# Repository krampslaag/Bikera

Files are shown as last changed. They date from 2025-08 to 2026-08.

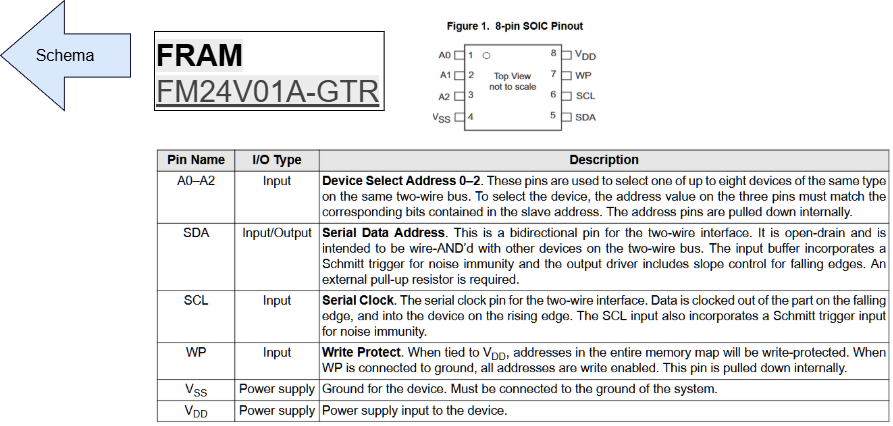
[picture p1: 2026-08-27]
Architectuurschema export png/Architectuur schema-FRAM.drawio.png

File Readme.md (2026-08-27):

# Bikera PCB
Ontwerp van een prototype development board voor een beveiligd IoT-fietsslot
--
Een prototype wordt ontwikkeld in de vorm van een development board met een custom PCB-ontwerp in KiCad. Het doel is een energiezuinig, veilig en uitbreidbaar embedded platform te ontwerpen dat later kan evolueren naar een functioneel eindproduct.
# Componenten:
- Energiezuinige MCU: [STM32L431CCT6TR](https://www.digikey.be/nl/products/detail/stmicroelectronics/STM32L431CCT6TR/8257907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)
- LoRa module (+BLE): [WisDuo RAK11720](https://www.digikey.be/nl/products/detail/rakwireless-technology-limited/RAK11720-8-SM-I/26861631) 
	- Bijhorende LoRa antenne: [FPC antenne](https://be.farnell.com/te-connectivity/l000551-05/rf-antenna-863-to-870mhz-2-2dbi/dp/4457734)
	- Bijhorende BLE antenne: [AANI-FB-0086-0100W (100mm)](https://www.digikey.be/nl/products/detail/abracon-llc/AANI-FB-0086-0100W/25558929)
- ECC secure element: [ATECC608B-SSHDA-T](https://www.digikey.be/nl/products/detail/microchip-technology/ATECC608B-SSHDA-T/13415162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)
- GPS/GNSS module: [Quectel LC76GPAMD](https://www.mouser.be/ProductDetail/Quectel/LC76GPAMD?qs=vvQtp7zwQdMfDuCTmjRUww%3D%3D)
	- Bijhorende antenne: [YFGA003AA](https://www.digikey.be/nl/products/detail/quectel/YFGA003AA/21273116)
- ePaper module: [Waveshare 1.54” module](https://www.waveshare.com/1.54inch-e-Paper-Module.htm)
	%%voor QR codes%%
- Accelerometer: [LIS2DW12 module](https://www.tinytronics.nl/en/sensors/acceleration-rotation/dfrobot-fermion-triple-axis-accelerometer-spi-i2c-lis2dw12)
- SD-kaart module: [SD adapter module](https://www.tinytronics.nl/en/data-storage/modules/sd-card-adapter-module-3.3v-5v)
	%%Voor logging (alleen prototype)%%
- FRAM geheugen: [FM24V01A-GTR](https://www.digikey.be/nl/products/detail/infineon-technologies/FM24V01A-GTR/5210532)
	%%Voor logging%%
- BMS-systeem
	%%voor 2-4 18650 Li-Ion batterijen%%
	- Li-ion protectie en lader (USB-C): [BQ25630YBGR](https://www.digikey.nl/nl/products/detail/texas-instruments/BQ25630YBGR/28738812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)
	- 3.3V buck-boost: [RAA2361052GNP#HC5](https://www.mouser.be/ProductDetail/Renesas-Intersil/RAA2361052GNPHC5?qs=olJun0bQHM%2FTMxAlNSaKDw%3D%3D)
	- 3.3V LDO:[TCR3UG33A,LF](https://www.mouser.be/ProductDetail/Toshiba/TCR3UG33ALF?qs=0lQeLiL1qyaZy60Q7HF0yg%3D%3D)
		%%Voor GPS%%
	- 5V boost: [TPS61253F](https://www.digikey.be/nl/products/detail/texas-instruments/TPS61253FYFFR/29174815)
		%%Voor servomotor%%
- Servo motor: [TD-8120MG Digital Servo](https://www.tinytronics.nl/en/mechanics-and-actuators/motors/servomotors/td-8120mg-waterproof-digital-servo-20kg)
	%%Aangesloten met pinheader%%
- Hall effect sensors: [](https://www.mouser.be/ProductDetail/Texas-Instruments/DRV5032DULPGM?qs=OlC7AqGiEDk9MwfBkgsRPw%3D%3D)[DRV5032DULPGM](https://www.mouser.be/ProductDetail/Texas-Instruments/DRV5032DULPGM?qs=OlC7AqGiEDk9MwfBkgsRPw%3D%3D)
	%%voor slot beugel en pin%%
- Kleurled: [](https://www.digikey.be/nl/products/detail/american-bright-optoelectronics-corporation/BL-BEG204-7-E/22486902)[BL-BEG204-7-E](https://www.digikey.be/nl/products/detail/american-bright-optoelectronics-corporation/BL-BEG204-7-E/22486902)
	%%rood en groen, zonder blauw%%
## BOM
Er wordt een **materiaallijst (BOM)** opgesteld met alle gebruikte componenten in [google sheets](https://docs.google.com/spreadsheets/d/1ZxJHOLqpuJL-1dvZkRNnV-r1_EjUXDaZgLNVo9UeM5s/edit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).

Er staat een **sheet 'Basiscomponenten'** met verschillende opties voor elk component, aangeduid welke voor prototype gebruikt worden en welke voor finaal ontwerp kan gebruikt worden. 

De keuzes voor het prototype zijn overgenomen naar de **sheet 'Componenten'**, waar ook alle randcomponenten zijn toegevoegd. De opmaak gebeurt automatisch en prijzen van Mouser, Digikey en Farnell kunnen via API's opgehaald worden met een script. Ook de status 'niet op voorraad' wordt ge-update waarbij de prijs automatisch roodgekleurd wordt. Vanboven is er een menu Bikera met eigen functies, ook gelinkt aan knoppen.

- [!] Prijzen automatisch updaten duurt lang omdat er te veel requests per minuut zijn waar het script op moet wachten. Nu komt het probleem 'exceeded maximum execution time'. Er mist ook nog een API-key voor Farnell.

Met tag 'alternatief' in de kolom 'type' kunnen verschillende opties voor hetzelfde component van een andere distributeur worden toegevoegd. Opties kunnen worden overgeslagen met de tag 'skip' bij de kolom 'status.' Er wordt automatisch aangeduid met lichtgele vakjes wat er nog moet ingevuld worden, geel waar een dubbele vraagteken in de tekst staat en rood waar een uitroepteken staat. Rijen worden groen gekleurd met de tag 'in KiCad' in kolom 'Status', om te zien welke componenten overeenkomen met het schema.

De componenten worden ook automatsich gedestilleerd in de **sheet 'BOM'**, waarbij gelijke componenten worden opgeteld. Met een knop wordt deze sheet gesorteerd per type.

De **sheet 'Architectuur'** werd gebruikt om het architectuurschema op te stellen en de sheet 'Lijsten' bevat opties voor dropdownmenus.

# Afspraken
- PCB ontwerp in KiCad
- De End-of-Life (EOL) van de componenten mag minimaal nog vijf jaar zijn.
- Prototype = developer board
    - Met debugconnectoren
    - Eerste versie als datalogger
    - Met hand soldeerbare componenten
- RTC
	- Updaten via LoRa
	- Eventueel aparte (oplaadbare) knoopcel
- ECC chip:
	- Met socket
	- ethereum: Keccak-256
	- solana: Ed25519 
- RAK11720 = LoRa +BLE 5, geen bluetooth apart
- Zowel geheugenchip (FRAM) als SD-kaart voor logging
- BMS 
	- Op PCB
	- Lader detecteert USB protocol (2.0, 3.0, USB-C) en past de laadstroom aan.
	- 3.3V buck-boost voor de meeste componenten
	  -> dan kan batterijspanning kan zakken tot 3V
	- 3.3V LDO regulator voor GPS (weinig ruis)
	- 5V boost voor servomotor
- Servomotor
	- aan/uit met enable pin van 5V boost
	- sense weerstand om blokkage overstroom te detecteren
- Hall sensors
	- THT
	- één voor noordpool en één voor zuidpool (beugel en pin) om manipulatie tegen te gaan
- LED
	- Rood + groen -> geel en oranje kan ook gemaakt worden
## Opties voor prototype
- Antenne
	- LoRa & bluetooth: FPC antenne met MHF4 connector
	- Verschillende LoRa antennes testen
	- GPS: FPC antenne 
		- -> kabel proberen solderen
		- anders extra RF-1 connector (quectel GPS heeft RF pinout)
- E-ink module i.p.v. paneel
- SD module
- Accelerometer op breakout bord
- Twee gelijke hall sensors is ok
- RTC updaten via LoRa
- JST PH connectors i.p.v. dupont headers (zelf krimpen)
## Opties voor latere ontwikkelingsfases
- kleinere componenten (reflow soolderen)
- STM32WL als MCU en LoRa radio
- 2 versies: zonder en met bluetooth? (2 RAK lora modules)
- RAK11720: RF pinout versie:
    - Draadantenne: dipool in V-vorm
    - BLE antenne op PCB
- Draadantenne of patch antenne proberen voor GPS
- [NXP EdgeLock SE050](https://www.mouser.be/new/nxp-semiconductors/nxp-edgelock-se050/): meer geavanceerde ECC chip
- Accelerometer chip in plaats van breakout bord
- Unipolaire hall sensors: één voor noordpool en één voor zuidpool (beugel en pin)
- Eventueel aparte (oplaadbare) knoopcel voor RTC (STM32 VBAT)

# Stand van zaken
## In grote lijnen
- [x] Basiscomponenten uitzoeken
- [x] Randcomponenten en deelcircuits
- [ ] Materiaallijst
	- [x] Basiscomponenten (google sheets)
	- [x] Randcomponenten
	- [/] Volledige BOM
- [x] Architectuurdocument
	%%Schema in drawio%%
- [x] KiCad schema
- [ ] KiCad PCB layout
## Componenten uitzoeken
- [x] STM32 *STM32L431CCT6TR*
- [x] LoRa *RAK11720*
- [x] EEC chip *ATECC608B-SSHDA-T*
	- [x] Breakout bord
	- [x] IC voet
- [x] GPS Quectel *LC76GPAMD*
	- [x] Randcomponenten
- [x] BMS
	- [x] li-ion lader *BQ25630YBGR*
		- [x] Randcomponenten
	- [x] 3,3V buck-boost *RT6158AWSC*
		- [x] Randcomponenten
	- [x] 3,3V LDO regulator *TCR3UG33A,LF*
		- [x] Randcomponenten
	- [x] BMS - 5V boost *TPS61253F*
		- [x] Randcomponenten
	- [x] USB-C connector
- [x] Hall effect sensor *DRV5032DULPGM*
- [x] ST-link
	- [x] St-link *STLINK-V3MINIE*
	- [x] Header *009159010603906*
- [x] FRAM *FM24V01A-GTR*
- [x] ePaper *Waveshare 1.54” module*
- [x] Accelerometer *LIS2DW12 module*
- [x] SD-kaart module  *SD adapter module*
- [x] Servo motor *TD-8120MG Digital Servo*
	- [x] Randcomponenten
- [x] LED *BL-BEG204-7-E*
	- [x] Weerstanden
- [x] Alle randcomponenten uitzoeken, opsommen en controleren
- [x] Laatste correcties -> zie gekleurde vakjes op [spreadsheet Componenten](https://docs.google.com/spreadsheets/d/1ZxJHOLqpuJL-1dvZkRNnV-r1_EjUXDaZgLNVo9UeM5s/edit?usp=sharing)
## KiCad
### KiCad schema
- [x] **Symbolen en footprints importeren**
	- **Bestaand**
	- [x] STM32 *STM32L431CCT6TR
	- [x] LoRa *RAK11720*
	- **Gedownload**
	- [x] GPS *Quectel LC76GPAMD*
	- [x] FRAM *FM24V01A-GTR*
	- [x] BMS - li-ion lader *BQ25630YBGR*
	- [x] BMS - 3,3V buck-boost *RT6158AWSC*
	- [x] BMS - 3,3V LDO regulator *TCR3UG33A,LF*
	- [x] Hall effect sensor *DRV5032DULPGM*
	- [x] ST-link header *009159010603906*
	- **Gemaakt**
	- [x] E-ink module *Waveshare 1.54” module*
	- [ ] Accelerometer *LIS2DW12 module*
	- [x] EEC chip *ATECC608B-SSHDA-T*
	- [x] SD-kaart module  *SD adapter module*
	- [x] BMS - 5V boost *TPS61253F*
	- [x] Servo pinheader *Connector_JST:JST_PH_B3B-PH-K_1x03_P2.00mm_Vertical*
	- [x] LED *BL-BEG204-7-E*
- [x] **Pinout uitzoeken**
	- [x] STM32 *STM32L431CCT6TR*
	- [x] LoRa *RAK11720*
	- [x] EEC chip *ATECC608B-SSHDA-T*
	- [ ] GPS Quectel *LC76GPAMD*
		- [x] Beschikbare pinnen
		- [ ] Optionele verbindingen (zie arch.schema)
	- [x] BMS
		- [x] Eerst deelcircuits
		- [x] li-ion lader *BQ25630YBGR*
		- [x] 3,3V buck-boost *RT6158AWSC*
		- [x] 3,3V LDO regulator *TCR3UG33A,LF*
		- [x] 5V boost *TPS61253F*
	- [x] Hall effect sensor *DRV5032DULPGM*
	- [x] ST-link (header) *009159010603906*
	- [x] FRAM *FM24V01A-GTR*
	- [x] ePaper *Waveshare 1.54” module*
	- [x] Accelerometer *LIS2DW12 module*
	- [x] SD-kaart module  *SD adapter module*
	- [x] Servo motor *TD-8120MG Digital Servo*
	- [x] LED *BL-BEG204-7-E*
- [/] **Schema afwerken**
	- [x] Pagina's verdelen
	- 01_power.kicad_sch
		- [x] Componenten importeren
		- [x] Verbindingen
		- [x] Footprints in orde
		- [x] Gecontroleerd
		- [x] Herschikt
	- 02_mcu.kicad_sch
		 - [x] Componenten importeren
		 - [x] Verbindingen
		 - [x] Footprints in orde
		 - [x] Gecontroleerd
		 - [ ] Herschikt
	- 03_auxillery.kicad_sch
		 - [x] Componenten importeren
		 - [x] Verbindingen
		 - [x] Footprints in orde
		 - [!] Accelerometer footprint
		 - [x] Gecontroleerd
		 - [x] Herschikt
### KiCad PCB layout
- [ ] Strategie uitzoeken (PCB afmetingen, lagen, ground plane, trace width...)
- [ ] Componenten plaatsen
- [ ] Verbindingen
## Realisatie
- Componenten bestellen
- PCB bestellen
- Reflow hot plate zoeken & bestellen/maken
- Solderen
- Testen
- Software ontwikkelen, itereren,...

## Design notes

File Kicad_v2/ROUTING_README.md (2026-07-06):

# Bikera devboard — routing session (2026-07-06)

## What happened
Continued from the 2026-07-05 generated layout. Your two schematic fixes (H3.12,
J7.3→pin 7) were verified present in the saved PCB; U9's open RF pins are fine
(MHF4 on module). The stale `.net` export doesn't matter — the PCB is ground truth.

## Files
| File | What |
|---|---|
| `Bikera PCB devboard_ROUTED.kicad_pcb` | **The routed board** (your saved board + 1386 tracks + 179 vias). Original `Bikera PCB devboard.kicad_pcb` untouched. |
| `Bikera PCB devboard.kicad_pro` | Net classes re-added (they had been lost): Default/Power/BATT/HighSpeed_RF/USB/Plane + 24 patterns. Default clearance now **0.15 mm**. |
| `Bikera PCB devboard.kicad_dru` | Amended: RF width rule now 0.45–0.95 (opt 0.5), WCSP neck-down exceptions for IC2/U1/U2/U4 courtyards. |
| `routed_top.png` / `routed_bottom.png` | Renders of the routed state. |

**To adopt:** open `..._ROUTED.kicad_pcb`, check it, then Save-As over the main
board file (or rename). Fill zones (B) before DRC.

## What is routed
- GND / +3V3 served by In1/In2 planes: every SMD pad stitched with a via (or
  bridged to a nearby plane-connected point); TH pads connect via zone fill.
- WCSP fan-outs (IC2 charger, U1 buck-boost, U2 GPS LDO, U4 boost): same-net ball
  clusters linked, perimeter escapes + radial flares, all 0.4 mm pitch.
- GPS RF feed (U6 → R28/C50/C49/D3 → AE1) on F.Cu, no vias, 0.5 mm wide.
- USB D+/D− (J1 → U7 ESD), +BATT (0.5 mm), power rails (0.35 mm), most signals.

## ⚠ Deliberate deviations
1. **RF feed is 0.5 mm, not the anchors' 0.9 mm.** A 0.9 mm trace cannot attach to
   the 0402 matching network (pads 0.5 mm wide, 1 mm apart) without gross clearance
   violations — the original 0.9 spec is geometrically unsatisfiable there. At
   ~4 mm total feed length the impedance penalty at 1.575 GHz is negligible for RX.
   The `.kicad_dru` and net class were updated to match.
2. **Default clearance 0.15 mm** (was 0.2). Any 4-layer fab handles this (JLC min
   0.09). Needed to fan out the 0.5 mm QFP and 0.4 mm WCSPs.
3. **IC2 balls E4 (TS) and C2 (CHRG_PG)** exit through ~0.05 mm-clearance squeeze
   corridors between balls — unavoidable on a full-matrix 0.4 mm WCSP without
   microvias. Covered by a dru exception inside the courtyards; **confirm your fab
   accepts it or plan to tweak by hand.**

## Update (second pass, same day)
A fine-grid repair pass added the missing +VBUS, GPS_RX, SW-node (C7 snubber),
LORA_BOOT/RX and USB-DN links. An exact-geometry audit then found the automated
router had created several **near-shorts** (traces tunnelling through pad
boundaries — a raster bug); all affected nets were ripped up and rerouted with a
corrected model. **The shipped board now has zero clearance violations outside
the documented WCSP squeeze zones** (verified via-pad / seg-pad / seg-seg at
≥0.09 mm everywhere else).

## ⚠ Still unrouted (~32 nets have a missing link; ratsnest will show them)
Power: +5V, +SYS (2 links), Net-(L2-Pad1/2) (**U1↔L2 buck inductor — must be
routed before power-up**), Net-(D1-K2), one +3V3 cap (C47), one GND cap (C15)
Charger satellites: CHRG_CE/INT/PG, Net-(IC2-TS) (TH1/R8/R9), VBAT_SENSE
Buses/signals: I2C_SCL/SDA branches, SPI1_SCK/MOSI branches, SD_CS, GPS_RESET
(fully open — SW1/R20/C16 chain), GPS_EN, EN_5V_SERVO, EPAPER_CS/RST/BUSY,
LORA_RESET, SWO/SWCLK, ACCEL_INT1, RED/GRN LED, SERVO_RSENSE, HALL_PIN/HALL_BEUGEL.

These sit in the two saturated zones (U3 QFP perimeter, IC2/U1 power cluster).
KiCad's push-and-shove router handles them interactively — it can shove existing
tracks aside, which my router cannot. Expect ~30–45 min by hand.

## Suggested order next
1. Open ROUTED board, **fill zones (B)**, run DRC with the .kicad_dru loaded.
2. Route the ratsnest leftovers (push-and-shove, 0.15 clearance).
3. Re-check the two IC2 squeeze corridors and the RF feed width decision.
4. Hall sensors IC1/IC3 are still edge placeholders — you said route anyway;
   re-route their two nets if you move them.

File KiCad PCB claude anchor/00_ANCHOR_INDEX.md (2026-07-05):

# BIKERA PCB LAYOUT ANCHOR NOTE — MASTER INDEX

## Purpose
This is a **minimal, token-efficient dataset** extracted from your Bikera project files for automated KiCad PCB layout generation using a deep-thinking model (Claude Fable).

**Key principle**: All four pillars are compressed into dense markdown, designed to be pinned as cached context in an LLM. Avoids re-parsing KiCad files, BOM spreadsheets, and schematics on each layout iteration.

---

## 4 PILLARS (Read in Order)

### **01_ANCHOR_GEOMETRY.md** — Board Outline, Mounting, Fixed Components
- Board dimensions (50×30 mm), layer count (4), layer stack assignment
- Mounting holes (4× M3, corner positions with exact X/Y coordinates)
- Fixed connectors & mechanical: USB-C, JST-PH battery, SD-card header, antenna connectors
- Restricted zones (RF keep-outs, digital/analog separation, thermal zones)
- Decoupling capacitor proximity rules (distance from IC pin to bypass cap, critical for power integrity)
- Power distribution summary and critical path rules (trace width, via count)
- Net classes baseline (Default, Power, HighSpeed, Diff-Pair; via sizes & clearances)

**Use this to**: Establish the physical PCB template, define placement zones (A–E), allocate space for connectors.

---

### **02_ANCHOR_CLUSTERS.md** — Component Functional Groups & IC Proximity
- **9 functional clusters** (MCU, Power, LoRa, GPS, ECC, Accelerometer, Storage, LED, Test Points)
- Each cluster lists:
  - Primary IC reference designator & package
  - Bypass capacitor part numbers & values
  - Max distance rules (≤5mm, ≤3mm, ≤2mm cap-to-pin)
  - Support components (resistors, ferrite beads, diodes, buttons)
  - Critical routing constraints (SPI shielding, isolated power domains, etc.)
  - Suggested PCB placement coordinates (approximate)
- Summary table: IC → Cap → Max Distance mapping (quick reference)

**Use this to**: Place components relative to each other, cluster decoupling caps immediately around each IC, enforce power domain isolation (e.g., +3V3_GPS separate until star-point).

---

### **03_ANCHOR_NETLIST.md** — Critical Nets Only (Power, High-Speed, Differential)
- **Power nets** table: +3V3, +3V3_GPS, +5V, +BATT, +SYS, GND; voltage, source, destination, routing strategy
- **I²C bus** (MCU ↔ ECC, sensors, GPS):
  - SDA_I2C1 & SCL_I2C1 nets
  - Pin mappings (U3.PB9, U3.PB8)
  - Pull-up resistor placement (4.7K, ≤10mm from MCU)
  - Length limits (≤100mm), shielding guidance
- **SPI bus** (MCU ↔ LoRa, optionally GPS):
  - SPI1_MOSI, SPI1_MISO, SPI1_CLK, SPI1_CS nets
  - Pin mappings, length limits (≤50mm), GND shielding strategy
- **UART** (MCU ↔ GPS telemetry):
  - UART1_RXD / UART1_TXD nets
  - Low-speed, flexible routing (≤100mm stubs)
- **Antenna RF traces** (50Ω controlled impedance):
  - ANT_LoRa (≤10mm, 0.9mm width, 10mm keep-out zone)
  - ANT_GPS (≤8mm, 0.9mm width, 8mm keep-out zone)
- **GND return paths**: L2 plane continuity, star-point convergence, via-stitching rules
- **Net class assignment table**: Which net class each critical net belongs to

**Use this to**: Route power, data, and RF traces. Implement length rules, impedance targets, and shielding. Enforce antenna keep-out zones.

---

### **04_ANCHOR_NETCLASSES.md** — Design Rules & Constraints by Net Class
- **6 net classes defined**:
  1. Default (GPIO, low-speed logic) — 0.2mm track, 0.2mm clearance, 0.6mm via dia
  2. Power (+3V3, +5V, +BATT) — 0.5mm track, 0.25mm clearance, 0.8mm via dia
  3. HighSpeed_SPI (LoRa/GPS SPI) — 0.2mm track, GND shielding every 2–3mm
  4. HighSpeed_I2C (ECC/GPS/Accel I²C) — 0.2mm track, 4.7K pull-ups at MCU, ≤100mm bus length
  5. HighSpeed_RF (ANT_LoRa, ANT_GPS, 50Ω) — 0.9mm width, 10mm/8mm keep-outs, via-stitched GND returns
  6. GND (L2 continuous plane) — 95% board coverage, antenna exclusions, star-point return
- **Layer assignment** (L1 signals, L2 GND plane, L3 power plane, L4 signals/power distribution)
- **Impedance calculation** (50Ω target for RF: 0.9mm trace width on 0.2mm L1–L2 spacing)
- **Manufacturing specs** (1.6mm FR-4, 1oz copper, 6mil min trace/space, solder mask both sides)
- **DRC checklist** (clearance, trace width, via rules; antenna keep-outs manual inspection)
- **Validation checklist** (pre-fabrication sign-off tasks)

**Use this to**: Apply DRC rules in KiCad, assign net classes to each net, measure final trace impedances (RF critical), approve board for fabrication.

---

## HOW TO USE WITH FABLE (Deep-Thinking Model)

### **Workflow**
1. **Pinned Context** (token-efficient):
   - Save this anchor note set as 4 short markdown files (each ≤15KB)
   - In your deep-thinking prompt, include these files as cached context ("pin" or "remember" in the system message)
   - Each file is independently useful; together they define the complete layout constraint set

2. **Fable Prompt Template**:
   ```
   # TASK: Auto-generate KiCad PCB layout for Bikera devboard
   
   **CONTEXT (cached, these 4 files):**
   - 00_ANCHOR_INDEX.md (this file)
   - 01_ANCHOR_GEOMETRY.md
   - 02_ANCHOR_CLUSTERS.md
   - 03_ANCHOR_NETLIST.md
   - 04_ANCHOR_NETCLASSES.md
   
   **INPUTS:**
   - Schematic netlist: [paste KiCad netlist.net export]
   - Component footprints: [paste list of references + footprint names]
   
   **TASK:**
   Generate a KiCad layout (.kicad_pcb file) that:
   1. Places components in clusters A–E (01_ANCHOR_GEOMETRY)
   2. Routes all critical nets per 03_ANCHOR_NETLIST
   3. Applies design rules from 04_ANCHOR_NETCLASSES
   4. Enforces antenna keep-out zones (10mm LoRa, 8mm GPS)
   5. Implements GND star-point at (44mm, 5mm)
   6. Reports any DRC violations found
   
   **CONSTRAINTS:**
   - Board: 50×30 mm, 4-layer
   - Minimize trace length (SPI ≤50mm, I²C ≤100mm)
   - Keep decaps ≤5mm from IC VDD pins
   - RF traces 50Ω impedance (0.9mm width on L1)
   ```

3. **Fable Output**:
   - `.kicad_pcb` file (human-readable, text-based KiCad layout format)
   - Trace dump report (success/failures for each net)
   - DRC violations (if any)

4. **Manual Review**:
   - Import generated `.kicad_pcb` into KiCad PCBnew
   - Run KiCad's DRC (target: 0 errors)
   - Visually inspect antenna keep-outs, GND plane continuity, trace routing
   - Iterate with Fable if needed ("move component X to (10, 15); re-route SPI bus")

---

## QUICK REFERENCE

### Cluster Placement (Zones)
| Zone | X range (mm) | Components | Purpose |
|---|---|---|---|
| A | 0–15 | U3 (MCU), SW1, SW2, C14/C15/C16 (decaps) | Core MCU and logic |
| B | 15–32 | U6 (GPS), U5 (ECC), accel breakout, C29/C30, C27 | Sensors & crypto |
| C | 32–42 | U9 (LoRa), C37/C38/C39, MHF4 antenna | RF module |
| D | 42–50 | JST-PH, BMS chips (RT6158A, BQ25630), LDO, C41 (bulk) | Power management |
| E | Y≤5mm | USB-C, SD-card header | Connectors |

### Critical Distances
- **MCU VDD caps**: ≤5mm pad-to-pin (C14/C15/C16 to U3 VDD pins)
- **MCU VDDA caps**: ≤3mm pad-to-pin (C17/C18/C40 to U3 VDDA pins)
- **LoRa VDD caps**: ≤4mm (C37/C38/C39 to U9 VDD)
- **GPS VDD/V_BCKP caps**: ≤4mm (C29/C30 and C33/C34 to U6 pins)
- **I²C pull-ups**: ≤10mm from MCU I²C pins (U3.PB8/PB9)

### Antenna Keep-Outs (No GND Plane)
- **LoRa MHF4**: 10mm radius, center at MHF4 connector pad
- **GPS FPC**: 8mm radius, center at FPC connector pad

### Power Star-Point
- **Location**: (44mm, 5mm) — bulk cap cluster bottom-right
- **Convergence**: All power IC returns (BMS, LDO, charger) via multi-via (≥5× 0.3mm vias) to L2 GND plane
- **Fan-out**: From star-point, +3V3 and +3V3_GPS trees radiate upward/leftward to MCU and LoRa clusters

### Net Classes (Summary)
| Class | Track Width | Clearance | Via Dia | Key Nets |
|---|---|---|---|---|
| Default | 0.2 | 0.2 | 0.6 | GPIO, buttons, LED, debug |
| Power | 0.5 | 0.25 | 0.8 | +3V3, +BATT, +5V, +SYS |
| SPI | 0.2 | 0.2 | 0.4 | SPI1_MOSI/MISO/CLK/CS |
| I²C | 0.2 | 0.2 | 0.5 | I2C_SDA/SCL |
| RF | 0.9 | 0.5 | 0.4 | ANT_LoRa, ANT_GPS (50Ω) |
| GND | N/A (plane) | 0.2 (edge) | 0.3 | L2 continuous plane |

---

## FILE LOCATIONS
All files saved to: `D:\Obsidian git\AI\AI collaboration\KiCad PCB anchor`

```
00_ANCHOR_INDEX.md                 ← You are here
01_ANCHOR_GEOMETRY.md              ← Board outline, zones, connectors
02_ANCHOR_CLUSTERS.md              ← Component grouping, cap proximity
03_ANCHOR_NETLIST.md               ← Critical nets (power, SPI, I²C, RF)
04_ANCHOR_NETCLASSES.md            ← Design rules, trace widths, clearances
Bikera PCB devboard.net
```

---

## MAINTENANCE & UPDATES

**If you change the schematic (add/remove components)**:
1. Re-extract the component list from `D:\Obsidian git\AI\AI collaboration\Files\Bikera.xlsx` sheet "Componenten"
2. Update clusters in `02_ANCHOR_CLUSTERS.md` (add/remove ICs and caps)
3. Update net names in `03_ANCHOR_NETLIST.md` (grep the new `.kicad_sch` files)
4. Re-run KiCad DRC to validate net classes in `04_ANCHOR_NETCLASSES.md`

**If you change the board size or layer count**:
1. Update board dimensions in `01_ANCHOR_GEOMETRY.md`
2. Recalculate RF trace width (0.9mm assumes 4-layer with 0.2mm L1–L2 spacing; may differ for 2-layer or 6-layer)
3. Adjust zones (A–E) accordingly

**If you add RF modules (e.g., BLE antenna on 2.4 GHz)**:
1. Add new RF net class to `04_ANCHOR_NETCLASSES.md` (e.g., HighSpeed_RF_2400MHz with tighter tolerance)
2. Document antenna keep-out zone (smaller for higher frequency)
3. Add to `03_ANCHOR_NETLIST.md` netlist

---

## NEXT STEPS

1. **Immediate**: Share these 4 anchor files (00–04) with Fable as cached context
2. **Short-term**: Export KiCad netlist (File → Export → Netlist), pass to Fable with anchor files
3. **Layout generation**: Fable generates `.kicad_pcb` file; import into KiCad PCBnew
4. **Validation**: Run DRC, inspect antenna zones, verify GND plane continuity
5. **Iteration**: If Fable-generated layout has issues, adjust anchor constraints and re-generate

---

**Created**: 2026-07-05  
**Project**: Bikera PCB devboard (50×30 mm, 4-layer, STM32L431 + LoRa + GPS)  
**Target Tool**: KiCad 10.0 (or later)  
**Model**: Claude Fable 5 (deep-thinking, layout generation)  

---

## NOTES FOR FABLE

When generating the layout:
- **Respect zones**: Don't place MCU (U3) in Zone C or D; keep it in Zone A
- **Antenna isolation**: Treat 10mm/8mm keep-outs as hard constraints; no exceptions
- **Power first**: Route +BATT → BMS → LDO → bulk cap → MCU before routing signals
- **Layer assignment**: All SPI on L1; I²C can flex to L4 via vias if needed; RF never leaves L1
- **Via-stitching**: Implement along SPI traces (GND via every 2–3mm for shielding)
- **Report each stage**: After placement, after power routing, after signal routing—so we can catch issues early

---

**Good luck with the layout!** 🎯

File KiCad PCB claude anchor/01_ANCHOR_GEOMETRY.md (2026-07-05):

# BIKERA PCB LAYOUT ANCHOR NOTE
## Step 1: Compact Board Geometry

**BOARD OUTLINE & LAYERS**
- Dimensions: 50.0 mm (W) × 30.0 mm (H)
- Layer stack: 4 layers (FR4, standard)
- Layer assignment: L1 (top signal), L2 (inner GND plane), L3 (inner power), L4 (bottom signal)
- Origin: (0,0) at bottom-left corner (KiCad standard)

**MOUNTING HOLES (M3, plated through)**
- TL: (2.5, 27.5)
- TR: (47.5, 27.5)
- BL: (2.5, 2.5)
- BR: (47.5, 2.5)
- Hole diameter: 3.2 mm (M3 clearance), pad ~4.5 mm

**CONNECTORS & FIXED MECHANICAL (Position | Function | Notes)**
- **USB-C (Bottom edge, 50-30 boundary)**: Charging + data. Header at Y≈2mm. Centered X.
- **JST-PH (Battery input)**: X≈5mm, Y≈5mm. 2-pin, vertical orientation preferred for low profile.
- **SD-Card Module Header**: Edge placement (parallel to board edge, prefer bottom or left edge). Header pins at 2.54mm pitch.
- **LoRa Antenna (MHF4 connector)**: U9 (RAK11720) footprint defines position. Reserve antenna keep-out: 5mm clearance minimum from board edge.
- **GPS Antenna Connector**: U6 (Quectel LC76GPAMD). FPC connector, ~10–15mm cable. Position TBD in layout (typically near opposite edge from LoRa).
- **BLE Antenna (FPC, 10cm)**: Abracon AANI-FB-0086. Flexible placement on side.

**TEST POINTS**
- Required per thesis: VDD test points for critical power rails
- Placement: Clustered near bulk capacitors or IC power pins
- Suggested positions: Near U3 (MCU), U9 (LoRa), U6 (GPS), BMS ICs
- Size: 0.8 mm–1.0 mm via pads for probe access

**RESTRICTED ZONES**
1. **RF Keep-outs** (50 Ω antenna traces, no digital noise):
   - LoRa antenna (MHF4) → antenna route: min 2mm traces, keep-out 10mm radius around connector foot
   - GPS antenna → separate 50 Ω stub, keep-out 8mm radius
2. **Digital/Analog Separation**:
   - Analog ground island (GPS, sensors) isolated until single point at bulk GND plane
   - MCU digital side (left half) ⊥ RF/analog side (right half)
3. **Battery & High-Current Paths**:
   - JST-PH traces: low inductance, thick (>0.5mm), direct to BMS
   - USB charging path: short, isolated from signal layers until PD controller
4. **Thermal zones**:
   - Avoid component placement directly above/below voltage converter (BMS) if heat dissipation ≥0.5W
   - Leave ~10mm air gap if needed

**DECOUPLING CAP PROXIMITY REQUIREMENTS**
- **STM32L431 (U3, LQFP-48)**:
  - VDD caps (3×100nF C14/C15/C16, 1×4.7µF C41): ≤5mm pad-to-pin distance
  - VDDA caps (1µF C17, 10nF C18, 100nF C40): ≤3mm to analog pins
  - Ferrite bead FB1 on VDDA: inline, ≤2mm before MCU
- **RAK11720 (U9, MHF4 breakout)**:
  - VDD caps (10µF C37, 1µF C38, 100nF C39): ≤4mm cluster near breakout pads
- **Quectel LC76GPAMD (U6)**:
  - VCC caps (10µF C29, 100nF C30, 33pF C31): ≤4mm cluster
  - V_BCKP caps (4.7µF C33, 100nF C34): ≤3mm cluster
- **ATECC608B (U5, SOIC-8)**:
  - 100nF C27: ≤2mm pad-to-pin

**POWER DISTRIBUTION SUMMARY**
- **+3V3** (main digital): LDO regulated, routes to MCU, LoRa, GPIO peripherals
- **+3V3_GPS**: Isolated LDO for GPS/GNSS module (low-noise requirement)
- **+5V**: USB input or boost output (if needed for future modules)
- **+BATT** (raw battery ~3.7–4.2V from JST): BMS input, high-current sense point
- **+SYS**: Post-BMS regulated (derived from +3V3 or isolated converter)
- **GND**: Single-point star at bulk cap cluster, radiates to layer 2 (ground plane)

**CRITICAL PATHS (minimum width/via rules)**
- Battery input & charging: 0.5mm+ (≥2A expected)
- Power distribution (+3V3, +5V): 0.35mm+ (multi-via at source)
- Signal high-speed (SPI to GPS/LoRa): 0.2mm, 50 Ω where diff-pair used
- Standard signal: 0.2mm
- Ground vias: 0.3mm drill minimum, cluster 5–10 vias per power source

**NET CLASSES (from KiCad .kicad_pro)**
- **Default**: Track 0.2mm | Clearance 0.2mm | Via Ø0.6mm / drill 0.3mm
- **Power**: (assign if needed) Track 0.5mm | Clearance 0.25mm | Via Ø0.8mm / drill 0.4mm
- **HighSpeed**: (for GPS/LoRa SPI) Track 0.2mm | Clearance 0.2mm | Via Ø0.4mm / drill 0.2mm
- **Diff-Pair**: Width 0.2mm | Gap 0.25mm | Via Ø0.4mm

**COMPONENT PLACEMENT ZONES (Spatial allocation)**
- **Zone A (Left, 0–15mm X)**: MCU U3 (LQFP-48 center), Reset button SW1, Boot button SW2, MCU decoupling caps
- **Zone B (Center-Left, 15–32mm X)**: ECC chip U5 (SOIC-8), GPS module U6, GPS caps, ferrite bead FB1
- **Zone C (Center-Right, 32–42mm X)**: LoRa module U9 (RAK11720), LoRa caps C37/C38/C39, pullup/pulldown resistors (R24, R25)
- **Zone D (Right, 42–50mm X)**: Battery connector (JST-PH), resistor divider (R18/R19 for VBAT_SENSE), bulk caps
- **Zone E (Bottom edge, Y ≤ 5mm)**: USB-C connector, SD-card module header
- **Antennas**: FPC feed-through at edges, preferably top edge LoRa, bottom/right edge BLE/GPS

---

**DESIGN NOTES FOR LAYOUT TOOL**
- Fab spec: PCBWay/JLCPCB/Eurocircuits (standard 4-layer, 1.6mm FR-4)
- Min trace/space: 6/6 mil (0.15mm) conservative for 4-layer
- Via tenting: solder mask both sides for reliability
- Silkscreen: Reference designators (0.8mm text), layer indicators
- Edge clearance: Keep traces ≥0.5mm from board edge (except connectors)
- Solder mask: No mask between fine-pitch pads (QFP, SOIC) for reflow control

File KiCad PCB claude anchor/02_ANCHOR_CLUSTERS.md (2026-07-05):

# BIKERA PCB LAYOUT ANCHOR NOTE
## Step 2: Component Functional Clusters

**CLUSTER ORGANIZATION BY SCHEMATIC SUBSYSTEM**

---

### CLUSTER A: STM32L431 MCU & CORE SUPPLY (Zone A: X=0–15mm)
**Primary IC**: U3 (STM32L431CCT6TR, LQFP-48)
**Bypass Capacitors** (must be ≤5mm from VDD pins, ideally ≤3mm pad-to-pad):
- C14, C15, C16: 100nF 0603 (VDD decoupling, 3× for three separate VDD pins)
- C41: 4.7µF 0603 (bulk VDD, C41 closest)
- C17: 1µF 0603 (VDDA analog supply)
- C18: 10nF 0603 (VDDA anti-alias)
- C40: 100nF 0603 (VREF, technically VDDA)

**Ferrite Bead**: FB1 (BLM18KG601SN1D, 600Ω@100MHz, 0603) — inline between +3V3 and VDDA, ≤2mm before C17

**Support Components**:
- R17: 10K pulldown (Boot button SW2)
- R18, R19: 220K/100K resistor divider (VBAT_SENSE → MCU PA0)
- C28: 10nF anti-alias on VBAT_SENSE input
- C19: 100nF (Reset circuit)
- SW1: Reset button (SPST momentary 6×6mm THT)
- SW2: Boot button (SPST momentary 6×6mm THT)

**Critical Routing**:
- Boot/Reset buttons: low-noise, keep signal traces ≥0.3mm away from high-speed digital
- VBAT_SENSE: run on L1 or L4 (bottom), shield with ground plane nearby (L2)
- VSS (Ground) pins: multi-via (≥5 vias) direct to L2 ground plane

**PCB Placement Strategy**:
- U3 center at ~(7.5mm, 15mm)
- Decap cluster surrounds all four sides (top, bottom, left, right)
- C41 (bulk) on bottom side of PCB, ≤5mm from U3
- C14/C15/C16 distributed around U3 pads (one per physical VDD cluster)
- Buttons on left edge, well away from sensitive analog traces

---

### CLUSTER B: POWER MANAGEMENT & CHARGING (Zone D: X=42–50mm)
**Primary ICs** (from thesis & BOM):
- BMS system: RT6158A (buck-boost converter)
- Charger: BQ25630YBGR (USB-C PD-aware, 1-cell 5A charger)
- LDO: TCR3UG33A (300mA low-dropout for +3V3)

**Bulk Capacitors** (≤5mm from IC pin):
- Input filter (after JST-PH connector): 10–47µF 0603–1210, ceramic X5R
- RT6158A output: 47–100µF 1206 (bulk), ≤4mm from output pin
- BQ25630 VDD: 10µF 0603 (bus decoupling)
- LDO output: 10µF 0603 (bulk), ≤3mm from LDO output pin

**Charging Path**:
- USB-C connector → BQ25630 (USB PD controller)
- BQ25630 output → 1–2Ω sense resistor → RT6158A input
- RT6158A → regulated +3V3_MAIN bus

**High-Current Traces** (≥0.5mm width minimum):
- JST-PH to BMS: use L4 (bottom layer) if possible, or L1 with heavy via array
- BMS output to LDO: thick traces or wide copper
- +3V3 distribution: 0.35mm typical, but multi-layer routing preferred

**Diodes & Protection**:
- TVS diodes on USB VBUS (if ESD protection needed)
- Load-sharing diodes between battery and USB (TBD in schematic)

**PCB Placement Strategy**:
- BMS cluster at bottom-right corner (high-current node)
- JST-PH connector at (5mm, 2.5mm) — bottom edge, left of center
- RT6158A at ~(45mm, 5mm)
- BQ25630 at ~(47mm, 12mm)
- TCR3UG33A LDO at ~(42mm, 18mm)
- All three in a line with short interconnects

---

### CLUSTER C: LoRa RADIO (RAK11720, Zone C: X=32–42mm)
**Primary IC**: U9 (RAK11720-8-SM-I, MHF4 connector for antenna)
**Bypass Capacitors** (≤4mm from U9 pads):
- C37: 10µF 0603 (bulk VDD)
- C38: 1µF 0603 (intermediate)
- C39: 100nF 0603 (local decap)

**Support Components**:
- R24: 10K pullup (#RST pin)
- R25: 10K pulldown (SWO debug line)
- Antenna: MHF4 connector breakout, 50Ω trace to antenna pad

**Critical Routing**:
- VDD rail: isolated until joins main +3V3 at bulk cap
- Antenna feed: 50Ω impedance controlled, min 2mm trace width
- SPI interface (MOSI/MISO/CLK to MCU): run on L1, shield with GND vias
- Antenna pad: keep-out 10mm radius (no GND plane directly below until >15mm away)

**PCB Placement Strategy**:
- U9 at ~(37mm, 18mm) (right-center)
- C37/C38/C39 cluster immediately adjacent (below on L4 preferred)
- MHF4 connector on top or bottom right edge, with FPC routing to off-board antenna
- SPI traces to MCU: L1 top layer, minimum etch

---

### CLUSTER D: GPS/GNSS (Quectel LC76GPAMD, Zone B: X=15–32mm)
**Primary IC**: U6 (Quectel LC76GPAMD, UART/SPI interface)
**Bypass Capacitors** (≤4mm from U6 pads):
- C29: 10µF 0603 (VCC bulk)
- C30: 100nF 0603 (VCC bypass)
- C31: 33pF 0603 (oscillator/tank)
- C33: 4.7µF 0603 (V_BCKP backup supply)
- C34: 100nF 0603 (V_BCKP bypass)

**Support Components**:
- TVS diode (SMBJ5.0CA or similar, if not already in module)
- Antenna connector (GPS FPC or SMA, separate from LoRa)

**Critical Routing**:
- VCC and V_BCKP: separate power domains, only join at bulk cap
- UART (RXD/TXD) or SPI to MCU: standard signal integrity (0.2mm traces, ≤10pF capacitance)
- GPS antenna: 50Ω stub trace, keep-out 8mm radius from pad (no GND plane immediately adjacent)

**PCB Placement Strategy**:
- U6 at ~(25mm, 12mm) (center-left)
- C29/C30/C31 cluster on bottom side near U6
- C33/C34 (V_BCKP) cluster slightly away (~5mm), since backup supply is separate
- Antenna connector on top edge, with FPC routing

---

### CLUSTER E: CRYPTOGRAPHIC ELEMENT (ATECC608B, Zone B: X=15–32mm)
**Primary IC**: U5 (ATECC608B-SSHDA-T, SOIC-8)
**Socket Option**: DIP-8 socket (1-2199298-2) for swappable ECC development

**Bypass Capacitors** (≤2mm from U5 pads):
- C27: 100nF 0603 (VCC decoupling)

**Support Components**:
- DIP-8 socket pads if breakout used
- I²C pull-up resistors (≤5mm from MCU, not at ECC itself — usually in MCU cluster)

**Critical Routing**:
- I²C bus (SDA/SCL): low-noise, 50Ω approximate, short stubs <5mm
- VCC: isolated until bulk cap
- No high-speed digital nearby (keep RF/SPI traces ≥10mm away)

**PCB Placement Strategy**:
- U5 at ~(20mm, 10mm) (left-center, separate from LoRa noise)
- C27 directly adjacent (same side as decap)
- I²C traces routed on L1, then down via to MCU on L4
- Socket option: if populated, use DIP-8 adapter + IC socket for reliability

---

### CLUSTER F: ACCELEROMETER (LIS2DW12, Zone A or B)
**Primary IC**: Tinytronics breakout module (LIS2DW12, I²C or SPI)
**Bypass Capacitors**: (module likely includes own decap, but check):
- 10µF + 100nF cascade if bare chip used

**Critical Routing**:
- I²C (SDA/SCL) or SPI: short, ≤5pF trace capacitance
- INT pins: run to MCU GPIO on L1, shield with GND

**PCB Placement Strategy**:
- Keep accelerometer ≤30mm from mechanical center (for accurate motion sensing)
- Breakout module on L1 surface, leave ≥10mm clearance around for motion freedom
- Suggested position: ~(10mm, 8mm) (near MCU, lower-left)

---

### CLUSTER G: STORAGE (SD-Card Module & FRAM)
**SD-Card Module Header**:
- 6–7 pin SPI interface (MOSI/MISO/CLK/CS/GND/+3V3)
- Placed at board edge (Y ≤ 3mm or at left edge)
- Breakout header format (requires external adapter)

**FRAM** (F-RAM FM24V01A, if populated):
- I²C interface (SDA/SCL + VCC + GND)
- 100nF decap immediate
- Placement: ~(12mm, 6mm), near MCU I²C bus

**Critical Routing**:
- SD card SPI: L1 only, clock traces carefully routed (min jitter)
- FRAM I²C: shared bus with ATECC608B, pull-ups at MCU cluster

---

### CLUSTER H: LED INDICATOR & GPIO
**LED** (BL-BEG204-7-E, common-cathode red-green THT):
- Anode pins to GPIO (via strobing/PWM)
- Cathode to GND through current-limiting resistor (e.g., 100–330Ω 0603)
- Placement: ~(3mm, 28mm) (top-left corner, visible when assembled)

**GPIO Resistor Network** (if used):
- Pull-ups/pull-downs for external buttons or sensors: collocate near associated GPIO pin

---

### CLUSTER I: TEST POINTS
**Location & Purpose**:
- **TP_+3V3**: bulk cap cluster, left side Y≈20mm
- **TP_+3V3_GPS**: GPS LDO output, Y≈12mm
- **TP_+SYS**: backup/sys rail, Y≈8mm
- **TP_GND**: multiple GND vias (e.g., Y≈5mm, Y≈25mm)
- **TP_VBAT_SENSE**: resistor divider node, ~(45mm, 18mm)

**Via Probe Format**: 0.8–1.0mm diameter vias, exposed on both L1 & L4 for oscilloscope/multimeter probes

---

## SUMMARY TABLE: CRITICAL CAP-TO-IC DISTANCES

| IC | Ref | Pin Type | Cap Ref | Value | Max Distance (mm) | Placement |
|----|-----|---|---|---|---|---|
| U3 | STM32L431 | VDD | C14/C15/C16 | 100nF | ≤5 | Surrounding pads |
| U3 | STM32L431 | VDD | C41 | 4.7µF | ≤5 | L4 underside |
| U3 | STM32L431 | VDDA | C17/C18/C40 | 1µF/10nF/100nF | ≤3 | Adjacent, L1 top |
| U9 | RAK11720 | VDD | C37/C38/C39 | 10µF/1µF/100nF | ≤4 | Cluster L4 |
| U6 | Quectel GPS | VCC | C29/C30 | 10µF/100nF | ≤4 | L4 cluster |
| U6 | Quectel GPS | V_BCKP | C33/C34 | 4.7µF/100nF | ≤4 | Separate ≥5mm away |
| U5 | ATECC608B | VCC | C27 | 100nF | ≤2 | L1 adjacent |

---

**DESIGN DECISIONS EMBEDDED**
1. **Analog/Digital separation** via placement: Sensors (GPS, accel) on left; RF (LoRa) on right
2. **Power distribution**: Star-point bulk cap at bottom-right → radiates upward to MCU, sideways to LoRa
3. **Signal layers**: L1 (top) for all high-speed digital (MCU, LoRa SPI); L4 (bottom) for power return paths & GND vias
4. **Thermal**: No active heat dissipation required (all ICs <500mW); use standard SMD layout practices

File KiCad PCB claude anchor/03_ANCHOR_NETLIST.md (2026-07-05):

# BIKERA PCB LAYOUT ANCHOR NOTE
## Step 3: Minimal Netlist (Critical Nets Only)

**SCOPE**: Power distribution, high-speed data interfaces, and differential pairs only. Excludes standard GPIO and debug nets.

---

## POWER NETS (Global Labels, Routed on L2/L3 Planes & Dedicated Traces)

### Primary Power Rails
| Net | Voltage | Source | Destination | Routing Strategy |
|-----|---|---|---|---|
| +3V3 | 3.3V | LDO (TCR3UG33A) | MCU (U3 VDD), LoRa (U9 VDD), GPIO rails | Main signal supply. Multi-layer routing: L1 fine traces, L2 plane spur. Min 0.35mm track width. Via cluster at bulk cap. |
| +3V3_GPS | 3.3V isolated | Dedicated LDO for GPS | U6 (Quectel VCC only) | Separate LDO to reduce noise into GPS. Do not share return until star-point GND. Min 0.35mm. |
| +5V | 5V | USB or boost (RT6158A?) | Possible future ePaper module, USB device | Currently low-traffic. Run on L1, 0.3mm wide. |
| +BATT | 3.7–4.2V (raw) | JST-PH connector | BMS input (RT6158A, BQ25630) | **High-current path**: ≥0.5mm L4 traces, multi-via sink. Direct from JST connector, no intermediate pads. |
| +SYS | 3.3V (gated) | Post-BMS rail (from RT6158A output) | Backup supply for GPS (V_BCKP), optional future modules | Derived from +BATT via RT6158A. Secondary importance. 0.3mm typical. |
| GND | 0V (reference) | Multi-point star | All ICs, connectors | **L2 ground plane** (continuous under entire board except antenna keep-out). Return vias at every power IC output. |

### Power Net Specifics
- **+3V3 to U3 (MCU)**: C41 (4.7µF bulk) + C14/C15/C16 (100nF x3) cluster. Route: L1 top layer from C41 pad, ≤3mm to any U3 VDD pin.
- **+3V3_GPS to U6**: C29 (10µF) + C30 (100nF) cluster. Separate LDO output; do NOT cross-connect +3V3 rail until after bulk cap junction.
- **+BATT direct to JST**: No intermediate protection resistor in critical path. Single 0.5mm trace on L4, OR use L1 with ≥4 vias at each end.
- **GND star point**: Converge all power IC returns (LDO, BMS, charger) at a single spot near bulk cap cluster (approx. X=44mm, Y=5mm). Fan out to L2 plane via multi-via (≥5 vias, 0.3mm dia).

---

## CRITICAL DATA NETS (High-Speed Interfaces)

### I²C Bus (MCU U3 ↔ Sensors/ECC)
**Participants**: U3 (STM32L431 I²C1), U5 (ATECC608B), U6 (Quectel GPS optional I²C), LIS2DW12 accelerometer
```
Net:    SDA_I2C1
Pin:    U3.PB9 ↔ U5.SDA (and optionally U6.SDA if GPS I²C mode)
Length: ≤100mm total trace + stubs
Width:  0.2mm (standard signal)
Layer:  L1 (top), shield with adjacent GND traces ≥0.5mm away
Termination: 4.7K pull-ups (R_SDA_PU) to +3V3, located at MCU cluster, ≤10mm from MCU

Net:    SCL_I2C1
Pin:    U3.PB8 ↔ U5.SCL
Length: ≤100mm total
Width:  0.2mm
Layer:  L1
Termination: 4.7K pull-ups (R_SCL_PU) to +3V3
Note:   Avoid running SDA/SCL across high-speed SPI traces. Separate paths if on same layer.
```

### SPI Bus (MCU U3 ↔ LoRa U9, optionally GPS U6)
**Primary SPI: LoRa (RAK11720)**
```
Net:    SPI_MOSI
Pin:    U3.PA7 (MOSI) ↔ U9.MOSI
Width:  0.2mm, controlled impedance ≈50Ω preferred (not critical for SPI, but good practice)
Layer:  L1 top surface only (no buried vias)
Length: ≤50mm direct, no stubs
Shielding: Run GND trace adjacent (≥0.3mm spacing), or use GND plane (L2) directly below (via every 2–3mm)

Net:    SPI_MISO
Pin:    U3.PA6 (MISO) ↔ U9.MISO
Width:  0.2mm
Layer:  L1
Length: ≤50mm
Shielding: Same as MOSI

Net:    SPI_CLK
Pin:    U3.PA5 (SCK) ↔ U9.SCK
Width:  0.2mm (or 0.25mm for lower skew)
Layer:  L1, clock-tree preferred (minimal fanout, no Y-junctions)
Length: ≤50mm
Slew rate: Keep 10–30 ns rise time (buffer if needed, typically not)

Net:    SPI_CS_LoRa (chip select)
Pin:    U3.PB6 (or GPIO) ↔ U9.NSS
Width:  0.2mm
Layer:  L1
Length: ≤50mm
Control: Active-low, ensure no glitch during power-up
```

**Optional Secondary SPI: GPS Module (if SPI mode used instead of UART)**
```
Net:    SPI_CS_GPS (chip select for GPS)
Pin:    U3.PA4 (or GPIO) ↔ U6.CS
Width:  0.2mm
Layer:  L1
Length: ≤80mm (GPS may be farther away)
Note:   Use if Quectel in SPI mode. UART mode does NOT use these nets.
```

### UART (MCU U3 ↔ GPS/LoRa, Debug)
**Primary UART: GPS Telemetry**
```
Net:    UART1_RXD (GNSS data input)
Pin:    U3.PA10 ↔ U6.TX (Quectel transmits)
Width:  0.2mm (single-ended logic)
Layer:  L1 (standard signal layer)
Length: ≤100mm, allow routing flexibility
Termination: No series R (standard UART). If noise concerns, add 100Ω series at U3.PA10

Net:    UART1_TXD (GNSS command output)
Pin:    U3.PA9 ↔ U6.RX (Quectel receives)
Width:  0.2mm
Layer:  L1
Length: ≤100mm
Note:   Low-speed UART (4800–9600 baud typical for GPS). No impedance control needed.
```

**Debug UART (MCU ↔ External USB-UART or debugger)**
```
Net:    UART_DEBUG_TX (U3.PA2 or similar)
Net:    UART_DEBUG_RX (U3.PA3 or similar)
Width:  0.2mm
Layer:  L1
Length: Not routed to connector on this board (reserved for future)
```

---

## ANTENNA & RF NETS (50Ω Controlled Impedance)

### LoRa RF Trace
```
Net:    ANT_LoRa
Pin:    U9.ANT_RF ↔ MHF4 connector (breakout pad)
Impedance:  50Ω nominal (IMPORTANT for LoRa 863–870 MHz)
Width:  Calculate from PCB stackup: 
        - Assume 2mm trace on L1, L2 solid GND below → ~50Ω for ~0.8–1.0mm width
        - Use trace width = 0.8mm on L1 for ~50Ω
        OR verify with calculator if your stackup differs
Layer:  L1 top surface ONLY
Length: ≤10mm to MHF4 pad
Via Rule: Minimize to vias only at connector pad (≤2 vias). No mid-trace transitions.
Keep-out: 10mm radius around MHF4 connector — NO ground plane or traces inside this zone
End Termination: 0Ω resistor (jumper) at antenna pad if matching network needed. TBD in schematic ERC.
Return Path: Ground return for LoRa RF is via separate GND net (see GND details below).
```

### GPS/GNSS RF Trace
```
Net:    ANT_GPS
Pin:    U6.ANT_RF ↔ GPS FPC connector or SMA
Impedance:  50Ω nominal (GPS L1 band, 1.575 GHz)
Width:  ~0.8–1.0mm on L1
Layer:  L1 top only
Length: ≤8mm to antenna connector
Keep-out: 8mm radius around connector
Via Rule: Connector pad only, min 1–2 vias
Stub: Minimize antenna stub cap (if any); prefer on module itself
```

---

## DIFFERENTIAL PAIRS (if used; currently none planned)

**Note**: Standard Bikera design does NOT use differential pairs for power or signal integrity. LoRa and GPS are single-ended RF traces. If future BLE antenna or USB3 is added, differential pairs may be introduced.

**Potential future differential nets**:
- USB 3.1 (if USB HUB future): D+/D- pair, 90Ω differential
- LoRa diff-pair antenna (if advanced RF module): Paired +ANT_LoRa and ANT_LoRa_N

---

## GROUND RETURN PATHS (GND Net)

### L2 Ground Plane (Continuous, Lowest Impedance)
- **Extent**: Cover entire board (50×30mm) except:
  - 10mm keep-out radii around LoRa and GPS antenna connectors (no GND plane inside)
  - 1–2mm clearance at board edges (no plane)
- **Connectivity**: Multiple solder vias (0.3mm dia, ≥5 total) at:
  - Star point near bulk caps (X≈44mm, Y≈5mm)
  - MCU cluster (X≈7.5mm, Y≈15mm)
  - LoRa cluster (X≈37mm, Y≈18mm)
  - GPS cluster (X≈25mm, Y≈12mm)

### L4 Ground Layer (Bottom Signal Layer)
- Secondary return path for high-frequency edges
- Via-stitching: every 2–3mm along high-speed signal traces (e.g., SPI)
- Not a continuous plane; allows routing of power and signal traces on L4 where needed

### Specific GND Nets (from schematic; all merged at star point)
- **U3.VSS** (MCU ground): 2–3 pins, via cluster to L2 plane
- **U9.GND** (LoRa module): 1 pin or multi-pin, via cluster (isolated path, keep ≥10mm from MCU digital GND until star point)
- **U6.GND** (GPS module): 1 pin, via cluster (isolated analog path)
- **U5.GND** (ECC chip): 1 pin, via cluster
- **Connector GND** (USB, JST-PH): Multi-via to L2 plane
- **Test point GND**: TP_GND (X≈5mm, Y≈25mm and Y≈5mm)

---

## NET CLASS ASSIGNMENT SUMMARY

| Net Class | Nets | Track Width (mm) | Clearance (mm) | Via Dia / Drill (mm) | Diff-Pair Gap (mm) |
|---|---|---|---|---|---|
| Default | All GPIO, low-speed logic | 0.2 | 0.2 | 0.6 / 0.3 | N/A |
| Power | +3V3, +5V, +BATT (bulk) | 0.5 | 0.25 | 0.8 / 0.4 | N/A |
| HighSpeed_SPI | SPI_MOSI, MISO, CLK, CS | 0.2 | 0.2 | 0.4 / 0.2 | N/A |
| HighSpeed_RF | ANT_LoRa, ANT_GPS (50Ω) | 0.8–1.0 | 0.5 | 0.4 / 0.2 | N/A |
| GND | All ground nets (L2 plane) | N/A (continuous) | 0.2 (edge) | 0.3 / 0.15 | N/A |

---

## PRIORITY ROUTING ORDER

1. **Power delivery**: JST-PH → BMS → LDO → +3V3 bulk cap → MCU/LoRa/GPS
2. **Ground star point**: Converge all returns here, then fan out to L2 plane
3. **RF antennas**: LoRa and GPS traces, 50Ω routing, keep-out zones
4. **SPI bus**: MCU ↔ LoRa (and optionally GPS), shield with GND, minimize trace length
5. **I²C bus**: MCU ↔ ECC/GPS/Accel, low-speed but noise-sensitive
6. **UART**: GPS telemetry, general purpose (lowest priority)
7. **GPIO**: Buttons, LED, IO connectors (absolute lowest priority)

---

## NOTES FOR LAYOUT TOOL

- All critical nets should have **design rules checks (DRC)** enabled:
  - Minimum clearance: 0.2mm (KiCad default)
  - Track-to-via spacing: 0.2mm min
  - Antenna keep-outs: manual visual inspection (KiCad constraint system may not enforce 10mm radius)
- Use KiCad's **"Highlight Net"** feature to validate each critical net before routing
- Export netlist in CSV format for cross-reference with this anchor note

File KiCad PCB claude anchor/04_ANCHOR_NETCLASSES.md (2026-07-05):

# BIKERA PCB LAYOUT ANCHOR NOTE
## Step 4: Net Class Constraints & Design Rules

**SOURCE**: KiCad project file (.kicad_pro) baseline + refined rules for Bikera's specific RF/IoT requirements.

---

## NET CLASS DEFINITIONS

### Class 1: Default (Standard Digital Logic & GPIO)
**Assigned Nets**: All GPIO, logic signals not in other classes (LED, buttons, debug, servo control, etc.)

| Parameter | Value | Unit | Notes |
|---|---|---|---|
| **Track Width (minimum)** | 0.2 | mm | KiCad default; conservative for 4-layer, acceptable for low-frequency GPIO |
| **Track Width (typical)** | 0.25 | mm | Use for general signal routing (better via landing, more robust) |
| **Clearance (minimum)** | 0.2 | mm | Same net to different net; enforced by DRC |
| **Clearance (pad-to-trace)** | 0.2 | mm | Pad to adjacent trace clearance |
| **Via Diameter (finished)** | 0.6 | mm | Hole size 0.3mm, pad annular ring ≥0.15mm each side |
| **Via Drill Diameter** | 0.3 | mm | Standard PTH via for signal transition |
| **Via Spacing** | 0.4 | mm | Via-to-via minimum (center-to-center) |
| **Diff-Pair Gap** | N/A | – | Not used for this class |
| **Matched Trace Length** | N/A | – | Not enforced |

**Applicable nets**:
- Button inputs (SW1_RESET, SW2_BOOT)
- LED outputs (LED_RED, LED_GREEN)
- Debug UART (UART_DEBUG_TX/RX, if routed)
- Servo control (EN_5V_SERVO)
- Hall effect sensor (DRV5032 output)
- ePaper module (EPAPER_DC, EPAPER_CS, EPAPER_RST, EPAPER_BUSY)
- GPS auxiliary (GPS_RESET, GPS_EN, GPS_PPS)
- LoRa auxiliary (LORA_BOOT, LORA_RESET)
- Charger control (CHRG_INT, CHRG_PG, CHRG_CE)
- Battery sense (VBAT_SENSE analog-to-digital input, routed as single-ended logic trace)

---

### Class 2: Power (Supply Rails & Distribution)
**Assigned Nets**: +3V3, +3V3_GPS, +5V, +BATT, +SYS, GND (return paths only; actual GND plane is Class 6)

| Parameter | Value | Unit | Notes |
|---|---|---|---|
| **Track Width (minimum)** | 0.5 | mm | Heavy copper for ≤2A expected current |
| **Track Width (typical)** | 0.75–1.0 | mm | Use for main +BATT path and LDO outputs |
| **Clearance (minimum)** | 0.25 | mm | Slightly relaxed vs. signal (power distribution less noise-sensitive) |
| **Clearance (pad-to-trace)** | 0.25 | mm | Same as above |
| **Via Diameter (finished)** | 0.8 | mm | Larger pad for current spreading |
| **Via Drill Diameter** | 0.4 | mm | Support higher current density |
| **Via Spacing (bulk cap to IC)** | 0.5 | mm | Cluster ≥4–5 vias at bulk cap connections |
| **Diff-Pair Gap** | N/A | – | Not used |
| **Thermal Relief** | 0.4 | mm | Spoke width on pads; reduces thermal bridging during solder |

**Applicable nets**:
- +BATT (JST-PH input to BMS): highest priority, use 1.0mm+ trace on L4, or L1 + multi-via
- +3V3 (LDO output to MCU/LoRa/GPIO bulk): 0.75mm minimum
- +3V3_GPS (isolated GPS LDO output): 0.5mm, separate path from main +3V3 until star-point
- +5V (USB or boost output, low-current for now): 0.5mm
- +SYS (backup/post-BMS rail): 0.5mm, low-current secondary

**Specific Routing Rules for Power**:
1. **JST-PH to BMS input**: Direct trace, no intermediate components. Use L4 bottom layer (away from RF keep-out zones). Width ≥0.5mm, ideally 1.0mm. Multi-via (≥3) at connector pad and BMS IC pad.
2. **BMS output to LDO input**: Route on L1 if space allows (keeps heat off inner layers), or L3 if dedicated power plane. Min 0.5mm width.
3. **LDO output to bulk cap**: ≤5mm copper length, ≥4 vias. This is the critical star point where all returns merge.
4. **Bulk cap to MCU/LoRa/GPS VDD**: Tree-like distribution from star point. Use L1 fine traces (0.35mm) to reach each IC.
5. **GND returns**: All ICs' VSS pins multi-via (≥3 each) directly to L2 ground plane near star point. Converge all returns here before fanning to rest of board.

---

### Class 3: HighSpeed_SPI (MCU ↔ LoRa, optionally GPS)
**Assigned Nets**: SPI1_MOSI, SPI1_MISO, SPI1_SCK, SPI1_CS (LoRa); optionally SPI1_CS_GPS if GPS in SPI mode

| Parameter | Value | Unit | Notes |
|---|---|---|---|
| **Track Width (minimum)** | 0.2 | mm | Match impedance for controlled routing (see RF class for ANT nets) |
| **Track Width (typical)** | 0.2 | mm | Standard SPI speed (MHz, not GHz), impedance matching not critical but recommended |
| **Clearance (minimum)** | 0.2 | mm | SPI is single-ended; standard clearance |
| **Clearance (pad-to-trace)** | 0.2 | mm | Same as above |
| **Via Diameter (finished)** | 0.4 | mm | Smaller vias reduce stub length (SPI transitions between L1 and L4 if necessary) |
| **Via Drill Diameter** | 0.2 | mm | Fine drill for SPI vias |
| **Via Spacing** | 0.3 | mm | Keep transitions compact |
| **GND Shielding** | Every 2–3mm along trace | Requirement | Run ground trace parallel to each SPI signal, or use L2 via-stitching below |
| **Trace Length Matching** | ±5mm | – | Not critical for SPI (MHz clock), but good practice within MCU ↔ LoRa cluster |
| **Skew Control** | <1 ns | – | Keep SPI clock (SCK) fastest; data (MOSI/MISO) can lag slightly |

**Specific Routing Rules for SPI**:
1. **Clock (SPI1_SCK)**: Route first, minimize branches. No stubs at intermediate chips (LoRa only). Use 0.2mm width.
2. **Data (MOSI/MISO)**: Can route after clock. Equal length to clock preferred (±5mm tolerance).
3. **Chip Select (CS)**: Route last (lowest priority). Active-low, ensure ~1ns setup time before SCK edge.
4. **Layer**: L1 (top) exclusively for MCU ↔ LoRa SPI. Do NOT route on L4 (bottom) if MCU is top-side.
5. **Shielding**: Option A: Adjacent ground trace (0.5mm parallel spacing, connected to GND net every 5–10mm via small via). Option B: Via-stitching (via array on both sides of signal trace at 2–3mm pitch, all tied to L2 GND plane).
6. **Stub length**: Minimize at LoRa breakout pad. If multi-drop required (GPS SPI + LoRa), use active buffer or tree topology (MCU → buffer → GPS & LoRa).

**Applicable Nets**:
- SPI1_MOSI (MCU PA7 → LoRa U9.MOSI, optionally GPS U6.MOSI)
- SPI1_MISO (LoRa U9.MISO → MCU PA6, optionally GPS U6.MISO)
- SPI1_SCK (MCU PA5 → LoRa U9.SCK & optionally GPS U6.SCK)
- SD_CS (MCU GPIO → SD-card module breakout, header-based)
- (optional) SPI1_CS_LoRa (MCU PB6 → LoRa U9.NSS, active-low)
- (optional) SPI1_CS_GPS (MCU PA4 → Quectel U6.CS, if SPI mode enabled; default is UART)

---

### Class 4: HighSpeed_I2C (MCU ↔ ECC, Sensors, optional GPS)
**Assigned Nets**: I2C_SDA, I2C_SCL (MCU I²C1 / PB9 & PB8)

| Parameter | Value | Unit | Notes |
|---|---|---|---|
| **Track Width (minimum)** | 0.2 | mm | Open-drain bus, no characteristic impedance needed |
| **Track Width (typical)** | 0.25 | mm | I²C is slow (MHz), so trace width is non-critical; larger pads help with pull-ups |
| **Clearance (minimum)** | 0.2 | mm | Standard digital clearance |
| **Clearance (pad-to-trace)** | 0.2 | mm | Same as above |
| **Via Diameter (finished)** | 0.5 | mm | I²C is low-frequency; standard via acceptable |
| **Via Drill Diameter** | 0.25 | mm | No high-speed transitions required |
| **Via Spacing** | 0.3 | mm | Normal spacing |
| **Pull-up Resistor Value** | 4.7K | Ω | Standard I²C termination; locate at MCU (PB8/PB9 cluster), ≤10mm from MCU pins |
| **Pull-up Voltage** | +3V3 | V | Tied to +3V3 rail at MCU cluster |
| **Max Trace Length** | ≤100 | mm | I²C is low-speed (100 kHz standard, 400 kHz fast-mode); trace length not critical. Capacitance limit ~200pF total. |
| **Stub Length** | ≤20 | mm | Keep stubs to sensors (ECC, GPS optional, accel) short (<20mm each). Root hub at MCU. |

**Specific Routing Rules for I²C**:
1. **Bus topology**: Star or near-star from MCU cluster. Root: MCU PB8 (SCL) + PB9 (SDA) + two 4.7K pull-ups to +3V3.
2. **Pull-up placement**: Locate pull-up resistors (R_SDA_PU, R_SCL_PU) within 10mm of MCU I²C pins. Use 0603 SMD, place on L1 near MCU.
3. **Device drops**: Branch to each I²C slave:
   - U5 (ATECC608B): ~5mm stub
   - U6 (Quectel GPS, if I²C mode): ~40mm stub (farther away)
   - LIS2DW12 accel module: ~15mm stub
4. **Layer**: L1 top surface preferred. May transition to L4 via via-stitching if needed to route around power components.
5. **Noise protection**: Run I²C traces ≥5mm away from high-speed SPI traces if on same layer. If coexisting, use adjacent ground traces or separate to different layers.

**Applicable Nets**:
- I2C_SDA (MCU PB9 → U5.SDA, U6.SDA (if enabled), LIS2DW12.SDA)
- I2C_SCL (MCU PB8 → U5.SCL, U6.SCL (if enabled), LIS2DW12.SCL)

---

### Class 5: HighSpeed_RF (Antenna Traces, 50Ω Controlled Impedance)
**Assigned Nets**: ANT_LoRa, ANT_GPS (feed-point to antenna connectors, MHF4 and FPC respectively)

| Parameter | Value | Unit | Notes |
|---|---|---|---|
| **Track Width (critical)** | 0.8–1.0 | mm | **Impedance-controlled**: Must target 50Ω characteristic impedance. See stackup calculation below. |
| **Clearance (minimum, to GND)** | 0.8–1.0 | mm | Keep GND traces/plane ≥0.8mm away from RF trace edges. Widening the trace narrows the clearance needed. |
| **Clearance (to other signal)** | 1.0 | mm | RF traces should not run adjacent to digital logic. Minimum 1.0mm gap. |
| **Via Diameter (finished)** | 0.4 | mm | Keep vias small to minimize impedance discontinuity. Transition vias only at antenna pad. |
| **Via Drill Diameter** | 0.2 | mm | Fine drill to reduce stub |
| **Via Count at Antenna Pad** | 1–2 | – | Minimize vias; use tented (solder mask both sides) to prevent moisture ingress. |
| **Trace Length (ANT_LoRa)** | <10 | mm | From U9.ANT_RF pad to MHF4 connector on board edge. Short trace = less insertion loss. |
| **Trace Length (ANT_GPS)** | <8 | mm | From U6.ANT_RF pad to FPC connector. Even shorter preferred for high-frequency GPS (1.575 GHz). |
| **Keep-out Zone (ANT_LoRa)** | 10 | mm radius | No GND plane, no other traces inside 10mm radius around MHF4 connector foot. Antenna space to radiate. |
| **Keep-out Zone (ANT_GPS)** | 8 | mm radius | Similar; GPS frequency higher, so smaller keep-out acceptable. |
| **Return Path (GND)** | Dedicated via-stitched ground return | – | Separate GND return from RF trace (not through main power GND star point) if possible. For small board, may be unavoidable—route GND return directly to L2 plane via multi-via at antenna pad. |
| **Matching Network** | 0Ω jumper (optional) | – | If antenna impedance deviates from 50Ω (e.g., FPC cable adds 5Ω), place matching stub or series element at antenna pad. Calibrate via S-parameter measurement (future work). For now, assume 50Ω match. |

**Specific Routing Rules for RF Antennas**:
1. **Impedance Calculation** (for your 4-layer stackup):
   - Assume typical PCB: 1.6mm total thickness, L1 ↔ L2 spacing ~0.2mm, L2 solid GND plane below L1
   - 50Ω target width: ~0.8–1.0mm on L1 with GND plane at 0.2mm distance
   - **Action**: Use 0.9mm width for both ANT_LoRa and ANT_GPS, verify with online microstrip calculator if actual stackup differs
   - If stackup varies (e.g., 0.15mm spacing), adjust width proportionally: narrower spacing → narrower trace for same Z₀

2. **LoRa Antenna (ANT_LoRa)**:
   - Source: U9.ANT_RF pad (RAK11720 MHF4 breakout)
   - Destination: MHF4 connector (on board right edge, ~X=48mm, Y≈15mm)
   - Width: 0.9mm (50Ω target)
   - Layer: L1 top only. No via transitions mid-trace.
   - Length: Prefer straight line, <10mm total etch
   - Keep-out: 10mm no-GND zone around MHF4 connector. Actual antenna on module will radiate outside this keep-out.
   - Return GND: Multi-via (≥2) at MHF4 connector pad, tied to L2 GND plane. Keep via cluster ≥2mm away from RF trace (outside 10mm keep-out).
   - Via-stitching: Optional along ANT_LoRa trace edges (every 3–5mm) to stabilize impedance, but not critical for <10mm line.

3. **GPS Antenna (ANT_GPS)**:
   - Source: U6.ANT_RF pad (Quectel LC76GPAMD, may be on FPC breakout)
   - Destination: FPC connector or SMA (prefer top edge, ~Y=29mm)
   - Width: 0.9mm (50Ω target)
   - Layer: L1 top only
   - Length: <8mm (GPS is higher frequency, lower tolerance for insertion loss)
   - Keep-out: 8mm no-GND zone
   - Return GND: Multi-via (≥2) at FPC connector, tied to L2 GND plane
   - Note: Quectel LC76G datasheet recommends "keep antenna away from digital circuits". Use keep-out zone to enforce.

4. **Antenna Connector Selection**:
   - LoRa: MHF4 (half-hole) breakout on PCB, external FPC or wire antenna off-board (or on-board as separate component)
   - GPS: FPC connector on PCB, external passive antenna (Quectel YFGA003AA or equivalent)
   - Both: Minimize connector loss by choosing low-loss subminiature connectors (MHF4 ≈0.5dB, SMA ≈0.2dB, FPC ≈1dB)

**Applicable Nets**:
- ANT_LoRa (U9.ANT_RF → MHF4 connector, RAK11720 breakout)
- ANT_GPS (U6.ANT_RF → FPC or SMA connector, Quectel GPS module)

---

### Class 6: GND (Ground Plane & Returns, Continuous L2 Plane)
**Assigned Nets**: GND (single global net, not a trace class but a plane distribution structure)

| Parameter | Value | Unit | Notes |
|---|---|---|---|
| **Layer** | L2 (inner layer) | – | Solid ground plane, continuous under entire board |
| **Coverage** | ~95% of board area | – | Exceptions: antenna keep-out zones (10mm LoRa, 8mm GPS), 1–2mm clearance at board edges |
| **Via Stitching (GND)** | Every 2–3mm | spacing | Along high-speed signal traces (SPI, I²C) and around sensitive analog circuits (GPS, ECC). Use 0.3mm via diameter. |
| **Star Point Location** | (X≈44mm, Y≈5mm) | mm | Convergence point for all power IC returns (BMS, LDO, charger). Fan-out to L2 plane via ≥5 vias (0.3mm dia). |
| **Return Vias per IC** | ≥3 per IC | – | MCU (3× VSS pins → 3 vias), LoRa (1–2 vias), GPS (1 via), ECC (1 via), charger (1–2 vias) |
| **GND Plane Thickness (typical)** | 35 µm (1oz copper) | – | Standard PCB thickness; no custom spec needed |
| **Thermal Relief Spokes** | 0.4mm width | – | On pads connected to GND plane (reduces thermal bridging during reflow) |

**Specific Routing Rules for GND**:
1. **Plane creation**: In PCB editor, create L2 as a single GND polygon covering 95% of usable board area. Exclude antenna keep-out zones.
2. **Antenna Keep-outs**: Draw small ground-free zones (10mm LoRa, 8mm GPS) centered on antenna pads. These are "no GND plane" areas, not routed traces.
3. **Star Point**: All power IC VSS/GND pins route to star point via via cluster. From star point, single multi-via set connects to L2 plane.
4. **Via-stitching for signals**: Around MCU (SPI/I²C), use via-stitching (0.3mm vias every 2–3mm) to:
   - Ground the SPI data and clock traces
   - Reduce EMI coupling into sensitive analog circuits
   - Support controlled impedance (50Ω for RF, ~50Ω for SPI shield)
5. **Return paths**: Every signal net must have a clear, low-impedance GND return. Preferred: GND plane (L2) directly below via via-stitching. Worst case: run a parallel GND trace on same layer.

---

## LAYER ASSIGNMENT SUMMARY

| Layer | Name | Use | Net Classes Allowed |
|---|---|-----|---|
| L1 | Top signal | High-speed signals, fine-pitch SMD pads, antenna traces | Default, HighSpeed_SPI, HighSpeed_I2C, HighSpeed_RF, Power (fine distribution only) |
| L2 | GND plane | Continuous ground reference, return paths, shielding | GND (continuous plane) |
| L3 | Power plane | Dedicated +3V3 or internal routing (optional; may be signal layer if unused) | Power (bulk), optional LoRa/GPS local supplies |
| L4 | Bottom signal | Power distribution, secondary signal routing, component placement | Default, Power, HighSpeed_SPI (via transitions), HighSpeed_I2C (via transitions) |

---

## DESIGN RULE CHECKLIST (KiCad DRC Settings)

Enable the following DRC checks in KiCad → Inspect → Design Rule Checker:

1. **Clearance Rules**:
   - ✅ Minimum clearance: 0.2mm (all nets vs. all nets)
   - ✅ Copper-to-edge: 0.5mm (traces stay ≥0.5mm from board edge)
   - ✅ Via-to-via: 0.3mm center-to-center minimum

2. **Trace Width Rules**:
   - ✅ Minimum trace width: 0.15mm (conservative for 4-layer)
   - ✅ Apply net class track widths: Default 0.2mm, Power 0.5mm, SPI 0.2mm, RF 0.9mm

3. **Via Rules**:
   - ✅ Minimum via diameter: 0.4mm (finished; 0.2mm drill)
   - ✅ Via annular ring: ≥0.15mm all sides

4. **Antenna Keep-outs** (manual inspection, not DRC):
   - ⚠️ **Visual check**: Verify 10mm no-GND-plane zone around LoRa MHF4 connector
   - ⚠️ **Visual check**: Verify 8mm no-GND-plane zone around GPS FPC connector

5. **High-Speed Signal Integrity** (manual inspection):
   - ⚠️ **Check**: SPI traces (MOSI/MISO/SCK) do not run adjacent to I²C or power traces; minimum 1mm spacing or separate layer
   - ⚠️ **Check**: RF antenna traces (ANT_LoRa, ANT_GPS) are isolated, kept on L1 only, with via-stitched ground returns
   - ⚠️ **Check**: Pull-up resistors for I²C are within 10mm of MCU I²C pins

---

## MANUFACTURING & ASSEMBLY SPECIFICATIONS

| Item | Specification | Notes |
|---|---|---|
| **PCB Fabrication** | 4-layer, 1.6mm FR-4, 1oz copper (35µm) each layer | Standard spec; no custom requirements |
| **Solder Mask** | Both sides, green or blue | No mask between fine-pitch pads (QFP, SOIC) for reflow control |
| **Silkscreen** | Top side (L1) only, 0.8mm text | Reference designators, manufacturer logo, test point labels |
| **Trace Width / Spacing** | Min 6mil (0.15mm) / 6mil conservative | Fab tolerance: ±0.1mm typical |
| **Via Tenting** | Solder mask both sides | Protects via holes during assembly; easier rework |
| **Edge Clearance** | ≥0.5mm copper from edge | Trace/via clearance; pads/connectors may touch edge |
| **Panelization** | Single board, no mouse bites | If panelized, use 3–5mm between boards |
| **Test Coupon** | Optional (recommend if high-reliability required) | Includes trace/space, via samples, material coupons |

---

## FUTURE ENHANCEMENTS & NET CLASSES (Not Yet Implemented)

If future board revisions add the following features, create additional net classes:

| Feature | New Nets | Suggested Class | Key Rules |
|---|---|---|---|
| USB 3.1 Type-C | D+/D- differential | USB3_Diff | 90Ω differential Z₀, ±3mm length match, via-less routing, low-loss material |
| Advanced BLE antenna | BLE_RF (differential or single-ended) | HighSpeed_RF_2400 | Similar to LoRa (50Ω), but 2.4 GHz (tighter tolerances) |
| High-speed sensor interface (e.g., QSPI) | SPI data + clock | HighSpeed_QSPI | 50Ω for each line, source-series termination, matched delays |
| Low-noise analog (if ADC upgraded) | Analog_VRef, Analog_IN | AnalogHighZ | Guard traces, isolated ground, no digital switching near |

---

## VALIDATION CHECKLIST (Pre-Fabrication)

- [ ] Export netlist from KiCad and cross-reference all nets with Step 3 anchor (Minimal Netlist)
- [ ] Run DRC; resolve all errors (goal: 0 errors, 0 warnings after cleanup)
- [ ] Verify antenna keep-out zones are ≥10mm (LoRa) / ≥8mm (GPS) with no GND plane inside
- [ ] Check that all power IC returns converge at star point (X≈44mm, Y≈5mm)
- [ ] Confirm SPI traces have GND shielding or via-stitching along entire route
- [ ] Verify I²C pull-up resistors are ≤10mm from MCU I²C pins and tied to +3V3
- [ ] Inspect Layer stack: L1 (signals) → L2 (GND plane) → L3 (power plane or signal) → L4 (signals & power distribution)
- [ ] Generate Gerber files and review in Gerber viewer (e.g., KiCad's built-in viewer or gerbv)
- [ ] Measure trace impedance (if RF is critical) using stackup calculator or VNA measurement on test coupon

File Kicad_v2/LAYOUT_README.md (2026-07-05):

# Bikera devboard — generated PCB layout (2026-07-05)

Generated from the anchor notes (00–04) + `Bikera PCB devboard.net`.
All 110 netlist components + 4 mounting holes placed, zero courtyard overlaps,
every pad net-assigned and cross-checked against the netlist (0 mismatches).

## Files
| File | What |
|---|---|
| `Bikera PCB devboard.kicad_pcb` | The layout (also saved as `..._GENERATED_BACKUP.kicad_pcb`) |
| `Bikera PCB devboard.kicad_dru` | Custom DRC rules (RF width 0.85–0.95 mm, +BATT ≥0.5 mm, Power ≥0.35 mm) |
| `Bikera PCB devboard.kicad_pro` | Patched: 6 net classes + 24 net patterns (original in `.bak_before_netclasses`) |
| `layout_top_plan.png` / `layout_bottom_plan.png` | Placement plans with courtyards |
| `layout_pads_verification.png` | Pad-level render of the emitted file |

**KiCad was open while I wrote these** (lock files present). If KiCad is still open:
close it WITHOUT saving the PCB or project, then reopen. If it saved over anything,
restore from `..._GENERATED_BACKUP.kicad_pcb` and `.bak_before_netclasses`.

## ⚠ Board size: 60×40 mm (not 50×30)
50×30 cannot hold this BOM: through-hole parts alone (SD header, ST-LINK area, DIP-8
socket, JSTs, buttons, 470 µF radial, USB-C…) block ~1100 mm² on *both* sides; with
SMD courtyards the top side needed ~125% of a 50×30 board. You approved 60×40
(~78%/72% utilization). Anchor zones were kept, scaled: MCU center-left, GPS+antenna
top-left, LoRa (bottom side) center-left, power column right edge, connectors on edges.
Mounting holes M3 at (3.5, 3.5) from each corner. KiCad coords: origin top-left, Y down.

## Placement highlights
- **U3 MCU** top, center (24, 26.2); C14/C15/C16 at VDD pins, C41 bulk adjacent,
  VDDA group (FB1, C17, C18, C40) at pin 9, all within anchor distances.
- **U9 RAK11720** on the **bottom side** (18.1, 24.5) — it's UART-only in the real
  netlist (not SPI as the anchors assumed), so routing is easy; C37–C39 + R24/R25 beside it.
- **U6 GPS** top-left, RF pin facing **AE1 (U.FL)** in the top-left corner; feed is
  ~5 mm. R28/C50/C49/D3 sit in the feed path. V_BCKP backup cluster (D2/D4/C32/U8)
  on the bottom under the GPS area.
- **Power column** on the right edge, top→bottom: L3, U4 (boost), U2 (GPS LDO),
  L1, IC2 (charger, BATT pads toward battery), L2, U1 (buck-boost). BT1 battery JST
  exits the right edge; TH1 next to it. **Star point**: bottom-right of the column,
  near (53, 33) — R16 servo shunt is right there.
- **J3 ST-LINK** is on the **bottom side** (debug adapter mates from below).
  **H3 SD header** lies along the bottom edge; **J7 ePaper** along the top edge;
  **H4 servo** bottom-right; **H2 accel header** vertical, left side.
- **IC1/IC3 hall sensors** are at the left/right board edges as placeholders —
  position them to match your magnet mechanics before routing.

## ⚠ Schematic bugs found in the netlist (fix in Eeschema)
1. **H3 pin 12** is in both `SPI1_MOSI` (pinfunction MOSI_12) and `SPI1_SCK`
   (SCK_12). I assigned it to **SPI1_MOSI** (pairs 11/12 = MOSI). Fix the SD
   adapter symbol/wiring.
2. **J7 pin 3** is in both `EPAPER_RST` and `SPI1_MOSI` (DIN_3). I assigned it to
   **SPI1_MOSI**; `EPAPER_RST` currently reaches no J7 pin on the board — it should
   probably be J7 pin 7 (pin 7 is absent from the netlist entirely).
3. **U9.12 (LORA_RF) and U9.33 (BLE_RF) are unconnected** in the netlist — the
   anchors describe a 50 Ω LoRa feed that doesn't exist in the schematic. If the
   RAK11720 needs a board-level antenna feed, add it and re-import.

## RF keep-out — deliberate deviation from anchor 04
The anchors demand *no GND plane* in an 8 mm radius around the GPS antenna connector,
but also a 0.9 mm/50 Ω microstrip — which *requires* the L2 GND reference underneath.
Since AE1 is a U.FL to an **off-board** antenna (no on-board radiator), I kept
**L2 (In1.Cu) solid** under the feed and applied the 8 mm copper-pour keep-out to
**In2.Cu (power plane) and B.Cu** only (`GPS_ANT_KEEPOUT` zone). If you want the full
anchor behaviour, edit the rule area and add In1.Cu — but then re-calculate the feed
width (it will no longer be 50 Ω against L2).

## Zones (drawn, not yet filled)
- `GND_PLANE_L2` on In1.Cu (whole board), `PWR_PLANE_L3` (+3V3) on In2.Cu,
  `GND_POUR_B` on B.Cu. Press **B** in pcbnew to fill.
- +BATT / +SYS / +5V / +3V3_GPS are *not* on the plane — route them as ≥0.5 mm traces
  (the .kicad_dru enforces widths).

## Suggested next steps
1. Close KiCad (if open), reopen the project. The board opens as a v6 file and
   KiCad 10 will upgrade it on first save — that's expected.
2. Schematic → fix the three netlist bugs above → **Update PCB from Schematic (F8)**
   with "Re-link footprints" off. Expect it to be clean apart from the H3/J7 fixes,
   the 4 mounting holes (board-only), and possibly the J1 pad-name mapping
   (netlist `A1_B12` vs footprint pads `A1`+`B12` — KiCad handles this the same way I did).
3. Fill zones, then route in anchor priority order: +BATT→IC2→U1→star point,
   GPS RF feed (0.9 mm, no vias), SPI (SD/ePaper), I²C, UART, GPIO.
4. Run DRC (the .kicad_dru rules load automatically).
5. A few non-critical resistors sit 10–17 mm from their ICs (R5–R9 charger status/TS
   network, R13, R26) — scoot them closer if you re-arrange anything.

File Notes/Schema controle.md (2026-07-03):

# MCU page
- [x] STM32
	- [x] Ontkoppelcondensators
		- [x] VDD
			- [x] 3x 100nF
			- [x] 4.7µF toevoegen
		- [x] VDDA 
			- [x] 1µF
			- [x] 10nF (VREF) toevoegen
			- [x] 100nF
			- [x] Ferrite bead
	- [x] Reset knop
		- [x] Met 100nF cap
	- [x] Boot knop
		- [x] 10kohm pulldown
		- [x] Aanpassen
- [x] Hall sensors
	- [x] Met condensators
- [x] Servo
	- [x] Ontkoppel
		- [x] 100nF
		- [x] 470µF elco
	- [x] 0.1ohm Rsense
	- [x] Rsense RC filter toevoegen
		- [x] 1K
		- [x] 33nF
- [x] LED
	- [x] 160ohm (rood)
	- [x] 130ohm (groen)
- [ ] Accelerometer
	- [ ] Footprint maken
	- [x] Ontkoppel
		- [x] 100nF
		- [x] 1µF
- [x] ST-link
- [x] ECC chip
	- [x] 100nF ontkoppel
- [x] I²C pullups weg of houden? -> Houden

# Power
- [x] Lader (BQ25...)
	- [x] Ontkoppel
		- [x] C1 - 1µF
		- [x] C2 - 10µF
		- [x] C3 - 100nF: toevoegen op BOM
		- [x] C4 - 4.7µF
		- [-] C5 - 22µF -> 2x 10µF (*waarom 2?*)
		- [x] C5 toch 22µF -> BOM aanpassen
		- [x] C6 - 10µF
		- [x] C7 - 47nF
	- [x] PG 
		- [x] led - *Weglaten*? Ja
		- [x] PG 2.2K weerstand 
		- [-] PG weerstand in serie met led als led wordt gebruikt of weg?
	- [x] R6 - INT-VREF - 10K
	- [x] Batterij
		- [x] JST-PH -> 2 pinnen ipv. 3
		- [x] R7: BATP-BAT 100R -> op pin 1 vn bat
	- [x] Thermistor circuit
		- [x] Thermistor: ~~SMD (NCP15XH103F03RC)~~ of **THT (103AT-2)**?
		- [x] Toevoegen op schema
		- [x] 103AT-2 footprint: Capacitor_THT:C_Disc_D3.4mm_W2.1mm_P2.50mm
		- [x] R8: TS-REGN - 10K -> 5.23K?
		- [x] R9: TS-GND - 10K -> 30.9K of **30.1K**?
		- [-] Nog eens berekenen, zie datasheet p.32
- [x] USB-C connector (USB4105-GF-A-060)
	- [x] CC pulldowns - R1, R2, 2x 5.1K
	- [x] TVS (U7)
- [x] 5V boost (TPS61253F)
	- [x] L 1µH
	- [x] Ontkoppel
		- [x] C12 - Vin
		- [x] C13 - Vout 22µF aanpassen naar:
		- [x] C13 - Vout 10µF
		- [x] C42 - Vout 4.7µF
		- [x] C43 - Vout 4.7µF
	- [x] R12 100K - EN pulldown - toevoegen op BOM
	- [x] R13 100K - MODE pullup - toevoegen op BOM
- [x] 3.3V buck-boost: RT6150B veranderen naar RT6158AWSC
	- [x] Alle componenten bij plaatsen
# Auxilery systems
- [x] GPS
	- [x] Symbool aanpassen:
	  - Pin 5: AP_REQ -> reserved/NC
	  - Pin 13: LNA_EN -> ANT_ON
	  - Pin 14 VCC_RF -> VDD_RF
	  - Pin 24: NC_5 -> D_SEL & pulldown weerstand toevoegen
	- [x] TVS (VCC & V_BCKP) toevoegen
		- [-] Is bidirectioneel OK?
	- [x] Ontkoppel
		- [x] VCC: 10µF, 100nF, 33pF
		- [x] V_BCKP: 4.7µF, 100nF, 33pF
	- [x] 0.1F Supercap
		- [x] R - 1K - naar 3.3V
		- [x] Diode toevoegen? Supercap zou misschien leeglopen langs R
		  -> D4: BAT60AE6327HTSA1
		- [x] BAT54C dual shottky: toevoegen op BOM
	- [ ] Optionele pinnen: alleen 1PPS ok?
- [x] GPS antenne
	- [x] U_FL RF receptacle
	- [x] SMF05CT1G???
		- [x] Gebruiken voor VCC en V_BCKP in de plaats, en bidirectionele voor antenne?
		- [x] ESD9B5.0ST5G uit BOM gebruikt voor antenne
	- [x] Matching circuit: 2x C en R toevoegen
- [x] FRAM (FM24V01A-GTR)
	- [x] 100nF ontkoppel toevoegen op BOM
- [x] SD
	- [x] Footprint: Connector_PinHeader_2.54mm:PinHeader_2x08_P2.54mm_**Horizontal** naar **Vertical**
	- [?] Haakse female pinheader gebruiken om rechtop te plaatsen?
	- [x] Pullups (MISO & CS) toevoegen aan BOM
- [x] LoRa
	- [x] Ontkoppel: schema correct (3 caps op VDD: 100nF + 10µF + 1µF), BOM heeft er 4 door verkeerde VBAT/VDD_IO-opsplitsing: één 100nF verwijderen uit BOM
	- [x] 10kΩ pulldown pin 21 (LORA_BOOT) toevoegen aan BOM (zit al in schema)
	- [x] 10kΩ pullup pin 22 (NRESET) toevoegen aan BOM (zit al in schema)

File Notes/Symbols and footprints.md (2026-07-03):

https://www.snapeda.com/
https://www.ultralibrarian.com/
https://componentsearchengine.com/
# Componenten
## STM32
**STM32L431CCT6TR**
- Symbol in KiCad: *STM32L431CCTx*
- Footprint in KiCad: *Package_QFP:LQFP-48_7x7mm_P0.5mm*
- 3D: [WisDuo 3D Step files](https://downloads.rakwireless.com/3D_File/WisDuo/)
## LoRa (+BLE)
**RAK11720**
[Snapeda](https://www.snapeda.com/parts/RAK11720/RAK/view-part/?welcome=home&ref=search&t=RAK11720&ab_test_case=b)
Antennes gaan op rak zelf
## ECC
**ATECC608B-SSHDA-T**
- Symbol:
	- [Snapeda](https://www.snapeda.com/parts/ATECC608B-SSHDA-T/Microchip%20Technology/view-part/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)
	- [Digikey](https://www.digikey.be/nl/models/13415162?tab=ultralibrarian)
	- Ah wacht stond al *in KiCad*
- Footprint: breakout bord *zelf maken*
## GPS
**Quectel LC76GPAMD**
- [Mouser](https://www.mouser.be/ProductDetail/Quectel/LC76GPAMD?qs=vvQtp7zwQdMfDuCTmjRUww%3D%3D)
- [Ultralibrarian](https://app.ultralibrarian.com/details/e7452cf1-f8e7-11ed-b159-0a34d6323d74/Quectel-Wireless-Solutions/LC76GPAMD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)
- 3D: [Snapeda](https://www.snapeda.com/parts/LC76GPAMD/Quectel/view-part/?ref=search&t=LC76GPAMD&ab_test_case=b)
## E-ink
**Waveshare 1.54” module**
- Symbol: *zelf maken*
- Footprint
	8-pin JST PH 2.0mm aansluiting
	Module footprint met schroefgaten *zelf maken*
	KiCad: 
- [ ] 	- *JST_PH_S8B-PH-K_1x08_P2.00mm_Horizontal*
- [ ] 	- *JST_PH_S8B-PH-SM4-TB_1x08-1MP_P2.00mm_Horizontal*
- [/] 	- *JST_PH_B8B-PH-K_1x08_P2.00mm_Vertical*
- [ ] 	- *JST_PH_B8B-PH-SM4-TB_1x08-1MP_P2.00mm_Vertical*
- [!] Meegeleverde kabel gaat naar 8 individuele dupont connectors:
	- [v] *PinHeader_1x08_P2.54mm_Vertical*
- 3D: pin header
## Accelerometer
LIS2DW12
**LIS2DW12 module**: *Zelf maken* - zie arch.schema
## SD kaart
**SD adapter module**
- Symbol: *Zelf maken*
- Footprint: 8x2 pin header ( **??** mm)
	KiCad:
	- *PinHeader_2x08_P2.54mm_Horizontal*
		Is male
	- Of vertical, of SMD
- 3D: pin header
## FRAM
**FM24V01A-GTR**
- Symbol, footprint, 3D: [Mouser](https://www.mouser.be/ProductDetail/Infineon-Technologies/FM24V01A-G?qs=3FnuM6ZipRKGr6yvOmSjPg%3D%3D)
- 3D: [Snapeda](https://www.snapeda.com/parts/FM24V01A-GTR/Cypress%20Semiconductor/view-part/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)
## BMS
### Lader
**BQ25630YBGR**
- Symbol, footprint, 3D: [Mouser](https://www.mouser.be/ProductDetail/Texas-Instruments/BQ25630YBGR?qs=bpu3f%2FCR1jxmQ5vho%252BhFHQ%3D%3D)
### 3.3V buck-boost
**RAA2361052GNP#HC5**
- Symbol, footprint, 3D: [Mouser]([https://www.mouser.be/ProductDetail/Texas-Instruments/BQ25630YBGR?qs=bpu3f%2FCR1jxmQ5vho%252BhFHQ%3D%3D](https://www.mouser.be/ProductDetail/Renesas-Intersil/RAA2361052GNPHC5?qs=olJun0bQHM%2FTMxAlNSaKDw%3D%3D))
### 3.3V buck-boost alternatief
**RT6158AWSC**
- Symbol, footprint, 3D: [Ultralibrarian](https://app.ultralibrarian.com/details/d01e2d83-aa6c-11ec-9033-0a34d6323d74/Richtek-Technology/RT6158HWSC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)
### 3.3V LDO
**TCR3UG33A,LF**
- Symbol, footprint, 3D: [Mouser](https://www.mouser.be/ProductDetail/Toshiba/TCR3UG33ALF?qs=0lQeLiL1qyaZy60Q7HF0yg%3D%3D), [Snapeda](https://www.snapeda.com/parts/TCR3UG33A%2CLF/Toshiba%20Semiconductor%20and%20Storage/view-part/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)
### 5V boost
**TPS61253F**
- Symbol: *zelf maken*
- Footprint & 3D: [Snapeda](https://www.snapeda.com/parts/DRV2625YFFR/Texas%20Instruments/view-part/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) (ander component met zelfde package)
	Zie [DBSGA-9](https://www.ti.com/lit/ml/mxbg144b/mxbg144b.pdf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) footprint eigenschappen
## Servo motor
TD-8120MG Digital Servo
**Pin header female ( 1x3 2.54mm)**
- Symbol: *zelf maken*
- Footprint: KiCad
	- [-] - *PinHeader_1x03_P1.00mm_Horizontal*
	- [-] - *PinHeader_1x03_P1.00mm_Vertical*
	- [-] - *PinHeader_1x03_P1.00mm_Vertical_SMD_Pin1Left*
	- [-] - *PinHeader_1x03_P1.00mm_Vertical_SMD_Pin1Right*
 - Footprint: KiCad - JST PH (zelf crimpen)
	 - Connector_JST:JST_PH_B3B-PH-K_1x03_P2.00mm_Vertical
- 3D **??**
## LED
**BL-BEG204-7-E**
- Symbol: ~~*zelf maken*~~
	- Zit al in KiCad: *LED_DUAL_KAK*
- Footprint zit al in KiCad:
	- *LED_D5.0mm-3*
	- *LED_D5.0mm-3_Horizontal_O3.81mm_Z3.0mm
	- Pads rond maken **??**
> - 5mm LED (5.7mm base diameter)
> - 3 pinnen (0.5mm), 2.45mm spacing
> - Red cathode - common anode - green cathode
> 		--------|<-------* -------->|------- 
## Hall sensors
**DRV5032DULPGM**
- Footprint, 3D: [Snapeda](https://www.snapeda.com/parts/DRV5032DULPGM/Texas%20Instruments/view-part/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)
- Symbol, footprint, 3D: [Mouser](https://www.mouser.be/ProductDetail/Texas-Instruments/DRV5032DULPGM?qs=OlC7AqGiEDk9MwfBkgsRPw%3D%3D)
## ST-link
STLINK-V3MINIE
**Card Edge Connector 009159010603906
- Dual Row Inverted 
- 2x5pos
- 2.0 mm pitch
- Polarized

Symbol, footprint, 3D: [Mouser](https://www.mouser.be/ProductDetail/KYOCERA-AVX/009159010603906?qs=ST9lo4GX8V1Mnrfaz2Mt1w%3D%3D)

# To do
### Zit al in KiCad
- [x] EEC chip symbol
- [x] STM32
- [x] E-ink header footprints
- [x] SD module header footprints
- [x] Servo pinheader footprint
- [x] LED symbol
- [x] LED footprint
### Downloaden
- [x] LoRa
- [x] GPS
- [x] FRAM
- [x] EEC chip
- [x] BMS - li-ion lader
- [!] BMS - 3,3V buck-boost
- [ ] BMS - 3,3V buck-boost alternatief
- [x] BMS - 3,3V LDO regulator
- [x] BMS - 5V boost footprint
- [x] Hall effect sensor
- [x] ST-link header
### Maken
- [x] E-ink header symbol
	%%Baseren op hall effect sensor (DRV5032DULPGM)
	Uitbreiden naar 8%%
- [-] E-ink footprint pinnen juiste richting (JST PH 8)
- [x] Accelerometer module symbol
	%%Baseren op FRAM (FM24V01A-GTR)%%
- [ ] Accelerometer module footprint
- [ ] EEC chip footprint
	- [x] Breakout/IC voet zoeken
	%%Baseren op%%
- [x] SD-kaart module header symbol
	%%Baseren op E-ink header symbool%%
	- [x] SD-kaart PinHeader_2x08 footprint: pinnen aanpassen (in paren)
- [x] BMS - 5V boost symbol
	- [x] Footprint koppelen / aanpassen
	%%Baseren op FRAM (FM24V01A-GTR)
	Pin 4 en 5 weg%%
- [x] Servo pinheader symbol
	%%Baseren op hall effect sensor (DRV5032DULPGM)%%
- [-] LED symbol
	%%Baseren op hall effect sensor (DRV5032DULPGM)%%
### Geimporteerd in KiCad
##### Bestaand
- [v] STM32 **STM32L431CCT6TR
- [v] LoRa **RAK11720**
- [v] LED **BL-BEG204-7-E**
##### Gedownload
- [v] GPS **Quectel LC76GPAMD**
- [v] FRAM **FM24V01A-GTR**
- [v] BMS - li-ion lader **BQ25630YBGR**
- [!] BMS - 3,3V buck-boost **RAA2361052GNP#HC5
- [ ] BMS - 3,3V buck-boost alternatief **RT6158AWSC**
- [v] BMS - 3,3V LDO regulator **TCR3UG33A,LF**
- [v] Hall effect sensor **DRV5032DULPGM**
- [v] ST-link header **009159010603906**
##### Gemaakt
- [v] E-ink module **Waveshare 1.54” module**
- [/] Accelerometer **LIS2DW12 module**
- [/] EEC chip **ATECC608B-SSHDA-T**
- [v] SD-kaart module  **SD adapter module**
- [v] BMS - 5V boost **TPS61253F**
- [v] Servo pinheader **Connector_JST:JST_PH_B3B-PH-K_1x03_P2.00mm_Vertical**

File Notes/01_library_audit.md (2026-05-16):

# KiCAD Library Audit — Bikera Smart Lock Prototype (development board)

**Source:** `Bikera.xlsx` → sheet `Basiscomponenten`, filtered on column **Keuze prototype = TRUE**
**Target:** KiCAD 9.x (stock libraries). Notes for KiCAD 8.x added where coverage differs.
**Goal:** Per BOM line, classify symbol + footprint as **STOCK** (in KiCAD's bundled libs), **3RD-PARTY** (SnapEDA / Ultra Librarian / vendor download), or **CUSTOM** (must be drawn by you).

Use this as the checklist before opening the schematic. Fetch all 3rd-party libs first, draw all CUSTOM symbols first, then capture in one pass. Around-the-IC passives (decoupling caps, pull-ups, LED resistors) are not enumerated in `Bikera.xlsx` — they ride on the generic stock symbols (`Device:R`, `Device:C`, `Device:LED`) with values set per the reference designs in each part's datasheet. Calculate them once during schematic capture (see `03_schematic_capture_guide.md`).

This is the **prototype** audit. The `Keuze finaal` design diverges in five places (RAK11720 RF-pinout instead of MHF4, wire/PCB antennas instead of FPC, no ePaper, RAA2361052 instead of RT6150B, SL1613SH/SL1623SH instead of DRV5032). When that pivot lands, redo this audit; the schematic and PCB guides will need rev-2 sections.

## Reconciliation with the architecture diagram

The drawio architecture diagram (`architectuur_design.jpg`) and `Bikera.xlsx` Keuze prototype rows disagree in two places:

| What | Diagram shows | BOM Keuze prototype shows | Authoritative |
|---|---|---|---|
| Charger | BQ25895RTWR (QFN-24, no USB-C detect) | BQ25630YBGR (DSBGA, USB-C detect) | **BOM (BQ25630YBGR)** |
| 3.3 V buck-boost | RAA2361052GNP#HC5 (DFN-10) | RT6150B (WDFN-10L) | **BOM (RT6150B)** |

The diagram appears to predate the BOM update. **The BOM is the source of truth** — when the diagram is regenerated to match BOM rev-current, update its blocks for the charger and buck-boost.

The diagram does contribute four real architectural details that are NOT obvious from `Bikera.xlsx` alone and that this audit picks up below:

1. **UART-to-USB bridge** as a separate component between USB-C D+/D− and the MCU (independent of the ST-link's VCP) — see Section 18
2. **Two physical push-buttons** for BOOT and RESET (not a BOOT jumper header) — covered in Section 1
3. **GPS backup power circuit** for V_BCKP — covered in Section 6
4. **Servo external current-sense resistor (Rsense)** with sense signal back to MCU ADC — covered in Section 13

## Legend

- **Symbol** column = the schematic symbol (the part's pinout drawing)
- **Footprint** column = the PCB land pattern
- "Generic" = use one of KiCAD's canonical generic symbols (e.g. `Device:R`, `Device:C`) with the BOM MPN entered as the `Value` or `MPN` field
- 3rd-party recommendation: **SnapEDA** is preferred (free, KiCAD-native exports). **Ultra Librarian** as fallback. **Vendor** (RAKwireless, Coilcraft, Mouser-AVX) where they ship official KiCAD libs.

---

## Section 1 — MCU

| Ref | MPN | Symbol | Footprint | Plan |
|---|---|---|---|---|
| U1 | STMicroelectronics **STM32L431CCT6TR** | **STOCK** `MCU_ST_STM32L4:STM32L431CCTx` | **STOCK** `Package_QFP:LQFP-48_7x7mm_P0.5mm` | Both stock. Verify pin 1 marking corner against ST datasheet rev. 7 fig. 14 before locking. The `T` suffix = LQFP-48; `R` suffix would be UFQFPN-32 — make sure the symbol variant matches the BOM's `CCT6TR` ordering code |
| Decoupling | Generic 100 nF 0603 (×4) + 1 µF 0603 (×1) + 10 nF 0603 (×1) | **STOCK** `Device:C` | **STOCK** `Capacitor_SMD:C_0603_1608Metric` | Per ST AN2867 / datasheet sec 6.1.6: one 100 nF per VDD pin (3 pairs on LQFP-48), one 100 nF on VDDA, one 10 nF on VDDA in parallel (HF), one 1 µF bulk on VDDA |
| Reset / boot buttons (×2) | SPST momentary tactile, 6×6 mm THT or 4.5×4.5 mm SMD | **STOCK** `Switch:SW_Push` | **STOCK** `Button_Switch_THT:SW_Tactile_SPST_Angled_PTS645Vx39-2LFS` or `Button_Switch_SMD:SW_SPST_TL3342` | Two buttons per the architecture diagram's "Drukknoppen" block: one labelled **BOOT** (pulls BOOT0 high momentarily for system bootloader entry), one labelled **RESET** (pulls NRST low). Per STM32L431 datasheet Figure 30, the NRST pin has an **internal pull-up**, so the recommended external circuit is just a 0.1 µF cap to GND — **no external 10 kΩ pull-up needed**. Add 10 kΩ pull-down on BOOT0 (no internal pull on BOOT0 in the L431). Stock everything |

**Verdict:** all stock. No downloads needed for this section.

---

## Section 2 — LoRa + BLE module (MHF4 variant)

| Ref | MPN | Symbol | Footprint | Plan |
|---|---|---|---|---|
| U2 | RAKwireless **RAK11720 (MHF4 connector variant)** | **3RD-PARTY** | **3RD-PARTY** | SnapEDA has this part: search "RAK11720". **Critical:** the MHF4 and RF-pinout variants share most of the footprint but differ in their RF I/O — the MHF4 variant has the antenna connector pre-soldered on the module, so on your PCB the RF lands as routed signals to the module's edge are **not used**. Make sure SnapEDA's variant matches the `Keuze prototype` selection. The RAKwireless official KiCAD lib at `https://downloads.rakwireless.com/3D_File/WisDuo/` is the cleanest source — same lib hosts the 3D STEP. **Pin headers along the module edge are still routed to the MCU** even though the RF doesn't exit through them |

> **Variant matters:** `Bikera.xlsx` selected the **MHF4 connector** variant for the prototype. This means each antenna (LoRa, BLE) plugs onto the module's MHF4 jack via a U.FL/MHF4 pigtail to a separate FPC antenna — there are no RF traces between the module and the antennas on the PCB. The advantage for prototype: no controlled-impedance routing on your board. The disadvantage for production: extra parts (two MHF4 cables, two FPC antennas + adhesive). The `Keuze finaal` design switches to the RF-pinout variant — when you go to rev 2 this section changes substantially.

> **⚠ Build/assembly warning (per RAK datasheet):** "Make sure that an antenna is always connected. Using these transceivers without an antenna can damage the module." During bring-up, **plug in both antennas (or 50 Ω terminators) before powering the board for the first time.** Don't power-on a bare RAK11720 to "test the rails first" — the LoRa PA stage can self-damage if it transmits into an open circuit. Add this to the bring-up checklist in `04_pcb_layout_guide.md`.

> **Default UART config:** UART0 at 115200 baud, 8N1. AT command protocol per RAKwireless's "RAK11720 AT Command Manual". Default firmware = RUI3. Other UART settings configurable post-factory via AT commands. Sleep current ~2.37 µA per RAK datasheet — important for battery-life calculations.

### Decoupling

| What | Per RAKwireless datasheet sec. 4.2 |
|---|---|
| 10 µF (1206) + 100 nF (0603) | On VBAT input |
| 1 µF (0603) + 100 nF (0603) | On VDD_IO |

All stock `Device:C` symbol + stock 0603/1206 footprints.

**Verdict:** 1 SnapEDA or RAKwireless lib pull. Rest stock.

---

## Section 3 — LoRa antenna (FPC, off-board)

| Ref | MPN | Symbol | Footprint | Plan |
|---|---|---|---|---|
| ANT1 | Farnell **L000551-05 FPC antenna** (2.2 dBi, 868 MHz, MHF4 cable) | n/a (off-board — connects to U2's MHF4 jack via the included pigtail) | n/a | Documented in BOM only; no schematic symbol, no PCB footprint. The antenna is a flexible PCB part that adheres to the inside of the lock enclosure with its supplied adhesive; the MHF4 connector mates with the RAK11720's RF jack |

> **Mechanical note:** the FPC antenna ships with a 5/10/15 cm cable option. Pick **before ordering** based on enclosure size — too long means antenna performance loss in the coil; too short means you can't reach the mounting position. The prototype enclosure size determines this choice.

**Verdict:** nothing in KiCAD. Track in BOM and assembly drawing.

---

## Section 4 — BLE antenna (FPC, off-board)

| Ref | MPN | Symbol | Footprint | Plan |
|---|---|---|---|---|
| ANT2 | Digikey **AANI-FB-0086-0100W** (100 mm FPC, multi-band including 2.4 GHz, MHF4 cable) | n/a (off-board) | n/a | Same approach as ANT1 — plugs into the second MHF4 jack on the RAK11720 |

> **Datasheet caveat:** this antenna is marketed as a Wi-Fi 6E/7 tri-band antenna. The 2.4 GHz band is included in its operating range, but its tuning is optimised across the full Wi-Fi band span (2.4 / 5 / 6 GHz). For BLE-only use it's overkill but works fine. If first build shows weak BLE range, this antenna is a candidate for swap-out before suspecting anything else.

**Verdict:** nothing in KiCAD. Track in BOM.

---

## Section 5 — ECC secure element

| Ref | MPN | Symbol | Footprint | Plan |
|---|---|---|---|---|
| U3 | Microchip **ATECC608B-SSHDA-T** | **STOCK** `Security_IC:ATECC608A-SSH` (or similar — KiCAD's `Security_IC` library has the ATECC family). Verify A vs B variant in symbol description | **STOCK** `Package_SO:SOIC-8_3.9x4.9mm_P1.27mm` | KiCAD 9.x stock library has ATECC608 family symbols. **The 608A and 608B differ in some internal features (TempKey behaviour, OTP commands) but are pin-compatible** — using the 608A symbol with the value set to "ATECC608B-SSHDA-T" is acceptable. SnapEDA also has dedicated 608B symbols if you want exact-match metadata |
| Socket (prototype) | DIP/SOIC-8 ZIF socket | **CUSTOM** symbol (just a 1×8 header) | **CUSTOM** footprint matching the socket's pin pitch | Per `Readme.md`: "EEC chip: Met socket". A SOIC-8 socket lets you swap pre-provisioned chips without resoldering — invaluable during firmware development of the ECDSA signing flow in `bikera.ino`. The socket footprint is just an SOIC-8 land pattern with through-holes at the corners for retention; you can search "SOIC-8 ZIF socket" on Aliexpress / Digikey to find the specific part and download its drawing. Alternative: solder the bare SOIC-8 chip directly and accept that chip swap means hot-air reflow |
| Decoupling | 100 nF 0603 | **STOCK** `Device:C` | **STOCK** 0603 | One next to VCC |

**Verdict:** STOCK symbol + STOCK footprint for the bare chip. If you go with the socket, that's one custom item — but the **bare chip is the safer prototype choice** because sockets add height, cost, and another mechanical failure point. The chip is €0.76; if you brick a chip during provisioning, throw it away and reflow another. The socket is only worth it if you expect to swap >5 chips during development.

---

## Section 6 — GPS module

| Ref | MPN | Symbol | Footprint | Plan |
|---|---|---|---|---|
| U4 | Quectel **LC76GPAMD** | **3RD-PARTY** | **3RD-PARTY** | Ultra Librarian: search `LC76GPAMD` ([direct link from `Notes/Symbols and footprints.md`](https://app.ultralibrarian.com/details/e7452cf1-f8e7-11ed-b159-0a34d6323d74/Quectel-Wireless-Solutions/LC76GPAMD)). SnapEDA also covers it for the 3D STEP. Half-hole castellated PCB module — the footprint must include the castellation cutouts AND the under-module copper keepout per Quectel's "LC76G Hardware Design" doc sec. 7.2 |
| VCC decoupling | TVS + 10 µF + 100 nF + 33 pF | **STOCK** | **STOCK** | Per LC76G Hardware Design fig. 4 (VCC input reference circuit). The 33 pF cap is HF decoupling — don't omit it; it suppresses RF noise at the LC76G's internal LNA reference. The TVS on VCC is SMBJ5.0CA or equivalent low-capacitance bidirectional TVS (NOT SMBJ58CA — that's 58 V standoff, far too high for a 3.3 V rail). See Section 19 for TVS selection |
| VBACKUP backup-power circuit | Schottky diode-OR + supercap + TVS + 4.7 µF + 100 nF + 33 pF | **STOCK** | **STOCK** | The architecture diagram shows a "GPS backup power circuit" as a separate block feeding V_BCKP. Per LC76G Hardware Design fig. 5 (V_BCKP input reference), the decoupling triplet is **4.7 µF + 100 nF + 33 pF** (note: 4.7 µF, not 10 µF — the V_BCKP current is lower) plus a TVS. Combine with the diode-OR: 1× BAT54C dual Schottky (`Diode:BAT54C`, stock `Package_TO_SOT_SMD:SOT-23`) diode-OR-ing from `+3V3_GPS` and a 0.1 F supercap, the supercap charging from `+3V3` via a 1 kΩ resistor. **If you want simpler bring-up first**, leave V_BCKP NC and accept cold-start on every boot — the schematic stays cleaner. The backup circuit can be added in rev 2 without affecting anything else |
| GPS antenna RF protection | TVS on antenna line | **3RD-PARTY** | **STOCK** SOD-323 | LC76G Hardware Design fig. 17 (passive antenna reference) shows a TVS diode on the RF line between the antenna connector and the module RF pin. Use a low-capacitance ESD TVS specifically rated for RF (e.g. SMF05C, PESD5V0X1BSF, or similar — junction capacitance <2 pF, breakdown >5 V). **Do NOT use SMBJ family TVS on the RF line** — their junction capacitance (50–500 pF) detunes the antenna match. SMBJ family is OK for power-rail protection only |
| RF matching / SAW filter | π-network or SAW filter, optional | n/a | n/a | LC76G Hardware Design fig. 17 shows C1/C2 (marked NM = not mounted) and an optional SAW filter. For prototype with FPC passive antenna: **leave NM, skip the SAW**. Add only if first build shows poor sensitivity or interference from on-board sources |
| D_SEL strap | Pulled low for UART | **STOCK** `Device:R` | **STOCK** 0603 | Per LC76G Hardware Design Table 8: D_SEL low at startup = UART interface (which is what we want). Tie D_SEL to GND via 10 kΩ — don't leave floating, don't tie directly to GND (preserves option to override via MCU GPIO later) |

**Verdict:** 1 Ultra Librarian or SnapEDA pull. Verify castellation pads with the printed-footprint method (see `02_footprints_explained.md`).

---

## Section 7 — GPS antenna (FPC, off-board)

| Ref | MPN | Symbol | Footprint | Plan |
|---|---|---|---|---|
| ANT3 | Quectel **YFGA003AA** (10 cm FPC, RF1/IPEX-1 connector) | n/a (off-board) | n/a | The RF-1 (IPEX MHF/U.FL-1, 1st gen) connector is the GPS antenna's mate. The LC76GPAMD module exposes the RF pin as a half-hole pad, not a connector — so you need either (a) an IPEX-1 jack on your PCB next to the module + the antenna's cable plugs into it, or (b) a soldered pigtail from the LC76GPAMD's RF pad to the antenna's connector |
| J-gps-ant | IPEX MHF1 / U.FL receptacle (on PCB) | **3RD-PARTY** | **3RD-PARTY** | SnapEDA: search "U.FL" or "Hirose UFL-LP-068". Stock KiCAD has `Connector_Coaxial:U.FL` which is generic — fine if you accept the placeholder footprint, but check pad dimensions against the specific receptacle you buy. **Architecture sheet refers to this as "RF 1 connector"** — same thing |

> **Routing critical:** the trace from the LC76GPAMD RF pad to the U.FL receptacle must be 50 Ω controlled impedance. On standard 1.6 mm FR4 with 1 oz copper and a solid ground plane on layer 2, a 50 Ω microstrip is ~2.85 mm wide — too wide for a typical 1 mm half-hole pad. **Use a coplanar waveguide with ground (CPWG) instead** — narrower trace (~1.2 mm) with ground flooded on the same layer, stitched with vias. See `04_pcb_layout_guide.md`.

**Verdict:** 1 SnapEDA pull (U.FL receptacle). FPC antenna itself is BOM-only.

---

## Section 8 — ePaper display

| Ref | MPN | Symbol | Footprint | Plan |
|---|---|---|---|---|
| MOD1 | Waveshare **1.54" e-Paper Module** (8-pin JST PH 2.0 mm input) | **CUSTOM** symbol — header carrier | **STOCK** `Connector_JST:JST_PH_B8B-PH-K_1x08_P2.00mm_Vertical` (per `Notes/Symbols and footprints.md`) | The module itself is off-board, sitting in the lock enclosure connected via the 8-pin JST PH cable supplied. On your PCB you mount one JST PH 8-pin header; the module's cable plugs into it. **Custom symbol** = an 8-pin connector with the Waveshare pinout labelled correctly (VCC, GND, DIN, CLK, CS, DC, RST, BUSY) so the schematic reads cleanly |

> **Cable variant:** the Waveshare module ships with the JST PH cable terminating in **8 individual Dupont connectors** by default (per `Notes/Symbols and footprints.md`). For the prototype, either (a) re-crimp the cable into a JST PH housing, or (b) use 8× 2.54 mm pin header on the PCB to match the Dupont ends. The Notes file shows both options were considered — pick one and document. **Recommendation: use the JST PH receptacle on PCB and re-crimp the cable** — Dupont connectors flap loose under bike vibration

### MOSI/SCK sharing

The ePaper SPI bus shares MOSI and SCK with the SD card module (per the architecture sheet). On the schematic, both peripherals connect to the same `SPI_MOSI` and `SPI_SCK` nets; each has its own CS line. Don't accidentally draw separate SPI buses — the MCU has only 3 SPI peripherals total and you want to leave at least one for the accelerometer's SPI mode option.

**Verdict:** custom 8-pin header symbol, stock JST footprint.

---

## Section 9 — Accelerometer (breakout module)

| Ref | MPN | Symbol | Footprint | Plan |
|---|---|---|---|---|
| MOD2 | Tinytronics **LIS2DW12 module** (DFRobot Fermion DFR0904 or equivalent breakout) | **CUSTOM** symbol — 2× 1×4 headers | **STOCK** `Connector_PinHeader_2.54mm:PinHeader_1x04_P2.54mm_Vertical` (×2) | Two 4-pin headers per the architecture sheet. On the schematic it shows up as a pair of 1×4 headers; on the PCB it's two `PinHeader_1x04_P2.54mm_Vertical` footprints aligned to the module's hole pattern. Pin assignment per the module's actual pinout (verify against the Tinytronics product page — different breakout sources have different pinouts) |

**Module power note (per detail sheet):** the LIS2DW12 breakout module includes its own onboard 3.3 V LDO (typically **ME6206A33M3G** or similar). The board takes higher voltage at VCC and regulates it internally to 1.8/3.3 V for the bare chip. **Wire the breakout's VCC to `+3V3` directly** — the onboard LDO will pass through (it's a low-dropout part). Some clones omit the LDO and feed VCC straight to the chip — verify before buying. If your specific breakout has no LDO, the LIS2DW12 chip itself accepts 1.62–3.6 V at VDD so `+3V3` is still fine, just don't apply >3.6 V.

**CS pin (per LIS2DW12 datasheet Table 1 footnote + Table 2):** the LIS2DW12 has internal pull-ups on **both** SDO/SA0 AND CS pins (typical 50 kΩ at 1.8 V Vdd_IO, dropping to ~20 kΩ at 3.6 V). Earlier draft of this guide stated CS had no internal pull-up — **that was wrong; the AN5038 application note and datasheet Table 1 footnote both confirm CS is pulled up internally**. Practical implications:

| Option | Wiring | Notes |
|---|---|---|
| Leave CS floating (internal pull-up holds it high) | NC on the header | Works for I²C mode, but ST recommends an explicit external tie for noise immunity |
| Tie CS to Vdd_IO (=`+3V3` on this breakout) | Direct connection at header | **Recommended for production.** Per datasheet sec. 6.2: "When using the I²C, CS must be tied high (i.e. connected to Vdd_IO)" |
| Pull-up CS via 10 kΩ + MCU GPIO override | 10 kΩ to `+3V3` + GPIO | Preserves SPI mode option. Costs 1 GPIO and 1 resistor |

**Recommendation for the Bikera prototype:** tie CS directly to the breakout's VCC pin via a short trace at the header. I²C is the chosen interface and there's no compelling reason to keep SPI as a runtime option. If you want the flexibility, route to a spare GPIO instead — both approaches are documented in AN5038.

**Pin assignment** (typical, but VERIFY for your specific module):

Header A: VCC, GND, SDA, SCL
Header B: INT1, INT2, SDO/SA0, CS

> **I²C vs SPI mode:** the LIS2DW12 supports both. In I²C mode, CS=high, SA0 selects address (0x18 / 0x19). In SPI mode, CS becomes the chip-select. The architecture sheet shows both — the prototype defaults to I²C for fewer wires. SPI is an option if I²C bus loading becomes an issue, but the bus only has 4 slaves (ECC, FRAM, accelerometer, charger) at relaxed I²C speeds, so I²C is fine

**Verdict:** custom pair of header symbols + STOCK footprints. Verify the breakout's actual pin spacing with calipers.

---

## Section 10 — SD card breakout

| Ref | MPN | Symbol | Footprint | Plan |
|---|---|---|---|---|
| MOD3 | Tinytronics **SD adapter module** (8×2 pin header per `Readme.md` / Notes file) | **CUSTOM** symbol — 2×8 header | **STOCK** `Connector_PinHeader_2.54mm:PinHeader_2x08_P2.54mm_Vertical` or `_Horizontal` | The Tinytronics SD module specified in `Bikera.xlsx` row 27 is the 3.3V/5V variant with built-in level shifter. It exposes 8 pins per row (pairs) — per `Notes/Symbols and footprints.md` "SD-kaart PinHeader_2x08 footprint: pinnen aanpassen (in paren)". Half the pins are duplicates (each functional pin has a paired duplicate) so the symbol shows 8 nets, 16 pads |
| R-sd | 4.7–10 kΩ pull-ups on CS, MOSI, MISO | **STOCK** `Device:R` | **STOCK** 0603 (×3) | Standard SD SPI practice. Required even if the module has its own pull-ups — module pull-ups don't always engage until SD is in SPI mode |

**Verdict:** custom symbol (one-time draw), stock footprint. Measure the actual breakout to verify the 2×8 pitch and which pins are paired.

---

## Section 11 — FRAM

| Ref | MPN | Symbol | Footprint | Plan |
|---|---|---|---|---|
| U5 | Infineon (Cypress) **FM24V01A-GTR** | **3RD-PARTY** | **STOCK** `Package_SO:SOIC-8_3.9x4.9mm_P1.27mm` | SnapEDA: [FM24V01A-GTR](https://www.snapeda.com/parts/FM24V01A-GTR/Cypress%20Semiconductor/view-part/) for the symbol. The footprint is stock SOIC-8 — you could skip the SnapEDA pull for the footprint and just use the stock one; the SnapEDA symbol is the value-add. Address pins A0/A1 (A2 is no-connect per datasheet sec. 3.1) |
| Decoupling | 100 nF 0603 | **STOCK** | **STOCK** | One next to VDD |
| R-wp | Optional — pin internally pulled down per datasheet | **STOCK** `Device:R` | **STOCK** 0603 | The FM24V01A-GTR datasheet explicitly states WP "is pulled down internally" (same for A0, A1, A2). **You can leave WP NC and the chip defaults to write-enabled.** If you want write-protect under firmware control, route WP to a MCU GPIO. If you want write-protect always on, tie WP directly to VDD (no resistor). My earlier draft had an external 10 kΩ pull-down — redundant with the internal one. Drop it |
| Addressing | A0, A1, A2 internally pulled down — defaults to 0x50 | n/a | n/a | Same internal pull-down. Default address 0x50 is what you want with a single FRAM on the bus. No external pull-downs needed |

**Verdict:** SnapEDA for the symbol only; stock footprint.

---

## Section 12 — Battery management
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

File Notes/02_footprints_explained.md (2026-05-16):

# Bikera — Footprint Files Explained (Prototype Build)

**Companion to `01_library_audit.md`.** That doc said *what* to fetch and *what* to draw. This doc explains the **contents** of the actual `.kicad_mod` and `.kicad_sym` files for every non-stock part on the prototype board — what's inside them, what the dimensions mean, how to spot-check them before fab, and what to do when verification fails.

The order below matches the audit's section numbering, but skips sections that are stock-only (1 MCU passives, 3 LoRa antenna FPC-off-board, 4 BLE antenna FPC-off-board, 13 servo, 14 LED, 17 passives roll-up).

## Repository convention

```
hardware/kicad/
├── bikera.kicad_pro
├── bikera.kicad_sch
├── bikera.kicad_pcb
├── custom_lib/
│   ├── bikera_custom.kicad_sym           ← custom symbols (ePaper, LIS2DW12, SD module)
│   └── BikeraCustom.pretty/              ← (empty for prototype — no custom footprints needed)
├── third_party_lib/
│   ├── rakwireless/                      ← official RAK lib (RAK11720)
│   ├── snapeda/                          ← per-part subdirs
│   │   ├── BQ25630YBGR/
│   │   ├── LC76GPAMD/
│   │   ├── RT6150B/
│   │   ├── TCR3UG33A/
│   │   ├── TPS61253F/
│   │   ├── FM24V01A-GTR/
│   │   ├── DRV5032DULPGM/
│   │   ├── USBLC6-2SC6/
│   │   └── GCT_USB4105-GF-A-060/
│   ├── ultralibrarian/
│   │   └── LC76GPAMD/                    ← alternate source for verification
│   ├── coilcraft/                        ← official Coilcraft inductor lib
│   ├── hirose/                           ← U.FL receptacle
│   └── kyocera_avx/                      ← card edge connector
├── 3d/
│   ├── RAK11720.step
│   ├── LC76GPAMD.step
│   ├── BQ25630YBGR.step
│   ├── 009159010603906.step
│   └── ...
└── datasheets/                           ← keep alongside the libs
    ├── STM32L431CC_rev7.pdf
    ├── RAK11720_datasheet_rev1.7.pdf
    ├── LC76G_hardware_design_rev1.pdf
    ├── BQ25630_datasheet.pdf
    ├── RT6150B_datasheet.pdf
    ├── TCR3UG33A_datasheet.pdf
    ├── TPS61253F_datasheet.pdf
    ├── FM24V01A_datasheet.pdf
    ├── ATECC608B_summary.pdf
    ├── DRV5032_datasheet.pdf
    └── UM2910_STLINK_V3MINIE.pdf
```

**Why colocate datasheets:** when you're verifying a footprint two months from now and the SnapEDA page has been updated, you want the exact datasheet revision the original footprint was drawn from. The KiCAD library lives or dies on whether its dimensions match what the manufacturer is currently shipping.

## How to load these libraries in KiCAD 9

1. **Preferences → Manage Symbol Libraries → Project Specific**
   - Add row: nickname `bikera_custom`, path `${KIPRJMOD}/hardware/kicad/custom_lib/bikera_custom.kicad_sym`
   - Add one row per third-party `.kicad_sym` (e.g. `rakwireless`, `snapeda_bq25630`, etc.)
2. **Preferences → Manage Footprint Libraries → Project Specific**
   - Add row: nickname `BikeraCustom`, path `${KIPRJMOD}/hardware/kicad/custom_lib/BikeraCustom.pretty`
   - Add one row per third-party `.pretty` folder
3. **3D model paths** reference `${KIPRJMOD}/hardware/kicad/3d/<file>.step` so the project is portable across team machines.

---

## Section 2 — RAK11720 (LoRa + BLE module, MHF4 variant)

**Source preference:** RAKwireless official KiCAD library at `https://downloads.rakwireless.com/3D_File/WisDuo/` — same page hosts the 3D STEP. SnapEDA is the fallback.

### What's inside the symbol

The RAK11720 MHF4 variant has ~30 pins exposed on its castellated edge. **Critically, the two RF nets do NOT appear as routable pins** on the MHF4 variant — they are pre-routed inside the module to the two MHF4 connector jacks. The pins you wire on your PCB are:

- Power: VBAT (typ. 3.3 V), VDD_IO, multiple GND pins
- UART0: TXD, RXD (for AT commands to host MCU)
- Optional UART1
- Reset (NRESET), BOOT pin
- GPIO breakouts (some unused)
- I²C, SPI optional breakouts
- Status pins (LED outputs from module's internal logic)

**Pin type assignments in the symbol matter for ERC.** Power pins must be `power_in`; the unused module pins are `passive` or `not_connected`. Leave the GPIOs that you don't use as `passive` and tie them to the `~/NC` marker in the schematic so ERC doesn't warn.

### What's inside the footprint

A castellated half-hole pattern around three sides of a ~15.0 × 23.5 mm module body:

- Castellated pads ~0.6 mm wide × ~1.2 mm long, on roughly 1.1 mm pitch on two of the sides
- Body silkscreen outline + pin 1 dot
- An under-module copper keepout — the RAK11720 MHF4 variant has the MHF4 jacks on the top side and a ground reference on the bottom side, so the keepout under the module is for the antenna routing **inside the module**, not for your traces. You can place stitching vias under the module but NOT signal traces
- Two MHF4 connector body locations marked on F.Fab for clearance reference (where the antenna pigtails will exit)
- 3D STEP reference matching the module + MHF4 connectors
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

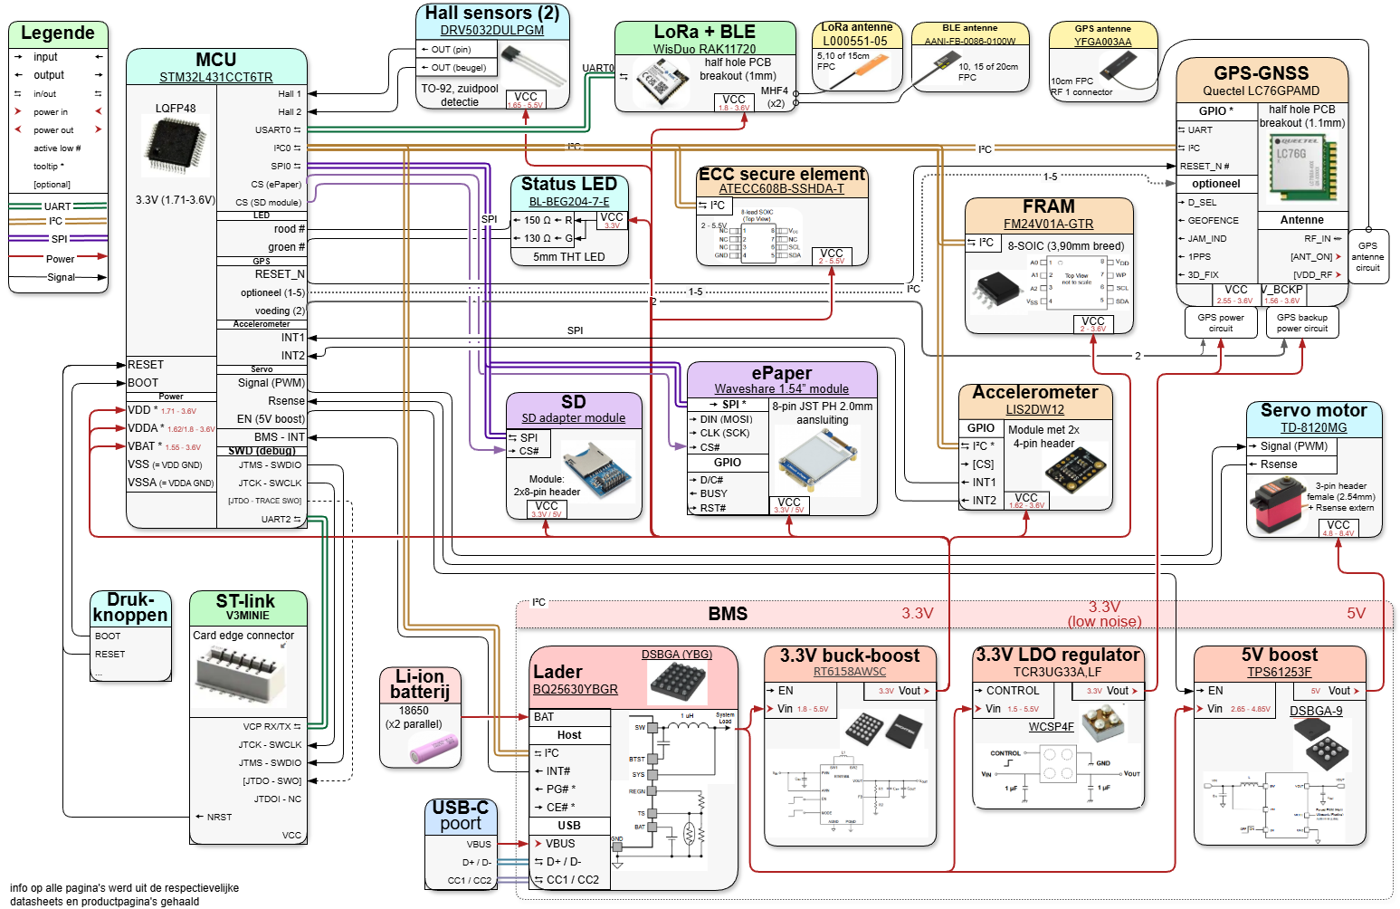
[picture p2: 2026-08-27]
Architectuurschema export png/Architectuur schema-Architecture design.drawio.png

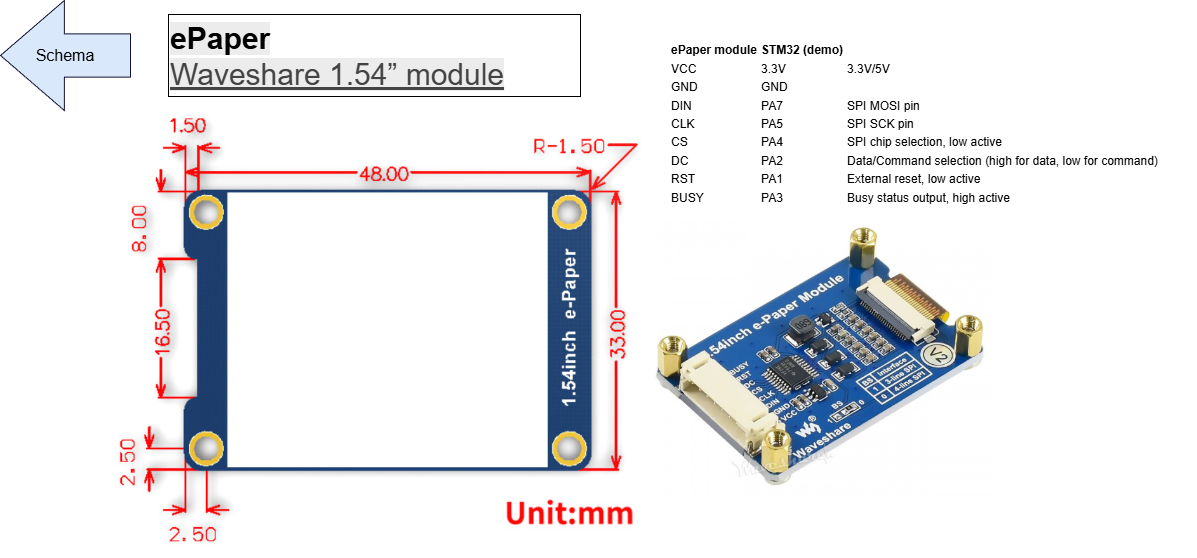
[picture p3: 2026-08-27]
Architectuurschema export png/Architectuur schema-ePaper.drawio.png

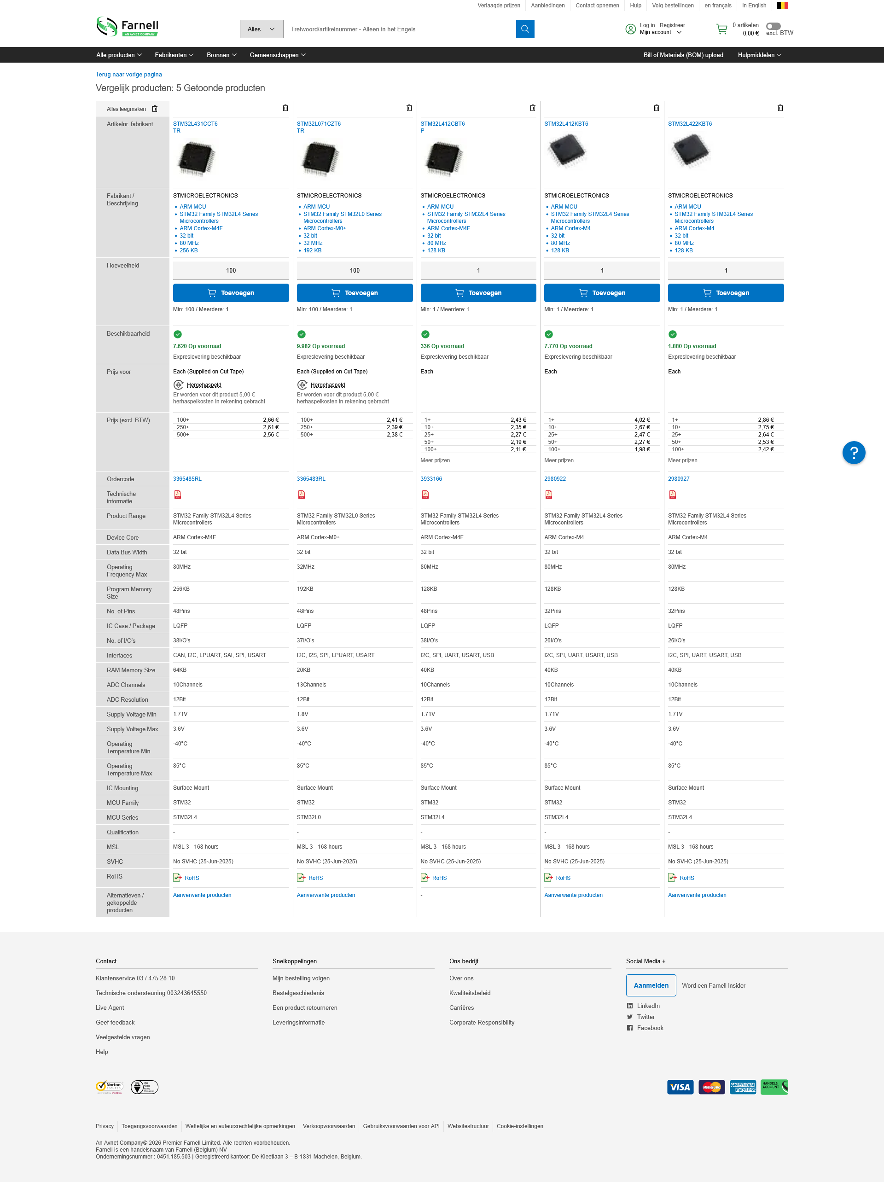
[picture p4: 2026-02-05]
Farnell STM32 vergelijking.png

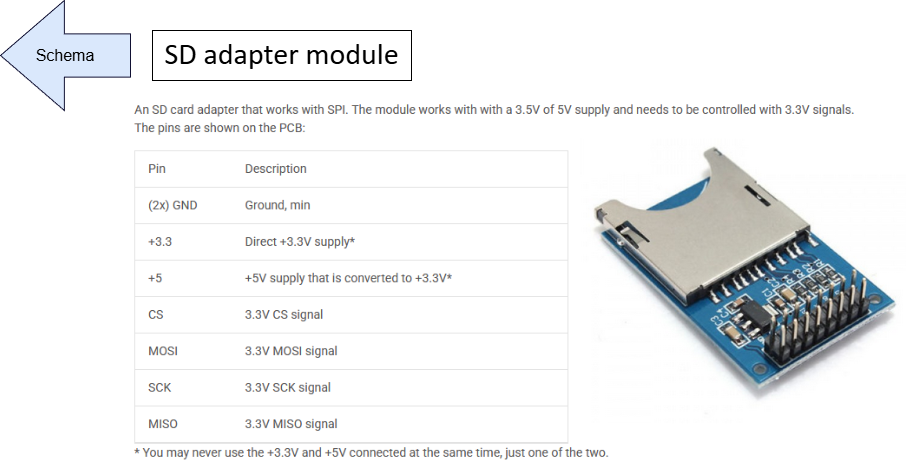
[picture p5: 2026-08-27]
Architectuurschema export png/Architectuur schema-SD.drawio.png

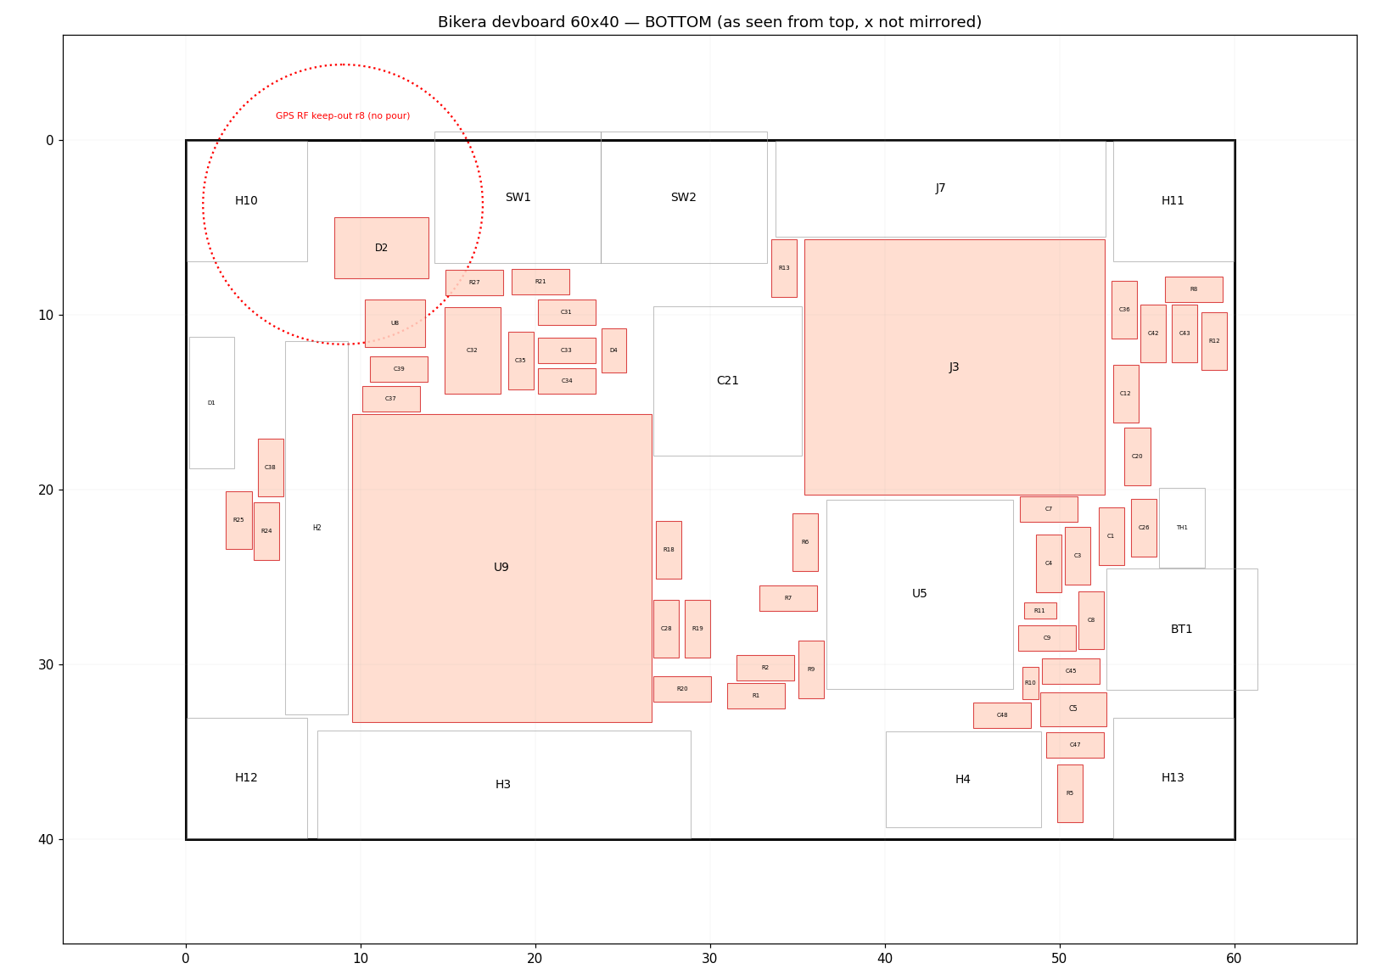
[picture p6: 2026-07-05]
Kicad_v2/layout_bottom_plan.png

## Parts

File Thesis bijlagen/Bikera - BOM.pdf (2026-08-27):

Bikera | BOM
27-8-2026 | 1
Onderdeel | Type | Component | Opmerking | Waarde | Vorm | Distributeur | # | € (1) | €€ | Symbool | Footprint | link
LoRa antenne | Antenne | FPC antenne | 2.2dBi, VSWR 1.5
Optie voor 5, 10 of 15cm kabel | FPC antenne (5, 10 of 15cm kabel) Farnell | 1 | 0 | - | - | https://be.farnell.com/te-connectivity/l000551-05/rf-antenna-863-to-870mhz-2-2dbi/dp/4457734
BLE antenne | Antenne | AANI-FB-0086-0100W (100mm) Optie voor 10, 15 of 20cm kabel | FPC antenne (10, 15 of 20cm kabel) Digikey | 1 | € 2,57 | 2,57 | - | - | https://www.digikey.be/nl/products/detail/abracon-llc/AANI-FB-0086-0100W/25558929
GPS antenne | Antenne, Extern | YFGA003AA | FPC antenne, RF 1 connector | - | FPC antenne (10cm kabel) | Digikey | 1 | € 1,32 | 1,32 | - | - | https://www.digikey.be/nl/products/detail/quectel/YFGA003AA/21273116
EEC chip | Breakout, THT | FIT0290 | inclusief pin headers | - | DIP-8 | Digikey | 1 | € 0,48 | 0,48 | - | - | https://www.digikey.nl/en/products/detail/dfrobot/FIT0290/6588424
STM32, GPS/GNSS | C, SMD | CC0603KPX5R6BB475 | idem | 4,7µF | 0603 | Mouser | 2 | € 0,24 | 0,482 | Device:C | Capacitor_SMD:C_0603_1608Metric Capacitor_SMD:C_0603_1608Metric_Pad1.08x0.95mm_HandSolder
STM32, LoRa, Accelerometer, BMS - li-ion lader, BMS - 3,3V LDO regulator C, SMD | | CC0603KPX5R6BB105 | idem | 1µF | 0603 | Mouser | 6 | € 0,11 | 0,672 | Device:C | Capacitor_SMD:C_0603_1608Metric Capacitor_SMD:C_0603_1608Metric_Pad1.08x0.95mm_HandSolder
STM32 | C, SMD | CC0603KRX7R6BB103 | idem | 10nF | 0603 | Mouser | 2 | € 0,09 | 0,172 | Device:C | Capacitor_SMD:C_0603_1608Metric Capacitor_SMD:C_0603_1608Metric_Pad1.08x0.95mm_HandSolder
LoRa, GPS/GNSS, BMS - li-ion lader, BMS - 3,3V buck-boost, BMS - 5V boost C, SMD | | CC0603KRX5R6BB106 | - | 10µF | 0603 | Mouser | 11 | € 0,22 | 2,464 | Device:C | Capacitor_SMD:C_0603_1608Metric Capacitor_SMD:C_0603_1608Metric_Pad1.08x0.95mm_HandSolder
GPS/GNSS | C, SMD | CC0603JRNPO9BN330 | VCC power circuit: zie hardware design p.26 33pF | | 0603 | Mouser | 2 | € 0,09 | 0,172 | Device:C | Capacitor_SMD:C_0603_1608Metric Capacitor_SMD:C_0603_1608Metric_Pad1.08x0.95mm_HandSolder

https://www.mouser.be/ProductDetail/YAGEO/CC0603KPX5R6BB475?qs=mzRxyRlhVdtG7wG2BIZZbA%3D%3D

https://www.mouser.be/ProductDetail/YAGEO/CC0603KPX5R6BB105?qs=57cj7OiSijl3rhe8DpTm1Q%3D%3D

https://www.mouser.be/ProductDetail/YAGEO/CC0603KRX7R6BB103?qs=Jp%252B3Pqv7Js0lWCO1g7PSqg%3D%3D

https://www.mouser.be/ProductDetail/YAGEO/CC0603KRX5R6BB106?qs=xUHcaXrTGSp1z%252B%2FOujzENw%3D%3D

https://www.mouser.be/ProductDetail/YAGEO/CC0603JRNPO8BN330?qs=57cj7OiSijlQ0%252B8Y1xsUZw%3D%3D

GPS/GNSS | C, SMD | CPH3225A-LF | GPS-backup: houdt RTC + ephemeris bij stroomuitval 0,1F | SMD (3225) | Mouser | 1 | € 2,20 | 2,2 | Device:C | Capacitor_SMD:C_1210_3225Metric_Pad1.33x2.70mm_HandSolder https://www.mouser.be/ProductDetail/Seiko-Semiconductors/CPH3225A?qs=3etwrb1wR%252BhUOph6lAO7eg%3D%3D
GPS antenne | C, SMD | bepalen bij meting! | Pad voorzien, waarde bepaald na meting; zie hardware design p.40 DNP | | 0402 | | 2 | | 0 | Device:C | Capacitor_SMD:C_0402_1005Metric Capacitor_SMD:C_0402_1005Metric_Pad0.74x0.62mm_HandSolder
BMS - li-ion lader, BMS - 5V boost | C, SMD | CC0603KRX5R6BB475 | Multilayer Ceramic Capacitors MLCC - SMD/SMT 10V 4.7uF X5R 0603 10% HI CV 4,7µF | | 0603 | Mouser | 4 | € 0,22 | 0,896 | Device:C | Capacitor_SMD:C_0603_1608Metric Capacitor_SMD:C_0603_1608Metric_Pad1.08x0.95mm_HandSolder
BMS - li-ion lader | C, SMD | CC0603KRX7R7BB473 | - | 47nF | 0603 | Mouser | 1 | € 0,10 | 0,095 | Device:C | Capacitor_SMD:C_0603_1608Metric Capacitor_SMD:C_0603_1608Metric_Pad1.08x0.95mm_HandSolder
BMS - 3,3V buck-boost | C, SMD | CC0603JRNPO9BN560 | | 56pF | 0603 | Mouser | 1 | € 0,10 | 0,095 | Device:C | Capacitor_SMD:C_0603_1608Metric Capacitor_SMD:C_0603_1608Metric_Pad1.08x0.95mm_HandSolder
Motor | C, SMD | CC0603KRX7R6BB333 | idem | 33nF | 0603 | Mouser | 1 | € 0,10 | 0,103 | Device:C | Capacitor_SMD:C_0603_1608Metric Capacitor_SMD:C_0603_1608Metric_Pad1.08x0.95mm_HandSolder
STM32, LoRa, EEC chip, GPS/GNSS, Accelerometer, FRAM chip, BMS - li-ion lader, Motor, Hall effect sensor C, SMD, alternatief | | CC0603KRX7R6BB104 | Zie datasheet 6.1.6 Power supply scheme (p.85) 100nF | | 0603 | Mouser | 14 | € 0,12 | 1,58 | Device:C | Capacitor_SMD:C_0603_1608Metric Capacitor_SMD:C_0603_1608Metric_Pad1.08x0.95mm_HandSolder
BMS - li-ion lader | C, SMD, alternatief | CC0805MKX5R7BB226 | 22 µF op +5V_SERVO nabij servo connector; buffert stroompieken servo 22µF | | 0805 | Mouser | 1 | € 0,46 | 0,464 | Device:C | Capacitor_SMD:C_0805_2012Metric Capacitor_SMD:C_0805_2012Metric_Pad1.18x1.45mm_HandSolder

https://www.mouser.be/ProductDetail/YAGEO/CC0603KRX5R6BB475?qs=BKNoF%2F0xMNun51HoEirUUw%3D%3D

https://www.mouser.be/ProductDetail/YAGEO/CC0603KRX7R7BB473?qs=AgBp2OyFlx86ySHhigeJEQ%3D%3D

https://www.mouser.be/ProductDetail/YAGEO/CC0603JRNPO9BN560?qs=AgBp2OyFlx%2BQkYQ4ORt7PA%3D%3D

https://www.mouser.be/ProductDetail/YAGEO/CC0603KRX7R6BB333?qs=57cj7OiSijk1glmlOVpoAg%3D%3D

https://www.mouser.be/ProductDetail/KEMET/C0603C104K8RACTU?qs=7q2aiX3GdlhV1RoC2Ruw8Q%3D%3D

https://www.mouser.be/ProductDetail/YAGEO/CC0805MKX5R6BB226?qs=Rvc7RZlme2YmhwhJ%2Fi8ogQ%3D%3D

Motor | C, THT, alternatief | UVR1C471MPD1TD | 470 µF is beter voor rail sag te voorkomen 470µF | 8 x 11,5 radial, lead spacing 3.5 mm Mouser | 1 | € 0,34 | 0,335 | Device:C | Capacitor_THT:CP_Radial_D8.0mm_P3.50mm https://www.mouser.be/ProductDetail/Nichicon/UVR1C471MPD1TD?qs=yAkwA2Qx9OeeX98r06%252B%252B4g%3D%3D
E-ink | Connector | 8-pin JST PH 2.0mm | Meegeleverde kabel wordt geknipt en gekrimpt naar JST-PH uitgang - | | 8-pin JST PH 2.0mm | - | 1 | | 0 | zie module | Connector_JST:JST_PH_B8B-PH-K_1x08_P2.00mm_Vertical
Motor | Connector | JST-PH 1x03 2mm | Kabel knippen en JST-PH op krimpen | - | JST-PH 1x03 2mm | - | 1 | € 0,00 | 0 | Zie motor | Connector_JST:JST_PH_B3B-PH-K_1x03_P2.00mm_Vertical
ST-link | Connector | Card edge connector | Programmer/debugger | - | Standard Card Edge Connectors Dual Row Inverted Card Edge 2x5pos w/ Kapton Mouser | 1 | € 1,21 | 1,21 | Zie ST-link | https://www.mouser.be/ProductDetail/KYOCERA-AVX/009159010603906?qs=ST9lo4GX8V1Mnrfaz2Mt1w%3D%3D https://www.mouser.be/ProductDetail/KYOCERA-AVX/009159010603906?qs=ST9lo4GX8V1Mnrfaz2Mt1w%3D%3D
GPS antenne | Connector, SMD | U.FL-R-SMT-1(10) | U.FL/IPEX SMD receptacle; soldeer GPS FPC antennekabel - | SMD | Mouser | 1 | € 1,42 | 1,42 | Connector_Coaxial:U.FL_Hirose_U.FL-R-SMT-1_Vertical https://www.mouser.be/ProductDetail/Hirose-Connector/U.FL-R-SMT-110?qs=kL1ClTr6oBoOdtqlGQpQrQ%3D%3D
BMS - USB-C | Connector, SMD, alternatief USB4105-GF-A-060 | | USB 2.0 Type-C 16-pin top-mount; voedingsingang van de lader - | | SMD | Mouser | 1 | € 0,80 | 0,8 | Connector_USB:USB_C_Receptacle_GCT_USB4105 Connector_USB:GCT_USB4105-GF-A_TopMnt_Horizontal (https://www.mouser.be/ProductDetail/GCT/USB4105-GF-A-060?qs=QNEnbhJQKvY2mocwNJzgfA%3D%3D) | Connector_USB:USB_C_Receptacle_GCT_USB4105-xx-A_16P_TopMnt_Horizontal
GPS/GNSS | D, SMD | BAT54C | Dual Anode Common Cathode | 30V 0,2A | SOT-23 | Mouser | 1 | € 0,10 | 0,103 | Diode:BAT54C | Package_TO_SOT_SMD:SOT-23 Package_TO_SOT_SMD:SOT-23_Handsoldering

https://www.mouser.be/ProductDetail/GCT/USB4105-GF-A-060?qs=QNEnbhJQKvY2mocwNJzgfA%3D%3D

https://www.mouser.be/ProductDetail/Diotec-Semiconductor/BAT54C?qs=OlC7AqGiEDmkBJ3TS7AJwQ%3D%3D

GPS/GNSS | D, SMD | BAT60AE6327HTSA1 | Schottky Diode | Vf 300 mV | SOD-323-2 | Mouser | 1 | € 0,62 | 0,619 | Device:D_Schottky | Diode_SMD:D_SOD-523 | https://www.mouser.be/ProductDetail/Infineon-Technologies/BAT60AE6327HTSA1?qs=OwbwYO03UsIW3Y2lCXbs8Q%3D%3D
Hall effect sensor | Hall sensor | DRV5032DULPGM | Unipolair: Z-pool, THT
Accelerometer | Header, Connector | 2x 4-pin header | | - | Twee 4-pin headers (2,54mm)- | 1 | 0 | - | -
2 dezelfde voor prototype, noord en zuid voor finaal ontwerp - | TO-92 | Mouser | 2 | € 0,30 | 0,602 | https://www.mouser.be/ProductDetail/Texas-Instruments/DRV5032DULPGM?qs=OlC7AqGiEDk9MwfBkgsRPw%3D%3D https://www.mouser.be/ProductDetail/Texas-Instruments/DRV5032DULPGM?qs=OlC7AqGiEDk9MwfBkgsRPw%3D%3D https://www.mouser.be/ProductDetail/Texas-Instruments/DRV5032DULPGM?qs=OlC7AqGiEDk9MwfBkgsRPw%3D%3D
EEC chip | IC | ATECC608B-SSHDA-T | - | | 8-SOIC | Digikey | 1 | € 0,79 | 0,79 | ATECC608B-SSHDA | Package_SO:SOIC-8_3.9x4.9mm_P1.27mm https://www.digikey.be/nl/products/detail/microchip-technology/ATECC608B-SSHDA-T/13415162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
BMS - li-ion lader | IC | BQ25630YBGR | I²C 1-cell 5A buck battery charger with USB Type-C® detection - | DSBGA (YBG) | Digikey | 1 | € 3,37 | 3,37 | https://www.mouser.be/ProductDetail/Texas-Instruments/BQ25630YBGR?qs=bpu3f%2FCR1jxmQ5vho%252BhFHQ%3D%3D https://www.mouser.be/ProductDetail/Texas-Instruments/BQ25630YBGR?qs=bpu3f%2FCR1jxmQ5vho%252BhFHQ%3D%3D https://www.digikey.nl/nl/products/detail/texas-instruments/BQ25630YBGR/28738812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
BMS - 3,3V buck-boost | IC | RT6158AWSC | 5µA ruststroom | DFN-10 | Mouser | 1 | € 1,66 | 1,66 | https://app.ultralibrarian.com/details/d01e2d83-aa6c-11ec-9033-0a34d6323d74/Richtek-Technology/RT6158HWSC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 (https://www.mouser.be/ProductDetail/Richtek/RT6158AWSC?qs=amGC7iS6iy8gZnSqdFBonA%3D%3D)
| | | | | | | | | | Aangepast | https://app.ultralibrarian.com/details/d01e2d83-aa6c-11ec-9033-0a34d6323d74/Richtek-Technology/RT6158HWSC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 (https://www.mouser.be/ProductDetail/Richtek/RT6158AWSC?qs=amGC7iS6iy8gZnSqdFBonA%3D%3D) RT6158AWSC:BGA25_RT6158H_RIT-M https://www.mouser.be/ProductDetail/Richtek/RT6158AWSC?qs=amGC7iS6iy8gZnSqdFBonA%3D%3D
BMS - 3,3V LDO regulator | IC | TCR3UG33A,LF | Met auto discharge | - | WCSP4F | Mouser | 1 | € 0,27 | 0,267 | https://www.snapeda.com/parts/TCR3UG33A%2CLF/Toshiba%20Semiconductor%20and%20Storage/view-part/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 https://www.snapeda.com/parts/TCR3UG33A%2CLF/Toshiba%20Semiconductor%20and%20Storage/view-part/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 https://www.mouser.be/ProductDetail/Toshiba/TCR3UG33ALF?qs=0lQeLiL1qyaZy60Q7HF0yg%3D%3D
BMS - 5V boost | IC | TPS61253F | 4,5A spoelstroom | - | DSBGA-9 | Digikey | 1 | € 1,00 | 1 | Zelf gemaakt | https://www.snapeda.com/parts/DRV2625YFFR/Texas%20Instruments/view-part/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 (https://www.digikey.be/nl/products/detail/texas-instruments/TPS61253FYFFR/29174815) ander component, zelfde package https://www.digikey.be/nl/products/detail/texas-instruments/TPS61253FYFFR/29174815
EEC chip | IC socket, THT | 1-2199298-2 | - | DIP-8 | Mouser | 1 | € 0,23 | 0,232 | Connector_Generic:Conn_01x08 Package_DIP:DIP-8_W7.62mm_Sockethttps://www.mouser.be/ProductDetail/TE-Connectivity/1-2199298-2?qs=fK8dlpkaUMtEKa4wabwOXQ%3D%3D
STM32 | IC, alternatief | STM32L431CCT6TR | Cortex-M4 256KB flash 64KB ram LQFP-48
| | | Min. 5 | - | LQFP48 (SOT313-2) | Digikey | 5 | € 4,82 | 24,1 | STM32L431CCTx | Package_QFP:LQFP-48_7x7mm_P0.5mm https://www.digikey.be/nl/products/detail/stmicroelectronics/STM32L431CCT6TR/8257907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

Onderdeel | Type | Component | Opmerking | Waarde | Vorm | Distributeur | # | € (1) | €€ | Symbool | Footprint | link
| | | | | | | | | | of Memory_EEPROM:24LC01B
FRAM chip | IC, SMD | FM24V01A-GTR | 128-Kbit (16Kbyte) | - | 8-SOIC | Digikey | 1 | € 3,82 | 3,82 | https://www.mouser.be/ProductDetail/Infineon-Technologies/FM24V01A-G?qs=3FnuM6ZipRKGr6yvOmSjPg%3D%3D (https://www.digikey.be/nl/products/detail/infineon-technologies/FM24V01A-GTR/5210532)

https://www.mouser.be/ProductDetail/Infineon-Technologies/FM24V01A-G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 https://www.digikey.be/nl/products/detail/infineon-technologies/FM24V01A-GTR/5210532

STM32 | Knop, THT | TS02-66-43-BK-160-LCR-D | - | SPST momentary tactile, 6×6 mm THT Mouser | 2 | € 0,09 | 0,172 | Switch:SW_Push | s | https://www.mouser.be/ProductDetail/Same-Sky/TS02-66-43-BK-160-LCR-D?qs=A6eO%252BMLsxmTzCMyhm6Ihkw%3D%3D
STM32 | L, SMD | BLM18KG601SN1D | 600 Ω @ 100 MHz; filtert VDDA-pin MCU af van +3V3-rail 600Ω@100MHz0603 | | | Digikey | 1 | € 0,09 | 0,09 | Device:Ferrite_Bead_Small | Inductor_SMD:L_0603_1608Metric Inductor_SMD:L_0603_1608Metric_Pad1.05x0.95mm_HandSolder
BMS - li-ion lader, BMS - 3,3V buck-boost, BMS - 5V boost L, SMD | | MAKK2520H1R0M | Datasheet: 1 µH typ, I_sat ≥ 2A | 1µH | Shielded power, 2,5x2,0mm Mouser | | 3 | € 0,16 | 0,489 | Device:L | Inductor_SMD:L_Taiyo-Yuden_NR-20xx (niet zeker) Inductor_SMD:L_Taiyo-Yuden_NR-20xx_HandSoldering (niet zeker) (https://www.mouser.be/ProductDetail/Taiyo-Yuden/MAKK2520H1R0M?qs=4JX4e57RtWwt5m13Ks17AQ%3D%3D)

https://www.digikey.be/en/products/detail/murata-electronics/BLM18KG601SN1D/1982766

https://www.mouser.be/ProductDetail/TAIYO-YUDEN/MAKK2520H1R0M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

LED | LED | BL-BEG204-7-E | Rood en groen, difuus, THT, common anode - | 5mm LED, radiaal, 3 pinnen Digikey | 1 | € 0,17 | 0,17 | LED_DUAL_KAK | LED_D5.0mm-3_Horizontal_O3.81mm_Z3.0mm https://www.digikey.be/nl/products/detail/american-bright-optoelectronics-corporation/BL-BEG204-7-E/22486902
GPS/GNSS | Module | Quectel LC76GPAMD | Zuiniger, goedkoper bij groot aantal | | half hole PCB breakout
(1.1mm) | Mouser | 1 | € 7,76 | 7,76 | https://www.mouser.be/ProductDetail/Quectel/LC76GPAMD?qs=vvQtp7zwQdMfDuCTmjRUww%3D%3D https://www.mouser.be/ProductDetail/Quectel/LC76GPAMD?qs=vvQtp7zwQdMfDuCTmjRUww%3D%3D https://www.mouser.be/ProductDetail/Quectel/LC76GPAMD?qs=vvQtp7zwQdMfDuCTmjRUww%3D%3D
Accelerometer | Module | LIS2DW12 module | module bevat I²C pullups weerstanden (10K) - | Module (2 4-pin headers) | Tinytronics | 1 | 0 | Zelf gemaakt | ! zelf maken | https://www.tinytronics.nl/en/sensors/acceleration-rotation/dfrobot-fermion-triple-axis-accelerometer-spi-i2c-lis2dw12
SD-kaart | Module | SD adapter module | Module met level shifter en SD-houder, werkt met SPI - | Module (8x2 pin header) | Tinytronics | 1 | € 2,50 | 2,5 | Zelf gmaakt | PinHeader_2x08_P2.54mm_Horizontal (https://www.tinytronics.nl/en/data-storage/modules/sd-card-adapter-module-3.3v-5v)
| | | | | | | | | | | PinHeader_2x08_P2.54mm_Vertical | https://www.tinytronics.nl/en/data-storage/modules/sd-card-adapter-module-3.3v-5v
E-ink | Module, Extern | Waveshare 1.54” module | - | 8-pin JST PH 2.0mm aansluiting Waveshare | 1 | 0 | Zelf gemaakt | zie connector | https://www.waveshare.com/1.54inch-e-Paper-Module.htm
ST-link | Module, Extern, alternatief STLINK-V3MINIE | Programmer/debugger | - | Standard Card Edge Connectors Dual Row Inverted Card Edge 2x5pos w/ Kapton Farnell | 1 | € 28,47 | 28,4713 | https://www.mouser.be/ProductDetail/KYOCERA-AVX/009159010603906?qs=ST9lo4GX8V1Mnrfaz2Mt1w%3D%3D Zie connector | https://be.farnell.com/stmicroelectronics/stlink-v3minie/debugger-prog-probe-32bit-arm/dp/3953430
LoRa | Module, SMD | WisDuo RAK11720 (MHF4 connector) LoRa + BLE, MHF4 connector | half hole PCB breakout (1mm) Digikey | 1 | € 12,76 | 12,76 | https://www.snapeda.com/parts/RAK11720/RAK/view-part/?welcome=home&ref=search&t=RAK11720&ab_test_case=b https://www.snapeda.com/parts/RAK11720/RAK/view-part/?welcome=home&ref=search&t=RAK11720&ab_test_case=b https://www.digikey.be/nl/products/detail/rakwireless-technology-limited/RAK11720-8-SM-I/26861631
Motor | Motor, Extern | TD-8120MG Digital Servo | waterproof - 20kg | - | Zie datasheet | Tinytronics | 1 | € 10,25 | 10,25 | Zelf gemaakt | Zie connector | https://www.tinytronics.nl/en/mechanics-and-actuators/motors/servomotors/td-8120mg-waterproof-digital-servo-20kg
BMS - li-ion lader | NTC, THT, alternatief 103AT-2 | THT, duurder, makkelijker tegen batterij te plaatsen 10K @25°C, β=3435 K Radial, 2,54mm spacing | Mouser | 1 | € 0,58 | 0,583 | Device:Thermistor_NTC | Capacitor_THT:C_Disc_D3.4mm_W2.1mm_P2.50mm https://www.mouser.be/ProductDetail/Semitec/103AT-2?qs=wgO0AD0o1vvcDzsKguD%252Bew%3D%3D
STM32 | R, SMD | RC0603FR-07220KL | VBAT_SENSE-deler: 220K/(220K+100K) × Vbat 220K | | 0603 | Mouser | 1 | € 0,09 | 0,086 | Device:R | Resistor_SMD:R_0603_1608Metric Resistor_SMD:R_0603_1608Metric_Pad0.98x0.95mm_HandSolder
STM32, BMS - 5V boost | R, SMD | RC0603FR-07100KL | Zie hierboven | 100K | 0603 | Mouser | 3 | € 0,09 | 0,258 | Device:R | Resistor_SMD:R_0603_1608Metric Resistor_SMD:R_0603_1608Metric_Pad0.98x0.95mm_HandSolder
GPS/GNSS | R, SMD | RC0603FR-131KL | Om supercap op te laden | 1K | 0603 | Mouser | 1 | € 0,09 | 0,086 | Device:R | Resistor_SMD:R_0603_1608Metric Resistor_SMD:R_0603_1608Metric_Pad0.98x0.95mm_HandSolder
GPS antenne | R, SMD | RC0402JR-070RL | zie hardware design p.40 | 0R | 0402 | Mouser | 1 | € 0,09 | 0,086 | Device:R | Resistor_SMD:R_0402_1005Metric Resistor_SMD:R_0402_1005Metric_Pad0.72x0.64mm_HandSolder
BMS - li-ion lader | R, SMD | RC0603FR-072K2L | | 2,2K | 0603 | Mouser | 1 | € 0,09 | 0,086 | Device:R | Resistor_SMD:R_0603_1608Metric Resistor_SMD:R_0603_1608Metric_Pad0.98x0.95mm_HandSolder
BMS - li-ion lader | R, SMD | RC0603FR-07100RL | | 100R | 0603 | Mouser | 1 | € 0,09 | 0,086 | Device:R | Resistor_SMD:R_0603_1608Metric Resistor_SMD:R_0603_1608Metric_Pad0.98x0.95mm_HandSolder
BMS - li-ion lader | R, SMD | RC0603FR-075K23L | JEITA-pullup met 103AT NTC (zie BQ25630 datasheet p.32) 5,23K | | 0603 | Mouser | 1 | € 0,09 | 0,086 | Device:R | Resistor_SMD:R_0603_1608Metric Resistor_SMD:R_0603_1608Metric_Pad0.98x0.95mm_HandSolder
BMS - 3,3V buck-boost | R, SMD | RC0603FR-071ML | | 1M | 0603 | Mouser | 1 | € 0,09 | 0,086 | Device:R | Resistor_SMD:R_0603_1608Metric Resistor_SMD:R_0603_1608Metric_Pad0.98x0.95mm_HandSolder
BMS - 3,3V buck-boost | R, SMD | RC0603FR-07294KL | 1% tolerantie aangeraden voor Vout-precisie 294K | | 0603 | Mouser | 1 | € 0,09 | 0,086 | Device:R | Resistor_SMD:R_0603_1608Metric Resistor_SMD:R_0603_1608Metric_Pad0.98x0.95mm_HandSolder
Motor | R, SMD | PT1206FR-7W0R1L | Stall-stroom servo ≈ 1A; bevestig waarde a.h.v. max stroom × ADC-range 0,1R / 500mW1206 | | | Mouser | 1 | € 0,32 | 0,318 | Device:R | Resistor_SMD:R_1206_3216Metric Resistor_SMD:R_1206_3216Metric_Pad1.30x1.75mm_HandSolder
Motor | R, SMD | RC0603FR-071KL | RC filter met 4,8kHz cutoff | 1K | 0603 | Mouser | 1 | € 0,09 | 0,086 | Device:R | Resistor_SMD:R_0603_1608Metric Resistor_SMD:R_0603_1608Metric_Pad0.98x0.95mm_HandSolder
LED | R, SMD | AF0603FR-07160RL | | 160R | 0603 | Mouser | 1 | € 0,09 | 0,086 | Device:R | Resistor_SMD:R_0603_1608Metric Resistor_SMD:R_0603_1608Metric_Pad0.98x0.95mm_HandSolder
LED | R, SMD | RC0603FR-07130RL | | 130R | 0603 | Mouser | 1 | € 0,10 | 0,095 | Device:R | Resistor_SMD:R_0603_1608Metric Resistor_SMD:R_0603_1608Metric_Pad0.98x0.95mm_HandSolder
STM32, LoRa, GPS/GNSS, SD-kaart, BMS - li-ion lader R, SMD, alternatief | | RC0603FR-1310KL | - | 10K | 0603 | Mouser | 9 | € 0,09 | 0,774 | Device:R | Resistor_SMD:R_0603_1608Metric Resistor_SMD:R_0603_1608Metric_Pad0.98x0.95mm_HandSolder
BMS - li-ion lader | R, SMD, alternatief | RC0603FR-1330K1L | Parallel met NTC voor JEITA-temperatuurschalen Berekend voor 103AT-2 (zie datasheet p.32) 30,1K | | 0603 | Mouser | 1 | € 0,09 | 0,086 | Device:R | Resistor_SMD:R_0603_1608Metric Resistor_SMD:R_0603_1608Metric_Pad0.98x0.95mm_HandSolder

https://www.mouser.be/ProductDetail/YAGEO/RC0603FR-07220KL?qs=nHyvTUT5UJ87BOKAmWeB9w%3D%3D

https://www.mouser.be/ProductDetail/YAGEO/RC0603FR-07100KL?qs=e1ok2LiJcmaihem8Va5%2Fsw%3D%3D

https://www.mouser.be/ProductDetail/YAGEO/RC0603FR-131KL?qs=EiqXWrxQq60RfsVJHVHHSQ%3D%3D

https://www.mouser.be/ProductDetail/YAGEO/RC0402JR-070RL?qs=5Bml4Cp94iv7ykKkzPrwpQ%3D%3D

https://www.mouser.be/ProductDetail/YAGEO/RC0603FR-072K2L?qs=diQw95jMAeOQmNpe2MM%252BPw%3D%3D

https://www.mouser.be/ProductDetail/YAGEO/RC0603FR-07100RL?qs=NEN%2FsE%2FLsvPIwIWKCOS4%2FA%3D%3D

https://www.mouser.be/ProductDetail/YAGEO/RC0603FR-075K23L?qs=2cAdsCoAWRHkLnBdsnvrqA%3D%3D

https://www.mouser.be/ProductDetail/YAGEO/RC0603FR-071ML?qs=VU8sRB4EgwDPceeQKB324w%3D%3D

https://www.mouser.be/ProductDetail/YAGEO/RC0603FR-07294KL?qs=lQgrAEddei5avgj2EIqxJw%3D%3D

https://www.mouser.be/ProductDetail/YAGEO/PT1206FR-7W0R1L?qs=uke%2FucjsF5Ga5AppxlD%2FUQ%3D%3D

https://www.mouser.be/ProductDetail/YAGEO/RC0603FR-071KL?qs=VU8sRB4EgwApHsk4rF%2F3zg%3D%3D

https://www.mouser.be/ProductDetail/YAGEO/AF0603FR-07160RL?qs=fTsMJN6MUUtqYwsnSjRCng%3D%3D

https://www.mouser.be/ProductDetail/YAGEO/RC0603FR-07130RL?qs=uM1JSSdPjOCVyxRqTJq6LQ%3D%3D

https://www.mouser.be/ProductDetail/YAGEO/RC0603FR-1310KL?qs=EiqXWrxQq61KPbFOr8F%252BoA%3D%3D

https://www.mouser.be/ProductDetail/YAGEO/RC0603FR-1330K1L?qs=IuGqVx9wL0IxkCXjOxk7Mw%3D%3D

GPS/GNSS | TVS, SMD | SMF05CT1G | 5 TVS dioden in één, 2 gebruikt | - | SC-88-6 (SOT-363-6) | Mouser | 1 | € 0,38 | 0,378 | https://www.snapeda.com/parts/SMF05CT1G/onsemi/view-part/?ref=search&t=SMF05CT1G&ab_test_case=b https://www.snapeda.com/parts/SMF05CT1G/onsemi/view-part/?ref=search&t=SMF05CT1G&ab_test_case=b https://www.mouser.be/ProductDetail/onsemi/SMF05CT1G?qs=xZq1yRCsb1c8sZHBbx4IBw%3D%3D
GPS antenne | TVS, SMD | ESD9B5.0ST5G | Lage junction-capacitance (<0,6pF) — zie hardware design p.40 SOD-923 | Digikey | 1 | € 0,19 | 0,19 | Device:D_TVS | Diode_SMD:D_SOD-923 | https://www.digikey.be/en/products/detail/onsemi/ESD9B5-0ST5G/1646449
BMS - USB-C | TVS, SMD | USBLC6-2SC6 | Plaatsen direct naast USB-C connector; beschermt D+/D− lijnen - | SOT-23-6 | Digikey | 1 | € 0,16 | 0,16 | Device:D_TVS | Package_TO_SOT_SMD:SOT-23-6
Totaal | | | | | | 0 | € 46.261,51 | 120,4573

Package_TO_SOT_SMD:SOT-23-6_Handsoldering www.digikey.be/nl/products/detail/stmicroelectronics/USBLC6-2SC6/1040559

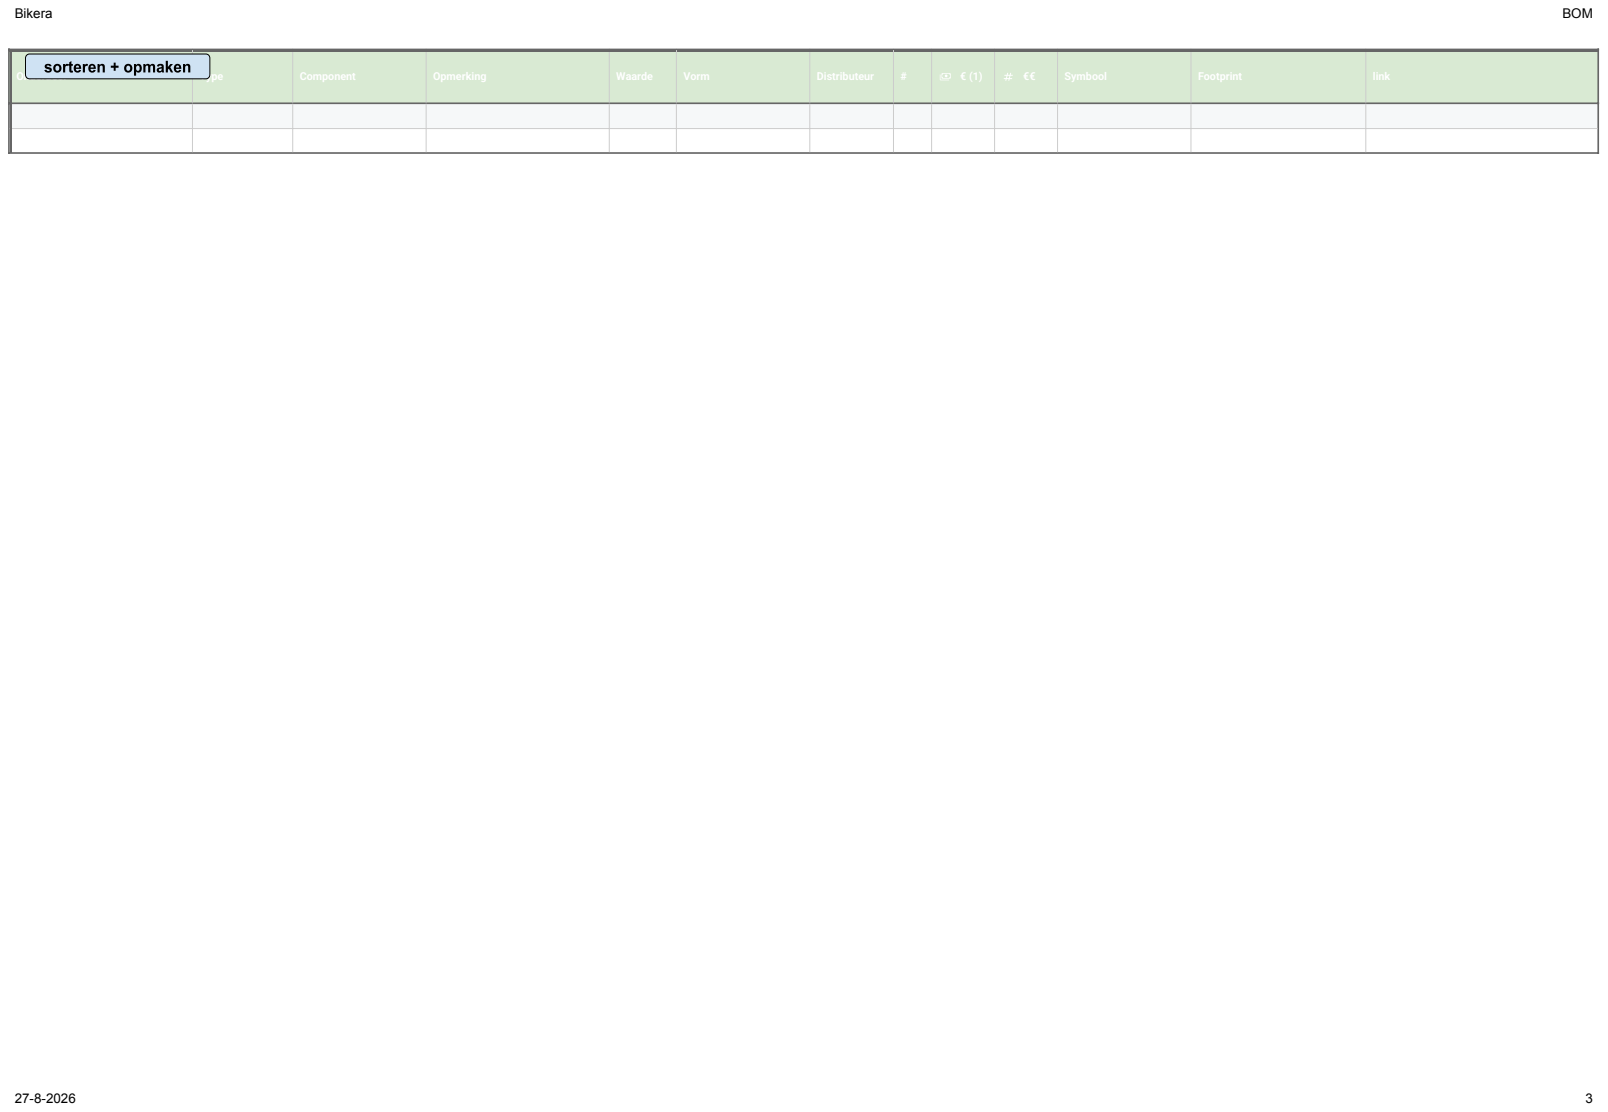
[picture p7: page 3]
Onderdeel; Type; Component; Opmerking; Waarde; Vorm; Distributeur; Symbool; Footprint; link

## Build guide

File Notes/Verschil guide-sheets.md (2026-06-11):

## Verschillen tussen materiaallijst en google sheets
22/05/26
### Componentverschillen

| Onderdeel | Sheet | Gids | Conclusie |
| --- | --- | --- | --- |
| 3,3V buck-boost IC | ==RT6158AWSC (DFN-10)== | RT6150B (WDFN-10L) | **Sheet behouden** — RT6158AWSC is de gekozen component; de gids-notities zijn verouderd op dit punt. FB-weerstanden in de sheet (1 MΩ / 294 kΩ) zijn correct voor RT6158AWSC (VFB = 0,765 V). |
| GPS VCC TVS | ESD9B5.0ST5G (SOD-923) | ==SMBJ5.0CA (SMB)== | **Gids gevolgd** — ESD9B is alleen geschikt voor signaalniveau ESD; SMBJ5.0CA (600 W piek) is correcte keuze voor een vermogensrail. |
| GPS V_BCKP TVS | ESD9B5.0ST5G (SOD-923) | ==SMBJ5.0CA (SMB)== | **Gids gevolgd** — zelfde redenering als VCC TVS. |
| GPS antenne TVS | ==ESD7C5.0ST5G (<0,6 pF)== | SMF05C / PESD5V0X1BSF | **Sheet behouden** — beide zijn lage-capacitantie RF TVS (<2 pF); ESD7C5.0ST5G voldoet. |
| LED stroomweerstanden | ==rood 150 Ω / groen 130 Ω (~8,5 mA)== | 470 Ω / 330 Ω (normaal) of 180 Ω / 150 Ω (buiten) | **Sheet behouden** — iets helderder dan de buitenwaarden van de gids, ruim binnen de 20 mA limiet. |
| Servo stroom-shunt | ==0,1 Ω / 1 W / 2010== | 0,05 Ω / 2 W / 2512 | **Sheet behouden** — 0,1 Ω geeft 2× betere ADC-resolutie (200 mV bij 2 A stall); 1 W-rating is voldoende. |

### Ontbrekende onderdelen (niet in sheet, wel vereist door gids)

Onderdelen die geen rij hadden in Componenten:
- USB-C receptacle (USB4105-GF-A-060)
- USB ESD bescherming (USBLC6-2SC6)
- CC1 + CC2 pull-down weerstanden (2× 5,1 kΩ) — vereist voor USB-C brondetectie door BQ25630
- GPS V_BCKP backup supercap (CPH3225A-LF, 0,1 F)
- GPS U.FL RF receptacle (U.FL-R-SMT-1(10)) — bestaande placeholder-rij bijgewerkt
- Ferrite bead VDDA MCU (FB1, 600 Ω @ 100 MHz)
- Batterijconnector (S2B-PH-K-S(LF)(SN), JST PH 2.0 mm)
- Batterijspanningsdeler (220 kΩ + 100 kΩ + 10 nF, MCU PA0)
- Servo rail bulk condensatoren (22 µF 0805 + 100 nF 0603)

CP2102N UART-naar-USB bridge: **niet toegevoegd** — bewust weggelaten om veiligheidsredenen; externe ST-link wordt gebruikt.

## Wijzigingen doorgevoerd in de sheet
**In-place bijgewerkt:**
- Rij 29 (GPS VCC TVS): ESD9B5.0ST5G → SMBJ5.0CA, pakket SOD-923 → SMB
- Rij 33 (GPS V_BCKP TVS): ESD9B5.0ST5G → SMBJ5.0CA, pakket SOD-923 → SMB
- Rij 35 (GPS antenne connector): ingevuld als U.FL-R-SMT-1(10), type/pakket/footprint bijgewerkt

**Nieuw toegevoegd (rijen 88–98, daarna handmatig op juiste plek gezet):**
- USB-C: receptacle, USBLC6-2SC6, CC-pulldowns
- GPS/GNSS: supercap 0,1 F
- STM32: ferrite bead FB1, batterijspanningsdeler (220 kΩ + 100 kΩ + 10 nF)
- Batterij: JST PH 2.0 mm connector
- Motor: servo rail bulk caps (22 µF + 100 nF)

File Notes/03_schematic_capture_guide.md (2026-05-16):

# Bikera — Schematic Capture & Readability Guide

**Authoritative source for all values and pin assignments:** `BIKERA_SCHEMATIC_PROMPT.md`  
**Authoritative source for component selection:** `Bikera.xlsx` → Keuze prototype = TRUE (BOM wins over architecture diagram where they disagree)  
**KiCAD version:** 9 (schematic format 20231120)

---

## Layout rules — apply to every sheet

Four rules that make a schematic readable without knowing the design:

1. **Power flows top → bottom.** Power symbols (+3V3, +5V_SERVO, +SYS) sit above the IC. GND symbols sit below. A reader can scan vertically and immediately see the supply chain.
2. **Signal flows left → right.** Inputs and incoming labels enter from the left edge. Outputs and outgoing labels exit from the right edge. Cross-sheet nets use net labels, not long wire runs.
3. **No diagonal wires.** Every wire segment must be horizontal or vertical. A diagonal wire in KiCAD schematic mode usually means two endpoints that don't actually share a net — it looks connected but isn't.
4. **Decoupling caps hang vertically from the supply pin.** Place the cap immediately below the VCC/supply pin (or immediately to one side if space is tight). Both orientations work; pick one and keep it consistent. Connect pin 1 (top) to the supply net, pin 2 (bottom) to GND.

---

## Net names used across sheets

These labels must be spelled identically on every sheet — KiCAD treats them as global connections only within a hierarchical sheet set, so a typo creates a silent open circuit.

| Net | Source sheet | Consumer sheets |
|---|---|---|
| `+VBAT` | 01_power | 02_mcu (VBAT_SENSE divider) |
| `+SYS` | 01_power | 01_power (internal: feeds U2, U3, U4) |
| `+3V3` | 01_power | 02, 03, 05, 06, 07, 08, 09 |
| `+3V3_GPS` | 01_power (via U3) | 04_gps |
| `+5V_SERVO` | 01_power (via U4) | 07_actuator |
| `GND` | everywhere | everywhere |
| `I2C_SDA` | 02_mcu | 01_power (BQ25630), 05_storage (FRAM), 06_sensors (LIS2DW12), 08_secure (ATECC608B) |
| `I2C_SCL` | 02_mcu | same as SDA |
| `SPI1_SCK` | 02_mcu | 05_storage (SD + ePaper) |
| `SPI1_MISO` | 02_mcu | 05_storage (SD) |
| `SPI1_MOSI` | 02_mcu | 05_storage (SD + ePaper) |
| `USB_DP` | 01_power (J1) | 09_bridge |
| `USB_DN` | 01_power (J1) | 09_bridge |
| `USB_VBUS` | 01_power (J1) | 09_bridge (sense divider only) |
| `BRIDGE_TX` | 09_bridge | 02_mcu (LPUART1 RX, PC1) |
| `BRIDGE_RX` | 09_bridge | 02_mcu (LPUART1 TX, PC0) |
| `DEBUG_TX` | 02_mcu | 02_mcu (to J11 BTB pin 10) |
| `DEBUG_RX` | 02_mcu | 02_mcu (from J11 BTB pin 9) |
| `LORA_TX` | 02_mcu | 03_radio |
| `LORA_RX` | 02_mcu | 03_radio |
| `LORA_RESET` | 02_mcu | 03_radio |
| `LORA_BOOT` | 02_mcu | 03_radio |
| `GPS_TX` | 02_mcu | 04_gps |
| `GPS_RX` | 02_mcu | 04_gps |
| `GPS_RESET` | 02_mcu | 04_gps |
| `GPS_EN` | 02_mcu | 01_power (TCR3UG33A CONTROL) |
| `GPS_PPS` | 04_gps | 02_mcu |
| `CHRG_CE` | 02_mcu | 01_power |
| `CHRG_PG` | 01_power | 02_mcu |
| `CHRG_INT` | 01_power | 02_mcu |
| `EN_5V_SERVO` | 02_mcu | 01_power (TPS61253F EN) |
| `VBAT_SENSE` | 01_power | 02_mcu |
| `SERVO_PWM` | 02_mcu | 07_actuator |
| `SERVO_ISENSE` | 07_actuator | 02_mcu |
| `LED_RED` | 02_mcu | 07_actuator |
| `LED_GREEN` | 02_mcu | 07_actuator |
| `HALL_BEUGEL` | 06_sensors | 02_mcu |
| `HALL_PIN` | 06_sensors | 02_mcu |
| `ACCEL_INT1` | 06_sensors | 02_mcu |
| `ACCEL_INT2` | 06_sensors | 02_mcu |
| `SD_CS` | 02_mcu | 05_storage |
| `EPAPER_CS` | 02_mcu | 05_storage |
| `EPAPER_DC` | 02_mcu | 05_storage |
| `EPAPER_RST` | 02_mcu | 05_storage |
| `EPAPER_BUSY` | 05_storage | 02_mcu |

---

## Sheet 01 — Power (`01_power.kicad_sch`)

**What this sheet does:** converts USB-C or battery voltage into the four regulated rails the rest of the board uses: `+3V3` (always on), `+3V3_GPS` (GPS-gated), `+5V_SERVO` (servo-gated), and `+SYS` (intermediate charger output that feeds the three regulators).

### Circuit topology

```
                    ┌──────────────────────────────────────────────────────────┐
USB-C J1            │  01_power.kicad_sch                                      │
VBUS ─────┐         │                                                           │
D+   ─┐   │         │  ┌─────────────┐    +SYS ──────────────────────────────┐ │
D-   ─┤   │         │  │ BQ25630 U1  │                                        │ │
CC1  ─┤   └─────────┼─►│ VBUS        │    ┌───────────────────────────────┐   │ │
CC2  ─┤   ┌─────────┼─►│ BAT    SYS ─┼───►│ RT6150B U2                    │   │ │
       │   │         │  │ SW──L1      │    │ VIN  VOUT ──► +3V3 (global)   │   │ │
       │   │ J2      │  │ BTST──47nF  │    └───────────────────────────────┘   │ │
       │   │ battery │  │ REGN──4.7µF │                                        │ │
       │   └─────────┼─►│ CC1         │    ┌───────────────────────────────┐   │ │
       │             │  │ CC2         │    │ TCR3UG33A U3                  │   │ │
       │             │  │ I2C──────── ┼────┤ VIN  VOUT ──► +3V3_GPS        │   │ │
       │             │  │ PG──────────┼───►│      CTRL ◄── GPS_EN          │   │ │
       │             │  │ INT─────────┼───►│                               │   │ │
       │             │  │ CE ─────────┼────┤ (GPS-gated LDO)               │   │ │
       │             │  │ BATP──100Ω─►│BAT+└───────────────────────────────┘   │ │
       │             │  │ D+ NC       │                                        │ │
       │             │  │ D- NC       │    ┌───────────────────────────────┐   │ │
       │             │  │ QON NC      │    │ TPS61253F U4                  │   │ │
       │             │  └─────────────┘    │ VIN──L3──SW    VOUT ──► +5V_SERVO │ │
       │             │                     │ EN ◄── EN_5V_SERVO             │   │ │
       └─────────────┼─► USB_DP (label to sheet 09)                        │   │ │
                     │  └─► through USBLC6 D1 first                        │   │ │
                     │  USB_DN (label to sheet 09)                         │   │ │
                     │  USB_VBUS (label to sheet 09)                       │   │ │
                     └──────────────────────────────────────────────────────┘   │
                                                                                │
                     +SYS feeds all three regulators above ─────────────────────┘
```

### Placement on the A4 page

Place components in three horizontal bands:

```
LEFT (x=20–80)          CENTER (x=80–160)         RIGHT (x=160–260)
─────────────────────────────────────────────────────────────────────
[J1 USB-C]              [U1 BQ25630]              [U2 RT6150B]
[D1 USBLC6]             [L1 inductor]             [L2 inductor]
                         [J2 battery]             [U3 TCR3UG33A]
                                                  [U4 TPS61253F]
                                                  [L3 inductor]
```

Power rails run as horizontal bus lines:
- `+SYS` as a horizontal wire at y≈60 connecting U1 SYS → U2 VIN, U3 VIN, U4 VIN
- `+3V3` as a power symbol on U2 VOUT (no long wire — let power symbols do the work)
- `+3V3_GPS` as a power symbol on U3 VOUT
- `+5V_SERVO` as a power symbol on U4 VOUT

### J1 — USB-C receptacle (GCT USB4105-GF-A-060)

```
J1 pin      → connects to
─────────────────────────────────────────────────────────
VBUS        → wire to D1 (USBLC6) VBUS in, then to U1 VBUS pins (A1, B1)
GND (×2)    → GND power symbol
CC1         → 5.1 kΩ resistor to GND, and wire to U1 CC1 (F4)
CC2         → 5.1 kΩ resistor to GND, and wire to U1 CC2 (F5)
D+          → D1 (USBLC6) D+ in → net label USB_DP (exits to sheet 09)
D-          → D1 (USBLC6) D- in → net label USB_DN (exits to sheet 09)
Shell       → GND
```

**CC pulldowns:** draw two 5.1 kΩ resistors from CC1 and CC2 to GND. Without these the BQ25630 cannot detect the USB-C source and will only pull 100 mA.

### D1 — USBLC6-2SC6 (ESD protection, SOT-23-6)

Place immediately right of J1. The USBLC6 sits between J1 and everything downstream — it must be first in the chain.

```
D1 pin      → connects to
─────────────────────────────────────────────────────────
VBUS        → VBUS from J1 (input, also feeds U1)
D+ (in)     → D+ from J1
D- (in)     → D- from J1
D+ (out)    → net label USB_DP
D- (out)    → net label USB_DN
GND         → GND
```

### U1 — BQ25630YBGR (Li-ion charger)

This IC has 30 pins in a 6×5 BGA. Group them by function in the symbol's connections:

```
U1 pin(s)   → connects to
─────────────────────────────────────────────────────────
VBUS (A1,B1)     → from D1 VBUS out / J1 VBUS. Add 1 µF ceramic to GND close to these pins.
PMID (A2,B2)     → 10 µF + 100 nF ceramic to GND (these two caps in parallel)
SW (A3,B3,C3)    → one side of L1 (1 µH power inductor, ≥5 A saturation)
PGND (A4,B4,C4)  → GND
REGN (A5)        → 4.7 µF ceramic (10 V rated) to GND
BTST (B5)        → 47 nF ceramic to the SW node (connect across BTST and the L1 junction)
CE (C1)          → net label CHRG_CE (comes from MCU PC3). Drive low = charge enabled.
PG (C2)          → net label CHRG_PG (goes to MCU PA11). Pull-up: 2.2 kΩ to +3V3.
SW_3 (C3)        → ties to other SW pins (same node as L1)
PGND_3 (C4)      → GND
INT (C5)         → net label CHRG_INT (goes to MCU PA12). Pull-up: 10 kΩ to +3V3.
SYS (D1,D2,D3)  → net +SYS. Add 20 µF ceramic to GND (use 22 µF E12 value, 0805).
QON (D4)         → NC (no-connect flag)
SCL (D5)         → net label I2C_SCL. Pull-up: 10 kΩ to +3V3 (place the pull-up ONLY HERE).
BAT (E1,E2,E3)  → J2 battery pin 1 (+). Add 10 µF ceramic to GND close to BAT pins.
TS (E4)          → 103AT-2 thermistor (or 10 kΩ to REGN + 10 kΩ to GND fixed divider for bench bring-up)
SDA (E5)         → net label I2C_SDA. Pull-up: 10 kΩ to +3V3 (place the pull-up ONLY HERE).
BATP (F1)        → 100 Ω resistor in series to J2 battery pin 1 (Kelvin sense — separate from the BAT power path)
D+ (F2)          → NC
D- (F3)          → NC
CC1 (F4)         → J1 CC1 and 5.1 kΩ to GND
CC2 (F5)         → J1 CC2 and 5.1 kΩ to GND
```

**Inductor L1:** place between the SW pins junction and a node that connects back to VBUS/PMID. One terminal → SW pins (A3,B3,C3 tied), other terminal → PMID/VBUS node. Keep this loop physically small on the PCB.

**I²C pull-ups:** the 10 kΩ pull-ups on SDA and SCL go here on this sheet only. Do NOT add another set on any other sheet — duplicate pull-ups halve the effective resistance and cause glitches.

### J2 — Battery connector (JST PH 2.0 mm, 2-pin)

```
J2 pin 1 (BAT+) → U1 BAT pins (E1,E2,E3) and U1 BATP via 100 Ω
J2 pin 2 (GND)  → GND
```

### U2 — RT6150B (3.3 V buck-boost)

```
U2 pin      → connects to
─────────────────────────────────────────────────────────
VIN (5)     → +SYS net. Add 10 µF ceramic to GND close to this pin.
VOUT (1)    → +3V3 power symbol. Add 20 µF ceramic (22 µF E12) to GND.
LX1 (4)     → one end of L2 (2.2 µH, ≥1.6 A saturation)
LX2 (2)     → other end of L2
EN (6)      → +SYS (tie high for always-on +3V3 rail)
PS (7)      → GND (PSM mode — efficient at light loads. Do NOT tie high.)
VINA (8)    → VIN pin (5) directly — no RC filter, just a short wire
FB (10)     → midpoint of R1 (487 kΩ, top) / R2 (86.6 kΩ, bottom) divider.
              R1 from FB to VOUT. R2 from FB to GND. This sets Vout = 3.3 V.
              Optional: 20 pF cap in parallel with R1 for better transient response.
GND (3,9)   → GND
EPAD (11)   → GND (thermal pad — must be soldered and via'd to ground plane)
```

### U3 — TCR3UG33A,LF (3.3 V LDO, GPS rail)

This LDO is deliberately separate from +3V3 so the MCU can gate GPS power off during sleep.

```
U3 pin      → connects to
─────────────────────────────────────────────────────────
VIN (A1)    → +SYS. Add 1 µF ceramic to GND.
VOUT (B2)   → +3V3_GPS power symbol. Add 1 µF ceramic to GND.
CONTROL (A2)→ net label GPS_EN (from MCU PB12). High = LDO on. Internal pull-down so GPS defaults OFF.
GND (B1)    → GND
```

### U4 — TPS61253F (5 V boost, servo rail)

The servo rail is gated — only live when EN_5V_SERVO is driven high by the MCU.

```
U4 pin      → connects to
─────────────────────────────────────────────────────────
VIN (A3)    → +SYS. Add 10 µF ceramic to GND close to this pin.
VOUT (A1,A2)→ +5V_SERVO power symbol. Add 22 µF ceramic to GND (0805, X7R).
SW (B1,B2)  → one end of L3 (1 µH, ≥4 A saturation). Other end of L3 → VIN.
EN (B3)     → net label EN_5V_SERVO (from MCU PA4). 
              Also add 100 kΩ from EN to GND (explicit low-side pull keeps rail
              off during MCU reset, redundant with internal pull-down but cheap).
MODE (C3)   → 100 kΩ resistor to VOUT (+5V_SERVO). This forces PWM mode.
              Do NOT leave MODE floating (that is ultrasonic mode, not PWM).
GND (C1,C2) → GND
```

### Battery sense divider

Draw this in the bottom-left of the power sheet, near J2:

```
+VBAT ── 220 kΩ ── VBAT_SENSE ── 100 kΩ ── GND
                        │
                     10 nF to GND (anti-aliasing)
                        │
                  net label VBAT_SENSE (to MCU PA0, ADC1_IN5)
```

---

## Sheet 02 — MCU (`02_mcu.kicad_sch`)

**What this sheet does:** houses the STM32L431CCT6TR with all decoupling, the SWD debug connector (J11), and the two tactile buttons (BOOT, RESET). All MCU-to-peripheral signals exit as net labels.

### Placement on the A4 page

```
TOP-LEFT              CENTER                    RIGHT
──────────────────────────────────────────────────────────
[SW1 BOOT button]     [STM32L431 U7]            [J11 BTB SWD]
[SW2 RESET button]    (center of sheet)
                      [decoupling caps
                       arranged around IC]
```

The MCU has 48 pins. In KiCAD the LQFP-48 symbol has pins on all four sides. Net labels exit from each side toward the sheet edge — left-side pins get left-pointing labels, right-side pins get right-pointing labels. This prevents wires crossing over the IC body.

### U7 — STM32L431CCT6TR

All connections below use net labels, not wires running across the page.

**Power pins (place power symbols directly on pin, no label):**

```
Pin 1  VBAT  → +3V3 power symbol
Pin 6  BOOT0 → see button section below (not a power pin, but listed here for reference)
Pin 7  NRST  → see button section below
Pin 8  VSSA  → GND power symbol
Pin 9  VDDA  → filtered +3V3 via ferrite bead FB1 (600 Ω @ 100 MHz)
               Then: 1 µF X7R to VSSA (bulk), 100 nF X7R to VSSA (HF)
Pin 36 VSS   → GND
Pin 37 VDD   → +3V3. Decoupling: 100 nF X7R immediately to GND.
Pin 46 VSS   → GND
Pin 47 VDD   → +3V3. Decoupling: 100 nF X7R immediately to GND.
Pin 48 VSS   → GND
```

**Ferrite bead FB1 for VDDA:**
```
+3V3 ── [FB1 600Ω@100MHz, 0603] ── VDDA (pin 9)
                                         │
                                     100 nF to VSSA (pin 8)
                                         │
                                       1 µF to VSSA
```
Place FB1 and both VDDA caps physically close together in your PCB layout, closest to pin 9.

**Signal pins — complete assignment:**

| MCU pin | Net label | Direction | Goes to |
|---|---|---|---|
| PA0 (10) | `VBAT_SENSE` | in | Battery divider on sheet 01 |
| PA1 (11) | `SERVO_PWM` | out | Sheet 07 servo J9 |
| PA2 (12) | `LORA_RX` | out | Sheet 03 RAK11720 UART_RX (PA2=USART2_TX, MCU transmits to module's RX line) |
| PA3 (13) | `LORA_TX` | in | Sheet 03 RAK11720 UART_TX (PA3=USART2_RX, MCU receives from module's TX line) |
| PA4 (14) | `EN_5V_SERVO` | out | Sheet 01 TPS61253F EN |
| PA5 (15) | `SPI1_SCK` | out | Sheet 05 SD + ePaper |
| PA6 (16) | `SPI1_MISO` | in | Sheet 05 SD |
| PA7 (17) | `SPI1_MOSI` | out | Sheet 05 SD + ePaper |
| PA8 (18) | `LED_GREEN` | out | Sheet 07 LED green cathode resistor |
| PA9 (19) | `DEBUG_TX` | out | J11 BTB pin 10 (ST-Link receives) |
| PA10 (20) | `DEBUG_RX` | in | J11 BTB pin 9 (ST-Link transmits) |
| PA11 (21) | `CHRG_PG` | in | Sheet 01 BQ25630 PG |
| PA12 (22) | `CHRG_INT` | in | Sheet 01 BQ25630 INT |
| PA13 (23) | `SWDIO` | bidir | J11 BTB pin 3 |
| PA14 (24) | `SWCLK` | in | J11 BTB pin 5 |
| PA15 (25) | `SD_CS` | out | Sheet 05 SD chip select |
| PB3 (26) | `SWO` | out | J11 BTB pin 7 |
| PB4 (27) | `HALL_BEUGEL` | in | Sheet 06 DRV5032 #1 OUT2 |
| PB5 (28) | `HALL_PIN` | in | Sheet 06 DRV5032 #2 OUT2 |
| PB6 (29) | `I2C_SCL` | out | I²C bus (pull-up on sheet 01) |
| PB7 (30) | `I2C_SDA` | bidir | I²C bus (pull-up on sheet 01) |
| PB8 (32) | `GPS_RESET` | out | Sheet 04 LC76GPAMD RESET_N |
| PB9 (33) | `GPS_PPS` | in | Sheet 04 LC76GPAMD 1PPS |
| PB10 (34) | `GPS_TX` | out | Sheet 04 LC76GPAMD RXD |
| PB11 (35) | `GPS_RX` | in | Sheet 04 LC76GPAMD TXD |
| PB12 (38) | `GPS_EN` | out | Sheet 01 TCR3UG33A CONTROL |
| PB13 (39) | `ACCEL_INT1` | in | Sheet 06 LIS2DW12 INT1 |
| PB14 (40) | `ACCEL_INT2` | in | Sheet 06 LIS2DW12 INT2 |
| PB15 (41) | `LORA_BOOT` | out | Sheet 03 RAK11720 BOOT |
| PC0 (42) | `BRIDGE_RX` | out | Sheet 09 CP2102N RXD |
| PC1 (43) | `BRIDGE_TX` | in | Sheet 09 CP2102N TXD |
| PC2 (44) | `SERVO_ISENSE` | in | Sheet 07 Rsense tap |
| PC3 (45) | `CHRG_CE` | out | Sheet 01 BQ25630 CE |
| PC13 (2) | `EPAPER_CS` | out | Sheet 05 ePaper CS |
| PC14 (3) | `EPAPER_DC` | out | Sheet 05 ePaper DC |
| PC15 (4) | `EPAPER_RST` | out | Sheet 05 ePaper RST |
| PH0 (5) | `EPAPER_BUSY` | in | Sheet 05 ePaper BUSY |
| PH1 (6) | NC | — | No-connect flag |
| BOOT0 (31) | — | — | See SW1 below |

### SW1 — BOOT button

```
+3V3
  │
[SW1 momentary NO]
  │
BOOT0 (MCU pin 31) ── 10 kΩ ── GND
```
This 10 kΩ pull-down keeps BOOT0 low (normal boot) at all times. Pressing SW1 momentarily pulls BOOT0 high. Do this during a RESET to enter STM32 system bootloader — useful for flashing via UART without the ST-Link.

No additional capacitor needed on BOOT0 — just the 10 kΩ pull-down and the button.

### SW2 — RESET button

```
NRST (MCU pin 7) ── 100 nF ── GND
       │
     [SW2 momentary NO]
       │
      GND
```
The STM32L431 NRST pin has an internal pull-up (~40 kΩ). The only external component needed is a 100 nF cap for noise immunity. Pressing SW2 momentarily shorts NRST to GND, resetting the MCU. No external pull-up resistor needed (adding one wastes current and slows reset release).

### J11 — KYOCERA-AVX 009159010603906 (ST-Link BTB)

Place in the top-right of the sheet. Wires from J11 to MCU are short because the SWD pins (PA13, PA14, PB3) are in one corner of the LQFP-48.

> **Note:** The pinout below is the assignment used in the generated schematic (source: BIKERA_SCHEMATIC_PROMPT.md). The 009159010603906 pin numbers (1–10) do **not** map 1-to-1 to the UM2910 BTB pad numbers — verify physical alignment against the STLINK-V3MINIE hardware before PCB layout.

```
J11 pin → connects to
─────────────────────────────────────────────────────────
1  VTGT   → +3V3 (tells ST-Link what voltage the target uses)
2  GND    → GND
3  SWDIO  → net label SWDIO (MCU PA13)
4  GND    → GND
5  SWCLK  → net label SWCLK (MCU PA14)
6  NRST   → NRST (MCU pin 7, same node as SW2 and 100nF cap)
7  SWO    → net label SWO (MCU PB3)
8  GND    → GND
9  RX     → net label DEBUG_RX (MCU PA10 receives from ST-Link)
10 TX     → net label DEBUG_TX (MCU PA9 transmits to ST-Link)
```

---

## Sheet 03 — Radio (`03_radio.kicad_sch`)

**What this sheet does:** connects the RAK11720 LoRa+BLE module. No RF traces on the PCB — the MHF4 variant routes RF internally to its two MHF4 connectors. This sheet is therefore only UART, power, and control signals.

### Placement on the A4 page

```
LEFT                    CENTER                     RIGHT
─────────────────────────────────────────────────────────
Net labels              [RAK11720 U5]              Net labels
LORA_RX ──────────────► UART_RX                   LORA_ANT ──► (MHF4 J3)
LORA_TX ◄────────────── UART_TX                   BLE_ANT  ──► (MHF4 J4)
LORA_RESET ───────────► NRESET
LORA_BOOT ────────────► BOOT0

+3V3 ─────────────────► VBAT (+ decoupling cluster top-right)
                         GND
```

### U5 — RAK11720

```
U5 function pin  → connects to
─────────────────────────────────────────────────────────
VBAT             → +3V3. Decoupling: 10 µF + 1 µF + 100 nF in parallel close to pin.
VDD_REF (VIO)    → +3V3. Extra 100 nF nearby.
GND (all)        → GND
UART_TX (module out) → net label LORA_TX (to MCU PA3, USART2_RX — MCU receives)
UART_RX (module in)  → net label LORA_RX (from MCU PA2, USART2_TX — MCU transmits)
NRESET           → net label LORA_RESET (from MCU PB1). 10 kΩ pull-up to +3V3.
BOOT0            → net label LORA_BOOT (from MCU PB15). 10 kΩ pull-down to GND.
LORA_ANT         → net label LORA_ANT (to MHF4 connector J3)
BLE_ANT          → net label BLE_ANT (to MHF4 connector J4)
all other GPIO   → NC flags
```

**NRESET pull-up:** 10 kΩ from NRESET to +3V3. This holds the module in normal operation. MCU drives NRESET low to reset the module.

**BOOT0 pull-down:** 10 kΩ from BOOT0 to GND. Normal boot. MCU drives high only for module firmware update.

### Decoupling cluster

Draw the three VBAT decoupling caps in a vertical stack to the right of VBAT:

```
+3V3 power symbol
  │
  ├── 10 µF (1206 or 0805, X5R) to GND   ← handles TX peak current (87 mA at +20 dBm LoRa)
  ├── 1 µF (0603, X7R) to GND
  └── 100 nF (0603, X7R) to GND
```

---

## Sheet 04 — GPS (`04_gps.kicad_sch`)

**What this sheet does:** connects the LC76GPAMD GNSS module including its VCC decoupling stack (required by Quectel HW Design), the V_BCKP backup power circuit (keeps RTC alive during main-power-off), and the RF antenna chain to the U.FL connector.

### Placement on the A4 page

```
LEFT                    CENTER                     RIGHT
─────────────────────────────────────────────────────────────────────────────
Net labels              [LC76GPAMD U6]             [U.FL J5]
GPS_TX ──────────────── RXD                        ▲
GPS_RX ──────────────── TXD                      RF_IN ── [D2 TVS] ── J5 SIG
GPS_RESET ────────────── RESET_N               
GPS_EN → (via U3        VCC ── VCC decoupling        J5 GND → GND
  on sheet 01)               stack (below)

+3V3_GPS ─────────────► VCC

BOTTOM-LEFT: V_BCKP backup circuit
```

### VCC decoupling stack (Quectel fig. 4 — mandatory)

This exact combination is required. Place all four close to the VCC pin:

```
+3V3_GPS
  │
  ├── Q1 (SMBJ5.0CA TVS, bidirectional) to GND  ← surge/ESD protection
  ├── 10 µF (0805, X5R) to GND                  ← bulk
  ├── 100 nF (0603, X7R) to GND                 ← HF
  └── 33 pF (0603, C0G) to GND                  ← very HF (LNA reference)
              │
              └──► U6 VCC pin
```

Draw this as a vertical stack to the left of U6. The TVS sits at the top (closest to the incoming rail), then 10µF, 100nF, 33pF in order down to GND.

### U6 — LC76GPAMD

```
U6 pin          → connects to
─────────────────────────────────────────────────────────
VCC             → +3V3_GPS (via decoupling stack above)
GND (all)       → GND
TXD             → net label GPS_RX (to MCU PB11, USART3_RX — GPS sends, MCU receives)
RXD             → net label GPS_TX (from MCU PB10, USART3_TX — MCU sends to GPS)
RESET_N         → net label GPS_RESET (from MCU PB8). Pull-up: 10 kΩ to +3V3_GPS.
1PPS            → net label GPS_PPS (to MCU PB9). Push-pull output, no pull-up.
V_BCKP         → V_BCKP net (from backup circuit below)
D_SEL           → 10 kΩ to GND (selects UART mode at startup, per Quectel Table 8)
ANT_ON          → NC flag
WAKEUP          → NC flag
RF_IN           → antenna chain (D2 TVS → J5 U.FL)
GEOFENCE        → NC flag
JAM_IND         → NC flag
3D_FIX          → NC flag
RESERVED        → NC flags
```

### V_BCKP backup circuit (Quectel fig. 5)

Place in the bottom-left of the sheet. This circuit maintains GPS RTC and ephemeris data across main-power-off events, reducing cold-start from ~30 s to ~5 s warm-start.

```
Circuit topology:
                    ┌── 1 kΩ ──┬── supercap (0.1 F) ── GND
                    │           │
+3V3_GPS            │         BCKP_CAP node
     │              │           │
     └──────────────┤      D4 BAT54C (dual Schottky, common-cathode)
                    │      Anode A ◄── +3V3_GPS
                    │      Anode B ◄── BCKP_CAP
                    │      Cathode ──► V_BCKP
                    │                    │
                    │              Decoupling:
                    │              4.7 µF + 100 nF + 33 pF to GND
                    └──────────────────► U6 V_BCKP pin
```

Drawn in KiCAD:
1. +3V3_GPS power symbol → 1 kΩ resistor → BCKP_CAP net junction
2. BCKP_CAP net → supercap C_SC (0.1 F) → GND
3. D4 BAT54C anode A: +3V3_GPS. Anode B: BCKP_CAP. Cathode: V_BCKP net
4. V_BCKP net → 4.7 µF to GND, 100 nF to GND, 33 pF to GND
5. V_BCKP net → U6 V_BCKP pin

### Antenna chain (right side of sheet)

```
U6 RF_IN ── wire ── [D2 SMF05C RF TVS to GND] ── wire ── J5 SIG pin
                                                           J5 GND → GND (via)
```

The D2 TVS (SMF05C or PESD5V0X1BSF) sits in shunt from the antenna signal line to GND. Its job is ESD protection. **Never use SMBJ family here** — their junction capacitance (50–500 pF) detunes the antenna and kills GPS sensitivity. The SMF05C has <2 pF.

Leave optional pi-network footprint pads (C1, C2) in the chain but mark them DNI (do not install). They allow RF tuning on first prototype without a PCB respin.

---

## Sheet 05 — Storage (`05_storage.kicad_sch`)

**What this sheet does:** connects the FRAM (I²C), SD card breakout (SPI), and ePaper module connector (SPI). SD and ePaper share MOSI and SCK.

### Placement on the A4 page

```
LEFT                    CENTER                     RIGHT
─────────────────────────────────────────────────────────────────────────────
[U8 FM24V01A FRAM]      [J6 SD adapter 2×8]       [J7 ePaper 8-pin JST]
I2C_SDA ──────────►  SDA
I2C_SCL ──────────►  SCL
                        SPI1_SCK ◄── label          SPI1_SCK ◄── label
                        SPI1_MISO ──► label         (ePaper no MISO)
                        SPI1_MOSI ◄── label         SPI1_MOSI ◄── label
                        SD_CS ◄── label            EPAPER_CS ◄── label
```

### U8 — FM24V01A-GTR (FRAM, SOIC-8)

```
U8 pin      → connects to
─────────────────────────────────────────────────────────
VCC (8)     → +3V3. Decoupling: 100 nF directly to GND.
GND (4)     → GND
SDA (5)     → net label I2C_SDA
SCL (6)     → net label I2C_SCL
A0 (1)      → NC flag (internal pull-down → address 0x50)
A1 (2)      → NC flag (internal pull-down)
A2 (3)      → NC flag (internal pull-down)
WP (7)      → NC flag (internal pull-down → write-enabled)
```

No external pull-down resistors needed on A0/A1/A2/WP — the datasheet confirms internal pull-downs. Do NOT add external pull-downs; they're redundant.

### J6 — SD adapter module (2×8 pin header)

The Tinytronics SD module duplicates each pin into a pair (for strain-relief). Wire each pair to the same net.

```
J6 pin pair → connects to
─────────────────────────────────────────────────────────
1,2  GND        → GND
3,4  VCC        → +3V3
5,6  MISO       → net label SPI1_MISO
7,8  MOSI       → net label SPI1_MOSI
9,10 SCK        → net label SPI1_SCK
11,12 CS        → net label SD_CS
13,14 CD        → NC flag (or to spare GPIO if card-detect needed)
15,16 (varies)  → NC flag
```

**SPI pull-ups on the SD side (add on this sheet):**
- 10 kΩ from MISO to +3V3
- 10 kΩ from CS to +3V3
These ensure the SD card enters SPI mode correctly on cold start.

### J7 — ePaper connector (JST PH B8B, 8-pin)

```
J7 pin  → connects to
─────────────────────────────────────────────────────────
1  VCC  → +3V3
2  GND  → GND
3  DIN  → net label SPI1_MOSI (shared with SD)
4  CLK  → net label SPI1_SCK (shared with SD)
5  CS   → net label EPAPER_CS (from MCU PC13)
6  DC   → net label EPAPER_DC (from MCU PC14)
7  RST  → net label EPAPER_RST (from MCU PC15)
8  BUSY → net label EPAPER_BUSY (to MCU PH0)
```

---

## Sheet 06 — Sensors (`06_sensors.kicad_sch`)

**What this sheet does:** connects the LIS2DW12 accelerometer breakout (I²C) and two DRV5032DULPGM Hall effect sensors (GPIO, push-pull output).

### Placement on the A4 page

```
LEFT                         RIGHT
──────────────────────────────────────────────────────
[J8 LIS2DW12 breakout]       [U10 DRV5032 #1 beugel]
Header A: power + I2C
Header B: interrupts + mode   [U11 DRV5032 #2 pin]
```

### J8 — LIS2DW12 breakout (2× 1×4 pin header)

The module has two 4-pin headers. **Verify the pinout of your specific Tinytronics SKU before wiring — different breakout sources have different header assignments.**

Typical wiring (confirm against actual module):

```
Header A (power + I²C):
  Pin 1 VCC   → +3V3
  Pin 2 GND   → GND
  Pin 3 SDA   → net label I2C_SDA
  Pin 4 SCL   → net label I2C_SCL

Header B (interrupt + mode select):
  Pin 1 INT1  → net label ACCEL_INT1 (to MCU PB13)
  Pin 2 INT2  → net label ACCEL_INT2 (to MCU PB14)
  Pin 3 SDO/SA0 → GND (selects I²C address 0x18; tie to +3V3 for 0x19)
  Pin 4 CS    → +3V3 (forces I²C mode; per LIS2DW12 datasheet sec. 6.2)
```

CS must be tied to +3V3 (not left floating) when using I²C mode. The internal pull-up (~50 kΩ) would hold it, but the datasheet explicitly recommends an explicit tie.

### U10 — DRV5032DULPGM (Hall sensor #1, beugel/shackle)

The DU variant has **4 pins** in a TO-92 package — not 3. OUT1 detects north pole, OUT2 detects south pole. The prototype wires only OUT2 (south pole detection).

```
U10 pin     → connects to
─────────────────────────────────────────────────────────
Pin 1 VCC   → +3V3. Decoupling: 100 nF immediately to GND.
Pin 2 OUT1  → NC flag (north-pole output, unused in prototype)
Pin 3 GND   → GND
Pin 4 OUT2  → net label HALL_BEUGEL (to MCU PB4)
```

No pull-up resistor on OUT2 — the DRV5032DU has push-pull output.

### U11 — DRV5032DULPGM (Hall sensor #2, locking pin)

Identical wiring to U10, except OUT2 → net label HALL_PIN (to MCU PB5).

---

## Sheet 07 — Actuator (`07_actuator.kicad_sch`)

**What this sheet does:** connects the servo motor connector, current-sense shunt, bulk decoupling, and the status LED with its current-limit resistors.

### Important layout note for this sheet

The servo section and LED section are logically separate. Divide the sheet into two horizontal zones:
- **Top half:** servo and current sense
- **Bottom half:** LED

Do NOT mix components from the two sections or let wires from one cross through the other. This was the source of diagonal-wire problems in the generated version.

### Placement on the A4 page

```
TOP (servo section, y = 40–110)
─────────────────────────────────────────────────────────────────────────────
LEFT                         CENTER                       RIGHT
[C70 470µF]                  [J9 servo connector]
[C71 100nF]                        │
       │                      Pin 2 GND
       │                           │
+5V_SERVO ──────────────────► Pin 1 V+
                              Pin 3 SIG ◄──── SERVO_PWM

                         Pin 2 GND ── R70 (0.05Ω) ── GND (board)
                                          │
                                    SERVO_ISENSE label

BOTTOM (LED section, y = 130–190)
─────────────────────────────────────────────────────────────────────────────
LED_RED ── R71 (470Ω) ──┐
                         ├── [D3a red cathode] ── [D3b green cathode] ── R72 (330Ω) ── LED_GREEN
                         │
                    +3V3 ── common anode of both LEDs
```

### J9 — Servo connector (JST PH B3B, 1×3)

```
J9 pin      → connects to
─────────────────────────────────────────────────────────
Pin 1 V+    → +5V_SERVO power symbol (red wire on TD-8120MG cable)
Pin 2 GND   → one side of R70 (shunt resistor). The other side goes to board GND.
Pin 3 SIG   → net label SERVO_PWM (from MCU PA1, TIM2_CH2)
```

**Pin order matters.** The TD-8120MG cable is: Pin 1 = red = V+, Pin 2 = brown = GND, Pin 3 = orange = signal. If the connector symbol has a different ordering, check it carefully before wiring.

### R70 — Current-sense shunt (0.05 Ω, 2 W, 2512 package)

This resistor sits in the servo's GND return path. It creates a small voltage drop proportional to servo current, which the MCU reads as an analogue signal.

```
Servo GND return path:
J9 Pin 2 (GND) ─── R70 (0.05 Ω) ─── GND (board ground plane)
                         │
                   SERVO_ISENSE ──► net label to MCU PC2 (ADC1_IN3)
```

Tap SERVO_ISENSE from the junction between J9 pin 2 and R70 pin 1 (the servo side, i.e. the HIGH side of the shunt relative to GND). At 2 A stall current: 2 A × 0.05 Ω = 100 mV, which the ADC reads as code ~124 out of 4095. Coarse but sufficient to detect stall.

Add a 100 nF filter cap from SERVO_ISENSE to GND close to the MCU ADC pin (place on this sheet, not the MCU sheet, to show intent).

### Bulk decoupling (servo rail)

Place C70 and C71 close together near J9. Both connect between +5V_SERVO and GND.

```
+5V_SERVO power symbol
  │
  ├── C70 (22 µF X7R, 0805) to GND   ← per BIKERA_SCHEMATIC_PROMPT.md
  └── C71 (100 nF ceramic, 0603) to GND
```

These handle the large current pulses the servo draws during motion — without them the 5 V rail dips and can brownout the MCU. Note: the generated KiCad sheet currently has C70 = 470 µF electrolytic. If you want to keep the larger value for extra headroom, that is electrically fine but conflicts with the BOM spec. 22 µF is the spec.

### LED section — D3 (BL-BEG204-7-E)

This is a **common-anode** bicolor LED: one shared anode, separate red and green cathodes. Wire it as two separate LED sub-symbols (or use the LED_DUAL_KAK symbol if available).

**Critical layout rule:** keep the resistors and LEDs on the **same horizontal line**. The LED K pin and the resistor must be at the same y-coordinate so the connecting wire is perfectly horizontal. This avoids diagonal wires.

```
Correct horizontal layout:

LED_RED label ─── R71 (470 Ω) ─── [LED red cathode → red anode] ─── +3V3
                                                                (common anode)
LED_GREEN label ── R72 (330 Ω) ── [LED green cathode → green anode] ─── +3V3
```

Drawn in KiCAD:
- Place R71 at, say, (50, 160). It is horizontal (rotated 90°), so pin 1 is left, pin 2 is right.
- Place LED D3a with K pin at the same y-coordinate as R71 pin 2 (rightward, horizontal).
- Connect R71 pin 2 → D3a K with a horizontal wire.
- Connect D3a A → +3V3 power symbol (above).
- R71 pin 1 → net label LED_RED (going left).

Do the same for the green channel at y = 175 (or whatever keeps the two rows separate without overlapping).

**Resistor values:**
- R71 (red): 470 Ω → ~2.8 mA with Vf = 2.0 V. Visible indoors.
- R72 (green): 330 Ω → ~3.3 mA with Vf = 2.2 V. Balanced brightness.
- For outdoor use swap to 180 Ω (red) and 150 Ω (green) for ~8 mA.

---

## Sheet 08 — Secure (`08_secure.kicad_sch`)

**What this sheet does:** connects the ATECC608B ECC secure element. This is one of the simplest sheets: just the chip, a decoupling cap, and I²C labels.

### Placement on the A4 page

Place U12 in the center. Net labels on the left, power symbols on the right. This sheet already follows the correct layout pattern.

### U12 — ATECC608B-SSHDA-T (SOIC-8)

```
U12 pin     → connects to
─────────────────────────────────────────────────────────
VCC (8)     → +3V3 power symbol. Decoupling: 100 nF ceramic immediately below to GND.
GND (4)     → GND power symbol
SDA (5)     → net label I2C_SDA (entering from left)
SCL (6)     → net label I2C_SCL (entering from left)
NC (1,2,3,7)→ NC flags on all four
```

I²C address: 0x60 (factory default). No configuration needed.

No pull-ups on this sheet — they live on sheet 01 (next to the BQ25630).

---

## Sheet 09 — Bridge (`09_bridge.kicad_sch`)

**What this sheet does:** connects the CP2102N USB-to-UART bridge, which gives the host PC a virtual COM port to the MCU that is independent of the ST-Link VCP. D+/D− come from the USB-C receptacle through the USBLC6 on sheet 01.

### Placement on the A4 page

```
LEFT                         CENTER                       RIGHT
─────────────────────────────────────────────────────────────────────────────────
Net labels                   [U13 CP2102N QFN-24]         Net labels
USB_DP ──────────────────►   D+                           BRIDGE_TX ──►
USB_DN ──────────────────►   D-                           BRIDGE_RX ◄──
                             VBUS (sense only,
USB_VBUS ── divider ──────►    not power)
                             VDD/VREGIN/VIO ◄── +3V3
                             GND / EPAD  → GND
Decoupling caps cluster on right side of U13
```

### U13 — CP2102N-A02-GQFN24

```
U13 function        → connects to
─────────────────────────────────────────────────────────
D+                  → net label USB_DP. No series resistor — CP2102N has integrated termination.
D-                  → net label USB_DN. Same.
VBUS (sense pin)    → see VBUS divider below. NOT a power pin. NOT 5 V direct.
VDD                 → +3V3. Decoupling: 4.7 µF + 100 nF to GND (both caps, right next to pin).
VREGIN              → +3V3 (tied to VDD, internal 5 V regulator unused).
                       Decoupling: 4.7 µF + 100 nF to GND.
VIO                 → +3V3 (same rail). Decoupling: 4.7 µF + 100 nF to GND.
GND + EPAD          → GND. At least 4 thermal vias through EPAD to ground plane.
RSTb                → 1 kΩ pull-up to +3V3 (VIO). No reset button needed.
TXD                 → net label BRIDGE_TX (to MCU PC1, LPUART1_RX)
RXD                 → net label BRIDGE_RX (from MCU PC0, LPUART1_TX)
RTS, CTS, DSR, DTR  → NC flags
SUSPEND, SUSPEND#   → NC flags
GPIO.0 – GPIO.3     → NC flags
all others          → NC flags
```

**Total decoupling: 3 pairs × (4.7 µF + 100 nF) = 6 capacitors.** This is per the Silicon Labs datasheet requirement "4.7 µF and 0.1 µF bypass capacitors required for each power pin." Missing even one pair can cause USB enumeration failures.

### VBUS sense divider

The CP2102N uses its VBUS pin as a digital input to detect when USB is connected — NOT as a power supply. The pin cannot tolerate 5 V directly (absolute max = VIO + 2.5 V = 5.8 V, but VIH = 2.7 V). A resistor divider scales 5 V → ~3.4 V.

```
USB_VBUS (5 V) ─── 22.1 kΩ ─── VBUS sense node ─── 47.5 kΩ ─── GND
                                       │
                               to U13 VBUS pin
```

With 5 V in: sense node = 5 × 47.5/(22.1+47.5) = 3.41 V. Above VIH (2.7 V), below absolute max (5.8 V). Connect this divider with short wires immediately next to U13.

---

## Cross-check before opening KiCAD

Before touching the KiCAD files, run through this checklist mentally:

| Item | Correct value |
|---|---|
| 3.3 V buck-boost | RT6150B (prototype). NOT RAA2361052 (that's Keuze finaal). |
| BQ25630 RPG pull-up | 2.2 kΩ — not 10 kΩ |
| BQ25630 CREGN | 4.7 µF 10 V — not 100 nF |
| BQ25630 CBTST | 47 nF between BTST and SW — often missing |
| RT6150B PS pin | Tie LOW (GND) = PSM mode. HIGH = forced PWM. Do not confuse. |
| RT6150B VINA | Connects directly to VIN, no RC filter |
| TPS61253F MODE | Tie HIGH (100 kΩ to VOUT) = forced PWM. Do not leave floating. |
| I²C pull-ups | 10 kΩ on SDA and SCL on sheet 01 ONLY — no duplicates on other sheets |
| LED R (red) | 470 Ω → ~2.8 mA |
| LED R (green) | 330 Ω → ~3.3 mA |
| Servo pin 1 | V+ (+5V_SERVO), pin 2 GND (via Rsense), pin 3 PWM |
| SERVO_ISENSE | Tap at the servo-side of Rsense (between J9 pin 2 and R70 pin 1) |
| USB D+/D- | Go to CP2102N (sheet 09), NOT to BQ25630. BQ25630 D+/D- pins = NC. |
| USBLC6 | Sits between J1 D+/D- and everything downstream (sheet 01, close to J1) |

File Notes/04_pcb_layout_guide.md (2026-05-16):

# Bikera — PCB Layout Guide (Prototype Build)

**Companion to `01_library_audit.md`, `02_footprints_explained.md`, and `03_schematic_capture_guide.md`.** Schematic capture is complete and ERC is clean. This doc covers what happens after `Tools → Update PCB from Schematic`: stackup, board outline, placement priorities, routing rules, RF considerations, DRC settings, and manufacturing file prep.

**Prerequisites before opening the PCB editor:**
- Schematic ERC clean, BOM matches `Bikera.xlsx` Keuze prototype = TRUE rows
- `Update PCB from Schematic` executed; all footprints landed in the PCB editor
- Decisions made on the items listed in §1 audit "What's NOT in Keuze prototype but you may want anyway"
- Enclosure dimensions known (board outline, mounting hole positions, antenna pigtail exit points, USB-C accessibility)
- Fab house picked (JLCPCB / PCBWay / Aisler / Eurocircuits) — their minimum DRC values affect your design rules

## Stackup decision

The BQ25630YBGR DSBGA is the single component that drives the stackup decision. A 0.4 mm pitch, 5×5 ball BGA has 9 inner balls that cannot fan out on 2 layers. Two stackup options:

### Option A — 4-layer (recommended)

```
Top (L1)      ── signal + components ────────────────  35 µm (1 oz) Cu
              ── prepreg ──────────────────────────── ~150 µm FR4
Inner 1 (L2)  ── solid ground plane ─────────────────  17 µm (½ oz) Cu
              ── core ─────────────────────────────── ~1100 µm FR4
Inner 2 (L3)  ── power distribution + low-speed sig.   17 µm (½ oz) Cu
              ── prepreg ──────────────────────────── ~150 µm FR4
Bottom (L4)   ── signal + components ────────────────  35 µm (1 oz) Cu
```

Total thickness ~1.6 mm. Standard JLCPCB / PCBWay 4-layer offering, ~€50 for 5 boards at 100×100 mm.

**Why this layout works:**
- L1 carries most signals and all RF
- L2 solid ground gives 50 Ω microstrip impedance reference for the GPS U.FL trace
- L3 routes the power rails (+3V3, +3V3_GPS, +5V_SERVO, +SYS, +VBAT)
- L4 hosts the BQ25630YBGR inner-ball fan-out vias landing on L4 traces
- BGA fan-out: drill 0.2 mm vias from inner balls down to L4, route on L4

### Option B — 2-layer (don't recommend, but documented)

2 layers can't host the BQ25630YBGR's 9 inner balls. Workarounds:
- Use BGA's outer 16 balls only — but several power/ground pins are inner balls, defeating purpose
- Switch to a non-BGA charger (BQ25895RTWR QFN — was deselected for USB-C reasons)
- Use blind/buried vias on a 2-layer board — fab pricing approaches 4-layer cost anyway

**For the prototype, go 4-layer.** The €50 incremental cost is worth not respinning.

## Board outline

The Bikera lock enclosure size determines the PCB outline. From `Readme.md`:
- Prototype is a development board (not production-size constrained)
- Mounting holes for M3 standoffs at four corners
- USB-C accessible from one edge
- Battery (Li-ion 18650 ×2-4 per Readme — but `Keuze prototype` only shows 1-cell capable charger; verify with project lead) connected via JST PH cable
- Antenna FPCs exit via MHF4 pigtails — flexible placement
- Servo connected externally via JST PH cable

**Suggested initial outline:** 80 × 100 mm rectangle, M3 mounting holes at corners (3.2 mm holes, 6 mm copper-free annular ring). Plenty of room to spread the layout out; later revisions can shrink.

```
KiCAD PCB Editor → File → Page Settings: A4, landscape
Edge.Cuts layer: rectangle 80×100 mm
M3 mounting holes (4): `MountingHole:MountingHole_3.2mm_M3` at (5,5), (75,5), (5,95), (75,95)
```

## Placement order

Place big or constrained-position parts first, then fill in around them:

### Step 1 — Constrained-position parts

These parts have to go in specific places relative to the board edge or enclosure:

1. **USB-C receptacle (J1)** — at one edge of the board, oriented for cable insertion. The PCB edge must align with the receptacle's mating face. **Place the CP2102N (U11) within 15 mm of the receptacle** so the D+/D− differential pair stays short — the bridge is the consumer of D+/D−, the charger only needs the CC pins via shorter routes.
2. **Battery connector (J2)** — near the BQ25630 to minimise BAT-pin trace impedance.
3. **Servo connector (J7)** — at the opposite edge from USB-C, so servo cable doesn't tangle with the charge cable. **The 2512 Rsense shunt sits in the GND return path between J7 pin 1 and the board ground plane** — place it within 5 mm of J7, with one pad tied to a small isolated GND-side island (the `SERVO_GND_HIGH` net) and the other pad tied to the main ground plane.
4. **ST-link BTB card edge (J3)** — at one edge with clearance for the STLINK-V3MINIE to plug in. The probe is 15 × 42 mm; reserve at least 50 mm × 25 mm of "air space" around the connector on the keep-out diagram.
5. **BOOT and RESET buttons (SW1, SW2)** — on the edge near the ST-link card edge connector for easy access during debug. If the enclosure has button cutouts elsewhere, place them there instead.
6. **GPS U.FL receptacle (J4)** — near the LC76GPAMD module. Goal: minimise the U.FL trace length (ideally <10 mm).
7. **GPS V_BCKP supercap** — within 10 mm of the LC76GPAMD V_BCKP pin. The supercap is bulky (typical 0.1 F radial supercap is ~6 mm diameter, ~5 mm tall) — reserve a footprint placement square accordingly.
8. **RAK11720 MHF4 jacks** — already on the module itself. The module placement decides where the antenna pigtails exit. **The MHF4 jacks must face the side of the board where the antenna FPCs will be mounted in the enclosure.**
9. **ePaper connector (J6)** — adjacent to where the ePaper module will be visible through the enclosure window. The 8-pin JST PH cable can route across the board, so this isn't tightly constrained — but keep it >20 mm from the RAK11720 to avoid SPI noise coupling into the radio.
10. **Status LED (D2)** — near a viewing window in the enclosure. Edge placement common.
11. **Hall sensors (U8, U9)** — at the lock's mechanical sensing positions. **Mechanical engineering decides** these positions, not PCB engineering. Place per the mech drawing.

### Step 2 — Power section (place as a tight cluster)

The power section should be a tight, well-organised cluster to minimise loop areas in the switching converters.

1. **BQ25630YBGR (U1)** — central. Per verified TI datasheet sec. 9.4 (Layout) plus pin grid: VBUS pins are A1/B1 (top edge), SW pins are A3/B3/C3 (top middle column), BAT pins are E1/E2/E3 (bottom edge), SYS pins are D1/D2/D3 (bottom middle column).
   - **Critical loop 1 (VBUS → PMID):** place the 1 µF VBUS cap and 10 µF PMID cap immediately adjacent to columns 1–2 of the package, on the **same side**, with returns through the closest PGND ball (column 4)
   - **Critical loop 2 (SW → inductor → SYS):** route the SW node (the high-dv/dt net) as short and wide as possible to the inductor, then back to the SYS pins. Keep the loop area minimum — this loop area determines EMI behaviour
   - **47 nF BTST cap:** between BTST (B5) and the SW node; very close to the package
   - **REGN 4.7 µF cap:** very close to REGN ball (A5) with a short GND return
2. **RT6150B (U2)** — close to BQ25630 SYS output, ideally within 10 mm. Its inductor (L2) between LX1 (pin 4) and LX2 (pin 2), kept short. The VOUT (pin 1) and FB (pin 10) trace to R1/R2 divider stays close and away from the LX node.
3. **TCR3UG33A (U3)** — close to the LC76GPAMD. The whole point of a separate LDO for GPS is low noise, which means short connection between LDO and load.
4. **TPS61253F (U4)** — close to the servo connector (J7). Its inductor (L3) within 3 mm of SW pin. Its output cap (22 µF) within 5 mm of VOUT.
5. **Bulk caps:** each switching converter's bulk cap (10–22 µF) within 5 mm of the chip's power pin.
6. **Thermal vias under BQ25630 PGND balls (A4, B4, C4):** at least one via per ball into L2 ground pour. The 30-ball DSBGA has limited heat-spreading area; missing thermal vias means the chip enters thermal regulation prematurely at high charge currents.
7. **Thermal vias under RT6150B EPAD:** a 2×2 or 3×3 via grid stitched to L2 ground pour. The 2.5×2.5 package has θJA = 40.9 °C/W — at 800 mA × ~0.3 W power dissipation, junction temperature rises 12 °C above ambient with a good thermal pad. Without proper EPAD soldering, that becomes 50+ °C and the chip enters thermal shutdown.

### Step 3 — MCU section

1. **STM32L431 (U7)** — central. Per-pin decoupling caps within 2 mm of each VDD pin pair (one cap per VDD pin, on the same layer if possible). Note: reference designators are illustrative; in your KiCAD project the MCU may be U1 or any other number — keep the BQ25630 charger and the MCU on **different** references to avoid confusion in BOMs.
2. **VDDA decoupling cluster** (100 nF + 10 nF + 1 µF) within 5 mm of the VDDA pin.
3. **CP2102N (U11)** placement was decided in Step 1 (near USB-C). Its TXD/RXD signals route to MCU LPUART1 pins (PC0/PC1) — keep this trace pair under 80 mm to avoid signal integrity issues. The pair is just a UART (max 921600 baud), not USB Full Speed, so it's not impedance-critical.
4. **MCU adjacent to RAK11720** — short UART traces matter less than I²C bus length (lower frequency) but a tidy layout still helps signal integrity.

### Step 4 — Sensor / interface section

1. **FRAM (U7)** — anywhere on the I²C bus path. Stock SOIC-8, no special constraints.
2. **ATECC608B (U10)** — same. Adjacent to FRAM is convenient.
3. **LIS2DW12 module** — flexibility here. If the project plans to use the accelerometer for tamper detection, place it physically close to where vibration originates (lock body). For a dev board, position it where it can be visible during debug.
4. **SD card breakout** — anywhere convenient; SPI tolerates moderate trace lengths.

## Routing

### Layer assignment policy

- **L1 (Top):** signals (preferred), all RF (mandatory), components (SMD top)
- **L2 (GND):** solid ground plane — **do NOT route signals on L2 unless absolutely necessary, and never break the plane under RF traces**
- **L3 (PWR):** power rails as area fills:
  - `+3V3` fill covering most of the MCU + sensor + storage region
  - `+SYS` fill near the power section
  - `+3V3_GPS` smaller fill near GPS
  - `+5V_SERVO` small fill near servo connector
  - `+VBAT` small fill near charger and battery connector
  - Each fill is a polygon zone, ground-stitched at boundaries
- **L4 (Bottom):** secondary signals, BGA fan-out routing, components (SMD bottom — minimise; ideally all components on L1)

### Track widths

| Net | Min width (mm) | Typical width (mm) | Reason |
|---|---|---|---|
| Digital signals | 0.15 | 0.2 | Standard hobbyist fab capability (JLCPCB minimum 0.1 mm, with safety margin) |
| I²C bus | 0.15 | 0.2 | Same |
| SPI bus | 0.15 | 0.2 | Same |
| UART (RAK11720, GPS) | 0.15 | 0.2 | Same |
| `+3V3` | 0.5 (area fill preferred) | — | ~500 mA peak |
| `+3V3_GPS` | 0.4 | — | ~50 mA continuous |
| `+5V_SERVO` | 0.8 | — | Servo can pull >2 A peak |
| `+SYS` | 0.8 | — | Up to charger 5 A capability |
| `+VBAT` | 1.0 | — | Up to charge current 5 A from cell |
| `GND` | area fill (L2) | — | Continuous plane |
| BAT to charger | 1.5 | — | 5 A continuous |
| **Inductor SW node** (BQ25630, RT6150B, TPS61253F) | 0.5 | 0.8 | Minimize loop area; this is the high-dV/dt node |
| **U.FL trace to GPS** | calculated 50 Ω | see below | RF impedance match |

### Via sizes

| Use | Drill (mm) | Diameter (mm) | Notes |
|---|---|---|---|
| Standard signal via | 0.3 | 0.6 | JLCPCB minimum 0.2 mm; safety margin |
| Power via | 0.4 | 0.8 | For >500 mA paths |
| BGA fan-out via | 0.2 | 0.4 | Required for BQ25630 inner balls — must specify "0.2 mm minimum drill" to fab |
| Ground stitching | 0.3 | 0.6 | Place every 5–10 mm along ground edges, especially around RF |

### GPS U.FL trace — the most critical RF route

The trace from LC76GPAMD's ANT pin to the U.FL receptacle's signal pin must be 50 Ω controlled impedance.

**On a 4-layer board with L1 signal and L2 ground reference, 1.6 mm overall thickness:**
- Top dielectric thickness ~0.2 mm (prepreg between L1 and L2)
- L1 copper thickness ~35 µm
- FR4 εr ≈ 4.3

Using the standard microstrip formula (or KiCAD's built-in calculator: `Tools → Calculator → TransLine → Microstrip Line`):
- **For 50 Ω at these dimensions: trace width ≈ 0.36 mm**

Verify in KiCAD's calculator with your actual fab's stackup (each fab publishes their layer thicknesses).

**Routing rules for the U.FL trace:**
1. Keep it as short as possible — target <10 mm, hard limit 20 mm
2. Straight or single 45° bend, no sharp 90° corners
3. No other signals within 3× trace-width spacing on the same layer
4. Solid ground on L2 directly underneath, no breaks
5. Stitching vias every 3 mm on both sides of the trace, connecting L2 ground to top-side ground fill (creates a coplanar waveguide grounded structure for better isolation)
6. The receptacle's GND pads connected directly to L2 plane with multiple vias (≥4 vias)
7. **The low-capacitance RF TVS (SMF05C or PESD5V0X1BSF)** sits in series-shunt along this trace: signal continues through to the receptacle, TVS sits as a shunt to GND. Place it **close to the U.FL receptacle** (within 3 mm) — TVS protects against discharge events on the antenna side, so it needs to clamp before the energy reaches the LC76G. Its GND pad goes directly to L2 with its own via, no shared via with anything else.
8. **C1/C2 π-network pads (NM):** place the pads in the BOM layout but mark "DNI" / "NM" on F.Fab. Even if not populated, having pads on the PCB makes RF tuning possible without a respin.

If the trace must be longer than 20 mm, switch from microstrip to coplanar waveguide with ground (CPWG) — narrower trace, ground fill on the same layer with controlled gap. KiCAD calculator's "Coplanar Line" mode does this calc.

### USB D+/D− pair — second critical route

The differential pair from the USB-C receptacle to the CP2102N bridge is USB Full Speed (12 Mbit/s). USB-FS has a lot of timing margin compared to the GPS RF, but bad routing still causes enumeration failures or intermittent drops.

**Routing rules:**
1. Route as a differential pair, both halves on the same layer
2. **Target 90 Ω differential impedance.** On 4-layer stackup with L2 ground reference: traces ~0.4 mm wide, 0.2 mm spacing — verify with KiCAD's calculator (`Tools → Calculator → TransLine → Coupled Microstrip Line`)
3. Length-matched within 1 mm (USB-FS tolerates much more but it's good practice)
4. No vias if avoidable; if necessary, both halves of the pair via together at the same point
5. Total length under 80 mm
6. Ground reference on L2 must be solid under the entire pair — no splits
7. Keep at least 0.4 mm clear from other signals on the same layer (3× pair spacing)

The CP2102N has internal D+/D− termination, so external 27 Ω series resistors are NOT needed. Add `~/NC` flags if your schematic has placeholder resistors so they don't end up in the BOM.

### Switching converter loops

For BQ25630, RT6150B, and TPS61253F, minimize the high-dI/dt loop:
- Input cap → IC VIN pin → IC GND pin → back to input cap
- IC SW pin → inductor → output cap → back to IC GND

These two loops should both be small in area and close to the chip. The architecture rule: **input cap, output cap, and IC ground pins should share a contiguous ground pour with vias to L2 plane within 2 mm of each cap.**

For the BQ25630YBGR DSBGA specifically: TI's BQ25630 EVM gerbers show one good layout. Open those gerbers in a viewer and reference them. Don't reinvent the loop geometry.

### Sharing of SPI bus

The SD card and ePaper share `SPI_MOSI` and `SPI_SCK`. Route the bus as a daisy chain:
- MCU → ePaper connector → SD module connector
- Or: MCU → branch → ePaper + SD module

For SPI at L431's typical 8 MHz, either topology works. Daisy chain has slightly better signal integrity (no stub effects); branch is shorter total. Prototype: branch is fine.

### I²C bus routing

The I²C bus has 4 slaves: BQ25630, FRAM, LIS2DW12, ATECC608B.

- Route as a single trace pair (SDA, SCL) visiting each slave
- Total bus length kept under 50 mm (typical "short bus" rule)
- Pull-ups at the bus master (MCU) end
- No stubs longer than 5 mm from the main trace to each slave

## Ground plane strategy

The L2 plane is **continuous ground** with no breaks except where vias punch through.

- Stitch the top-side ground fill to L2 with vias every 5–10 mm
- **Around the RAK11720 module**: dense stitching (vias every 2–3 mm) along the module's GND castellations to ensure good ground reference for the module's internal RF
- **Around the U.FL receptacle and the GPS trace**: dense stitching to maintain coplanar waveguide ground
- **Under the BQ25630 DSBGA**: every ball that is GND should have its own via to L2 (no shared via clusters — each ball's via straight down)

**Do NOT split ground into AGND and DGND** on this prototype. The single-plane approach is robust and easier to debug. If the LC76GPAMD shows excessive noise on first bring-up, address it with shielding (RF can) over the GPS section, not with a split plane.

## DRC configuration

**File → Board Setup → Design Rules**

### Net classes

Define classes that match the track widths above:

| Class | Members | Clearance | Track | Via Hole | Via Diameter |
|---|---|---|---|---|---|
| Default | (most digital signals) | 0.15 mm | 0.2 mm | 0.3 mm | 0.6 mm |
| Power | +3V3, +3V3_GPS, +SYS | 0.2 mm | 0.5 mm | 0.4 mm | 0.8 mm |
| HighCurrent | +VBAT, +5V_SERVO, BAT, charger SW nets | 0.25 mm | 0.8 mm | 0.4 mm | 0.8 mm |
| RF | (GPS U.FL trace) | 0.4 mm | 0.36 mm | 0.3 mm | 0.6 mm |
| Differential | USB_DP, USB_DN (to CP2102N bridge) | 0.15 mm | 0.4 mm matched, 0.2 mm pair gap | 0.3 mm | 0.6 mm |

Assign each net to its class via the **Net Classes** tab.

### Constraints

- **Min clearance:** 0.15 mm (matches fab capability with margin)
- **Min track width:** 0.15 mm
- **Min via hole:** 0.2 mm (BGA fan-out); set 0.3 mm as min for standard vias
- **Min via diameter:** 0.4 mm (BGA); 0.6 mm for standard
- **Min annular ring:** 0.13 mm

### Other settings

- **Solder mask expansion:** 0.05 mm (fab default; can override per-footprint for DSBGA)
- **Silkscreen min text height:** 0.8 mm (smaller may be unreadable on fab silkscreen)

## DRC iteration

Run DRC. Iterate to clean. Common errors and fixes:

| Error | Likely cause | Fix |
|---|---|---|
| Clearance violation | Two parts too close | Move one |
| Track too narrow | Power net routed at default width | Reassign to Power class, redraw |
| Via too small | Default via on a BGA | Manually override to small via on BGA fan-out tracks only |
| Unconnected net | Forgot a wire | Find net, route it |
| Hole-to-hole clearance | Two through-holes overlapping | Move one |
| Silkscreen on pad | Silkscreen text overlaps a pad | Move text or shorten |
| Courtyard overlap | Two components physically occupy the same space | Move one |

**Iterate until 0 errors and only acceptable warnings.** Document any warnings you choose to ignore (e.g. "silkscreen on copper at U1 corner — accepted, just a courtyard touch").

## Mechanical and 3D check

After DRC clean:

1. **View → 3D Viewer.** Inspect the board with all components rendered.
2. Verify clearance: USB-C receptacle protrudes from the edge, ST-link card edge connector has space for the probe, MHF4 cables can exit without colliding with components.
3. Verify the battery connector can mate with the battery's cable.
4. Verify mounting hole positions match your enclosure CAD.
5. Export STEP: **File → Export → STEP**. Open in FreeCAD or Onshape with the enclosure model. Verify everything fits.

## Manufacturing file generation

When DRC is clean and 3D check passes:

1. **File → Plot.** Output format: Gerber. Layers: F.Cu, B.Cu, In1.Cu, In2.Cu, F.Mask, B.Mask, F.SilkS, B.SilkS, F.Paste, B.Paste, Edge.Cuts. Drill file: **Generate Drill File** with PTH and NPTH separated, Excellon format.
2. Pack the gerbers + drill files into a ZIP.
3. **Upload to fab** (JLCPCB / PCBWay / Eurocircuits). Verify their viewer shows the board correctly — pay particular attention to:
   - 4 layers correctly stacked
   - Outline visible on Edge.Cuts
   - Mounting holes drilled
   - BGA pads visible and correctly sized
4. **BOM file:** export from KiCAD (Tools → Generate BOM). Format depending on fab: for JLCPCB assembly, use their template; otherwise CSV with reference, value, footprint, MPN.
5. **CPL (centroid placement) file:** Tools → Generate Position File. Format: CSV, mm, top + bottom separately.

## Pre-fab checklist

Before clicking "place order":

**Component presence:**
- [ ] DRC clean
- [ ] All `Keuze prototype = TRUE` parts present in the BOM
- [ ] USB-C receptacle present (not in original BOM but required)
- [ ] U.FL receptacle present for GPS antenna
- [ ] USBLC6 ESD protection on USB-C present
- [ ] CC1 / CC2 pulldowns present (2× 5.1 kΩ to GND)
- [ ] **CP2102N UART-to-USB bridge present** (per architecture diagram) with D+/D− routed from USB-C receptacle to bridge (NOT to BQ25630)
- [ ] **GPS V_BCKP backup circuit present** (BAT54C + 0.1 F supercap + 1 kΩ + 4.7 µF + 100 nF + 33 pF + SMBJ5.0CA TVS) — OR explicitly omitted if accepting cold-start every boot
- [ ] **GPS VCC decoupling triplet present** (10 µF + 100 nF + 33 pF + SMBJ5.0CA TVS — per LC76G HW Design fig. 4)
- [ ] **GPS antenna RF TVS present** (low-cap SMF05C or PESD5V0X1BSF — NOT SMBJ family) between LC76G ANT pin and U.FL signal
- [ ] **Servo Rsense present** (0.05 Ω 2 W 2512 SMD shunt in GND return path of J7) with SERVO_ISENSE to MCU ADC (PC2)
- [ ] **BOOT and RESET buttons present** (two physical tactile, per architecture diagram "Drukknoppen"). RESET = 0.1 µF cap to GND only (NRST internal pull-up makes external 10 kΩ redundant). BOOT0 = 10 kΩ pull-down to GND (no internal pull on BOOT0)
- [ ] 4 M3 mounting holes

**Critical passive values (per verified datasheets):**
- [ ] BQ25630 CVBUS = 1 µF (NOT 10 µF — datasheet table 7-3)
- [ ] BQ25630 CPMID = 10 µF + 100 nF parallel
- [ ] BQ25630 CSYS = 20 µF (22 µF E12 acceptable)
- [ ] BQ25630 CBAT = 10 µF
- [ ] BQ25630 CREGN = **4.7 µF 10 V** (NOT 1 µF or 100 nF)
- [ ] BQ25630 CBTST = **47 nF** between BTST and SW (this is the bootstrap cap — missing it stops switching)
- [ ] BQ25630 RPG = 2.2 kΩ pull-up (NOT 10 kΩ — datasheet specifies 2.2 kΩ)
- [ ] BQ25630 RINT, RSDA, RSCL = 10 kΩ pull-ups
- [ ] BQ25630 RBATP = 100 Ω series to battery+ (Kelvin sense)
- [ ] BQ25630 TS thermistor = 103AT-2 10 kΩ (or fixed divider for bench bring-up only)
- [ ] BQ25630 L = 1 µH, ≥5 A saturation
- [ ] RT6150B CIN = 10 µF, COUT = 20 µF
- [ ] RT6150B L = 2.2 µH, ≥1.6 A saturation, between LX1 and LX2
- [ ] RT6150B FB divider: R1 = 487 kΩ, R2 = 86.6 kΩ (sets Vout = 3.3 V)
- [ ] RT6150B PS pin tied **LOW** (PSM mode for efficient low-load — earlier draft had this backwards)
- [ ] RT6150B VINA pin tied to VIN directly (per datasheet typical app)

**Footprint verification:**
- [ ] BQ25630YBGR = **30-ball DSBGA**, 2.3 × 2.4 mm, 6×5 grid (NOT 25-ball 5×5 — verify against TI datasheet SLUSFN0A sec. 12)
- [ ] RT6150B = WDFN-10L 2.5 × 2.5 mm, pin 1 = VOUT (top-left), pins 3/9/11 = GND (verify against Richtek DS6150A/B-04 outline)
- [ ] TCR3UG33A WCSP4F = 4-bump 2×2 grid, 0.94 × 0.94 mm
- [ ] TPS61253F DSBGA-9 = 3×3 grid, 1.235 × 1.235 mm
- [ ] CP2102N QFN-24 = 4 × 4 mm with central thermal pad
- [ ] U.FL receptacle pads match the specific MFR you'll buy (Hirose U.FL-R-SMT-1 is the standard)

**Final review:**
- [ ] 3D viewer check passes
- [ ] STEP exported and overlaid with enclosure model — no collisions
- [ ] Gerber viewer (fab side) shows the board correctly
- [ ] BOM cross-references match `Bikera.xlsx` Keuze prototype = TRUE rows PLUS architecture-diagram additions
- [ ] Project files committed to git with a tag corresponding to this fab order

## After fab arrives

1. **Visual inspection** — solder mask, silkscreen, no obvious damage. Compare bare PCB against your gerber viewer image.
2. **Power section first** — assemble ONLY: BQ25630, USB-C receptacle, USBLC6, charger inductor, CC pulldowns, charger decoupling caps, RT6150B, RT6150B inductor and caps. **Don't assemble the rest yet.**
3. **First power-up:**
   - Plug a battery into J2 (~3.7 V Li-ion)
   - **Don't connect USB-C yet**
   - Measure SYS and +3V3 — both should be present
4. **USB-C charging test:**
   - Connect USB-C charger (5 V, ≥1 A)
   - I²C read BQ25630 status register — confirm USB-C source detected and charging
5. **If power section works:** assemble the rest of the board, but **do NOT assemble the RAK11720 yet.**
6. **MCU bring-up (RAK11720 still NOT assembled):**
   - Plug in STLINK-V3MINIE via the BTB card edge connector
   - Flash a blinky on the LED
   - Verify MCU clock + GPIO basics
7. **Peripheral bring-up in order (RAK11720 still NOT assembled):** LED → button (NRST) → I²C scan → UART loopback test → GPS → ePaper → FRAM → SD → accelerometer → hall sensors → servo
8. **RAK11720 bring-up — MUST attach antennas first:**
   - Per RAK datasheet: "Make sure that an antenna is always connected. Using these transceivers without an antenna can damage the module."
   - **Solder the RAK11720 to the board AFTER all other peripherals are validated.**
   - **Before powering the board with RAK11720 mounted: plug in both MHF4 pigtails to FPC antennas (or 50 Ω terminators).**
   - Power on, query the module via UART AT commands (`AT` should return `OK`).
   - Run a low-power TX test before any high-power TX. The first LoRa TX at full +20 dBm into an unconnected antenna can permanently damage the PA.

This staged bring-up catches BQ25630 DSBGA reflow issues, RT6150B issues, MCU issues, peripheral issues, and RAK11720 antenna-mishap issues separately — much faster than full-board assembly followed by debugging "nothing works", and much safer for the €12 RAK module.

## When something doesn't work

Common prototype failures and their likely causes:

| Symptom | Likely cause | First check |
|---|---|---|
| No SYS rail | BQ25630 not soldered properly (DSBGA balls not wetting) | X-ray or rework with hot plate; reflow at higher temp |
| SYS present but +3V3 not | RT6150B issue: WDFN thermal pad not soldered, or EN pin not high | Measure RT6150B EN pin voltage; check thermal pad continuity to ground |
| +3V3 present but MCU dead | NRST stuck low, or VDD not actually 3.3 V | Measure NRST; check all 3 VDD pins independently |
| MCU runs, no I²C ACK from any device | I²C bus pull-ups missing or wrong value | Measure SDA/SCL rest voltage (should be ~3.3 V) |
| GPS doesn't lock | GPS antenna issue, U.FL trace impedance bad, or VBACKUP issue | Measure GPS output power on antenna pin with sniffer / replace antenna |
| RAK11720 doesn't respond to AT | UART crossed, or module BOOT/RESET stuck | Check BOOT pulled low, RESET pulled high, swap TX/RX if needed |
| Servo doesn't move | TPS61253F not enabled (MCU GPIO low), or PWM signal not generated | Measure +5V_SERVO when EN_5V_SERVO is high |
| Host PC doesn't see virtual COM port from bridge | CP2102N D+/D− miswiring, or VBUS sense not connected | Measure VBUS at CP2102N pin; verify USB enumeration with `dmesg` (Linux) or Device Manager (Windows). If chip not enumerating at all: D+/D− may be swapped — check schematic vs PCB
| Bridge enumerates but no data | UART crossed between bridge and MCU | Probe bridge TXD pin with scope while host sends data — if data present but MCU sees nothing, swap BRIDGE_TX and BRIDGE_RX on MCU side |
| Hall sensors always read same value | Sensor orientation wrong, magnet polarity wrong, or sensor variant mismatch | Apply magnet to sensor face directly; rotate magnet to find correct polarity |

## Forward path to `Keuze finaal` design

Once the prototype is validated and you transition to the production design, expect these PCB-level changes:

1. **RAK11720 MHF4 → RF pinout variant:** add controlled-impedance traces from module RF pads to antenna feeds. Build keepouts. Add PCB trace antenna or wire antenna feed pads.
2. **3.3 V buck-boost RT6150B → RAA2361052GNP#HC5:** different DFN-10 pinout, board respin.
3. **Hall sensors DRV5032 ×2 → SL1613SH + SL1623SH:** SMD parts instead of THT, different footprints, board respin. Anti-tamper N-pole / S-pole arrangement.
4. **Antennas FPC → PCB trace + wire dipole:** changes board outline (need clear area for PCB IFA antenna) and adds wire antenna feed pads.
5. **Skip ePaper:** remove the 8-pin JST header and the SPI bus's ePaper branch.

Each of these is a separate audit + footprint check + schematic edit + layout iteration. Reusing the prototype board layout is not viable for the `Keuze finaal` design — plan a full PCB rev 2 cycle when you make the pivot.

## Documentation to keep

After the first board is built and validated, archive:
- The gerbers + drill files used for this fab order
- The KiCAD project files at the matching git tag
- The BOM as ordered (with substitutions documented)
- Photos of the assembled board (top + bottom, high-res)
- Bring-up notes: what worked first try, what needed rework, voltage measurements at key test points
- Any datasheet errata you discovered during bring-up

This documentation is what makes board rev 2 fast. Without it, you'll rediscover the same issues.

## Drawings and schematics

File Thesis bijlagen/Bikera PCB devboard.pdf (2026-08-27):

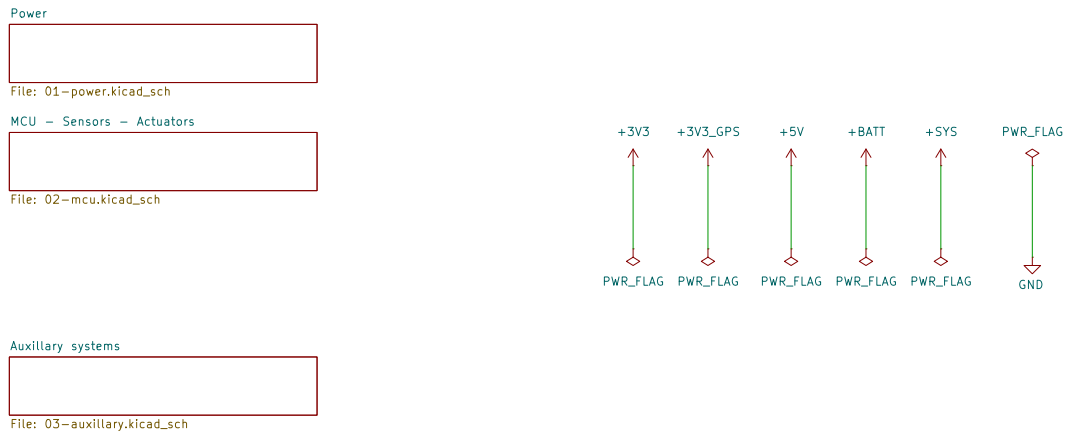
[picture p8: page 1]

MCU - Sensors - Actuators File: 02-mcu.kicad_sch

Sheet: /
File: Bikera PCB devboard.kicad_sch
Title:

Size: A4 | Rev:
KiCad E.D.A. 10.0.1 | Id: 1/4

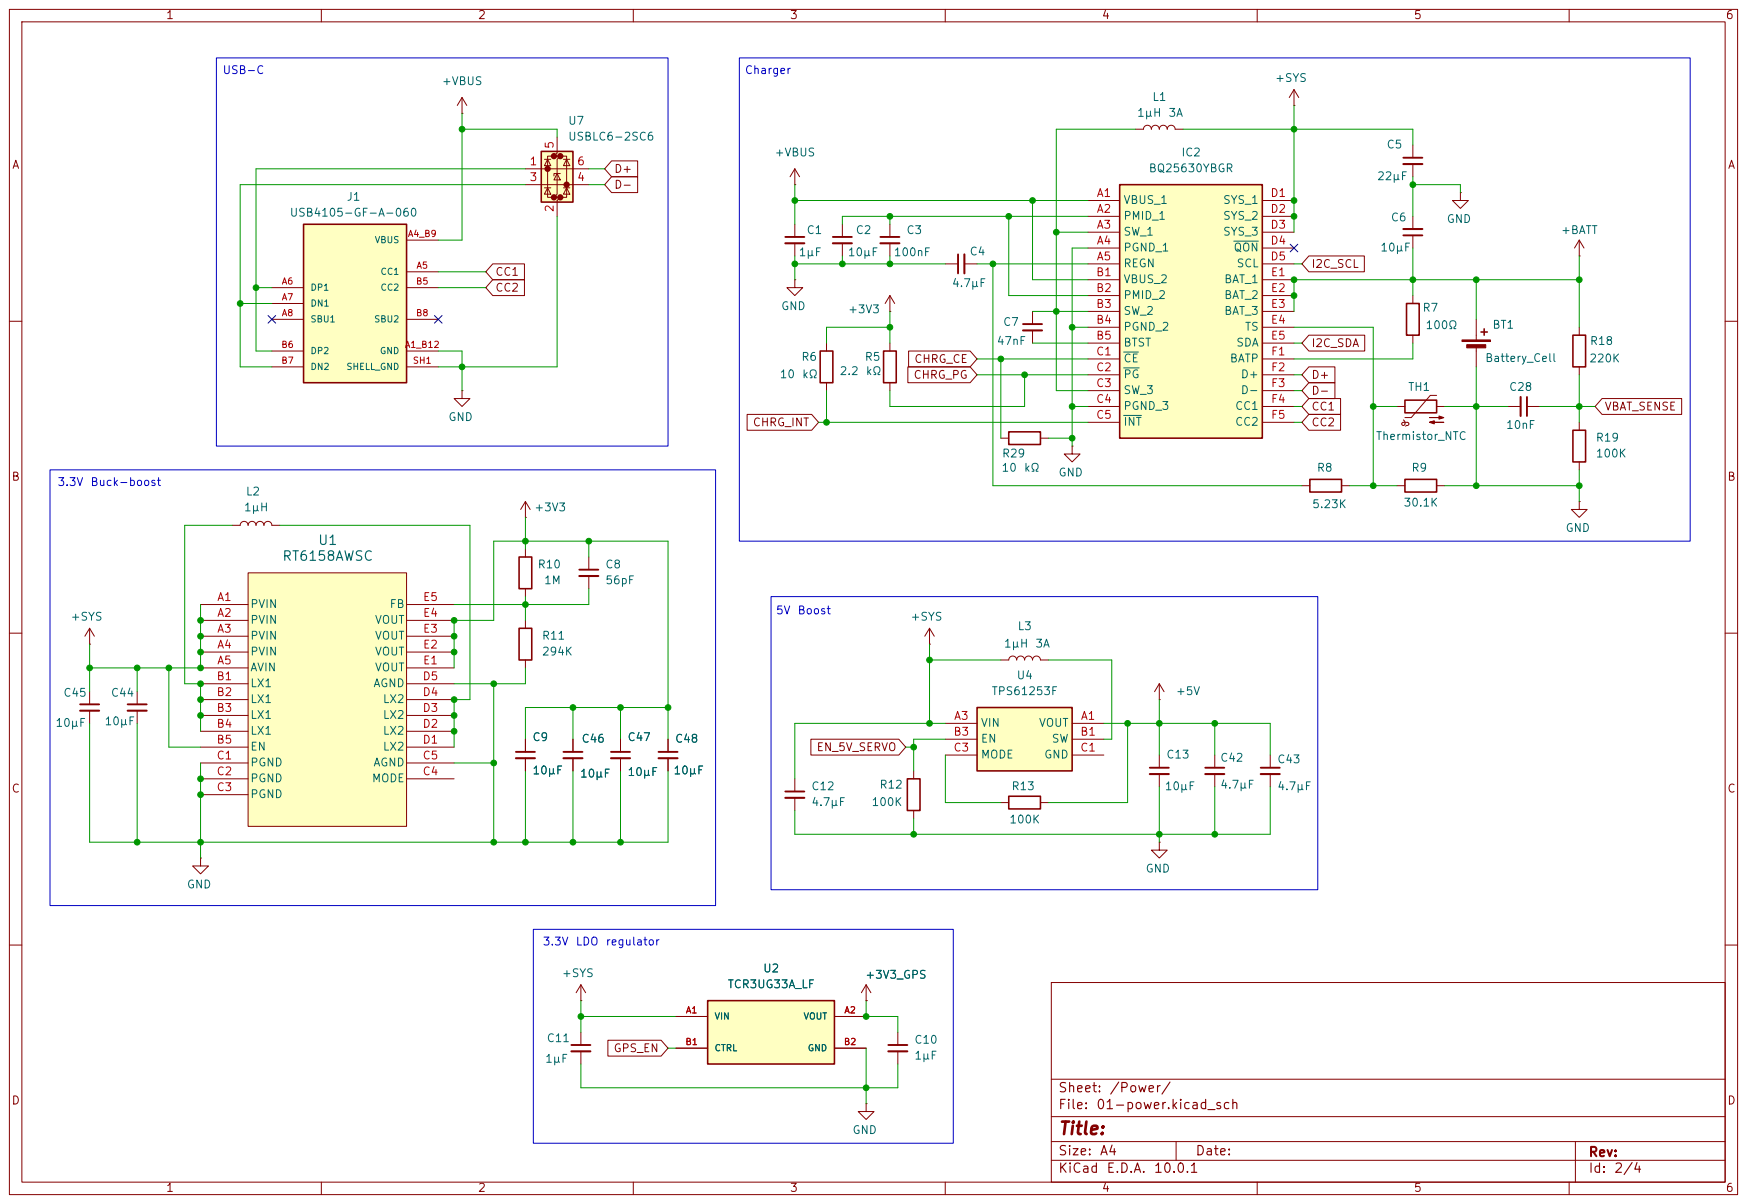
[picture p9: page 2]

SW_1 A3 PGND_1 A4 REGN A5

VBUS_2 B1 PMID_2 B2

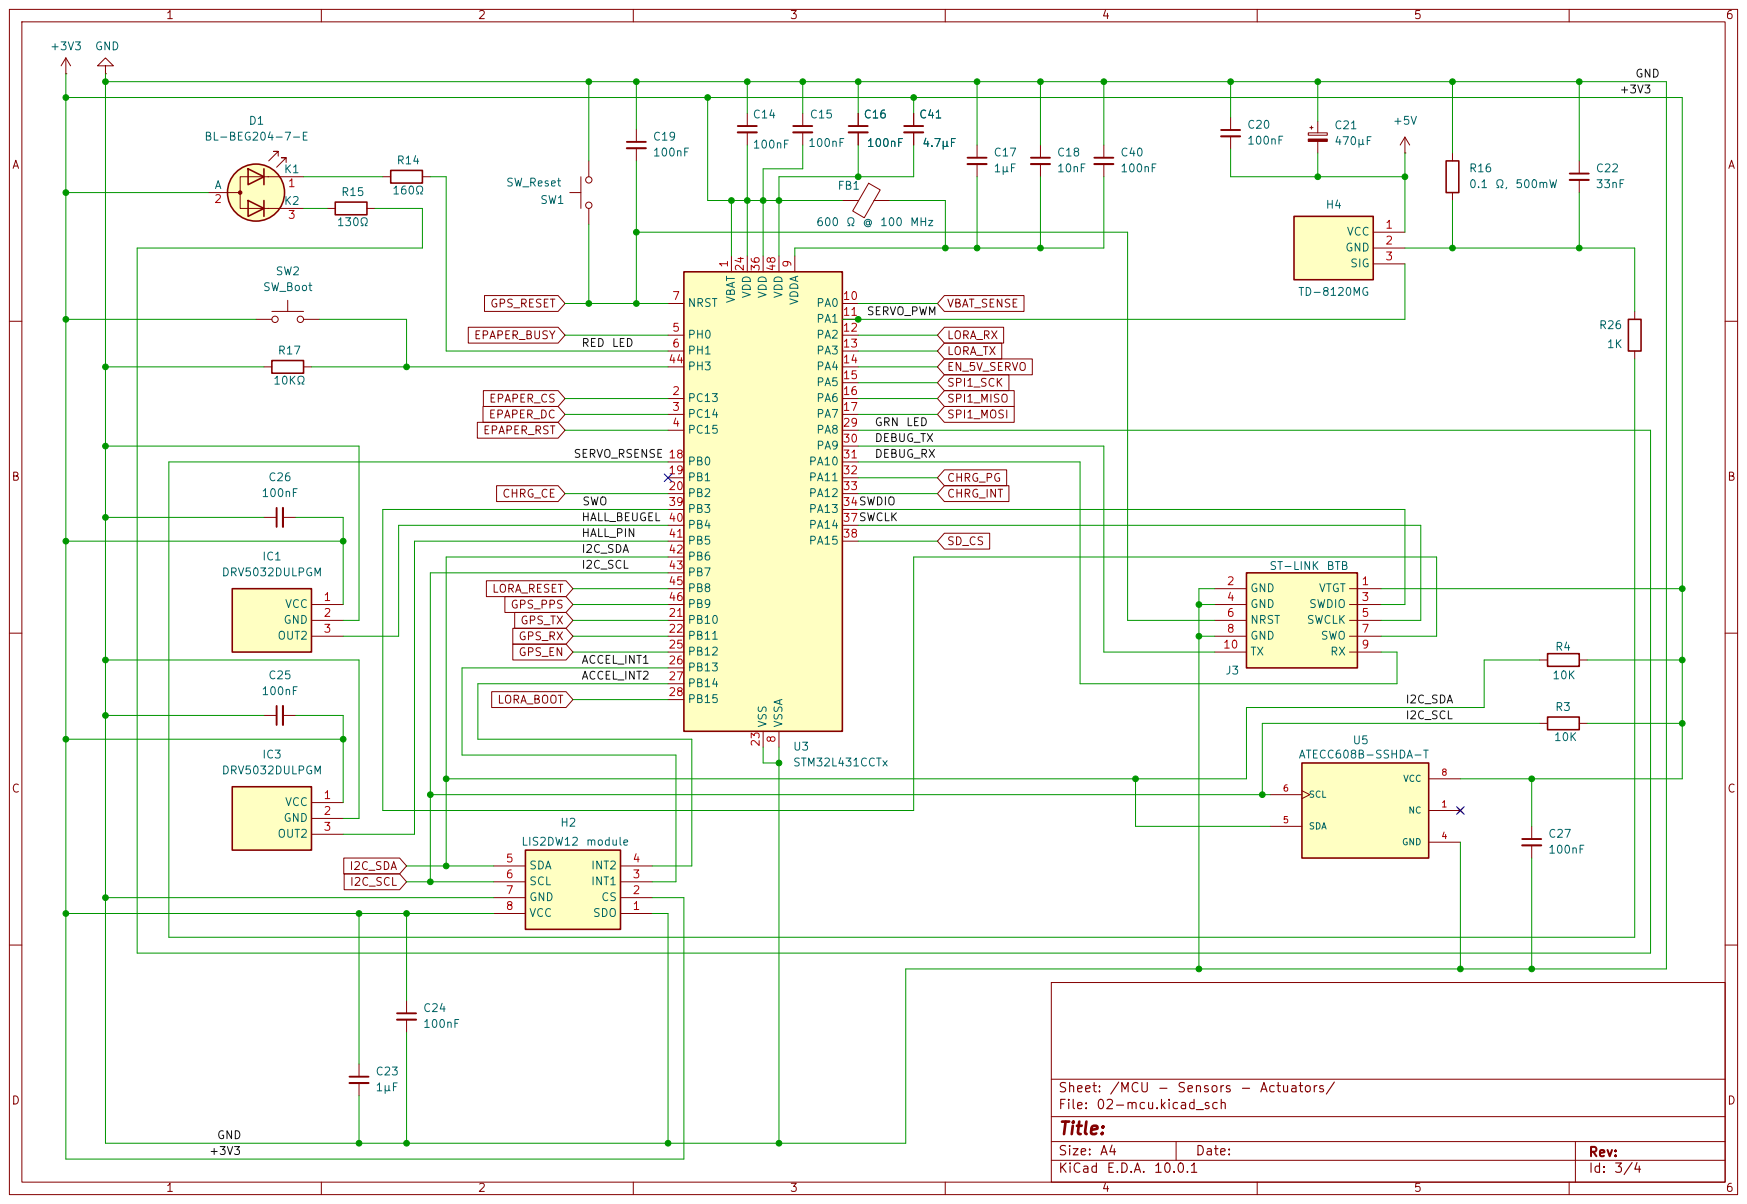
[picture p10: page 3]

C26 | SERVO_RSENSE HALL_BEUGEL SWO | SWDIO

SWCLK

IC3 DRV5032DULPGM

Sheet: /MCU - Sensors - Actuators/
File: 02-mcu.kicad_sch
Title:

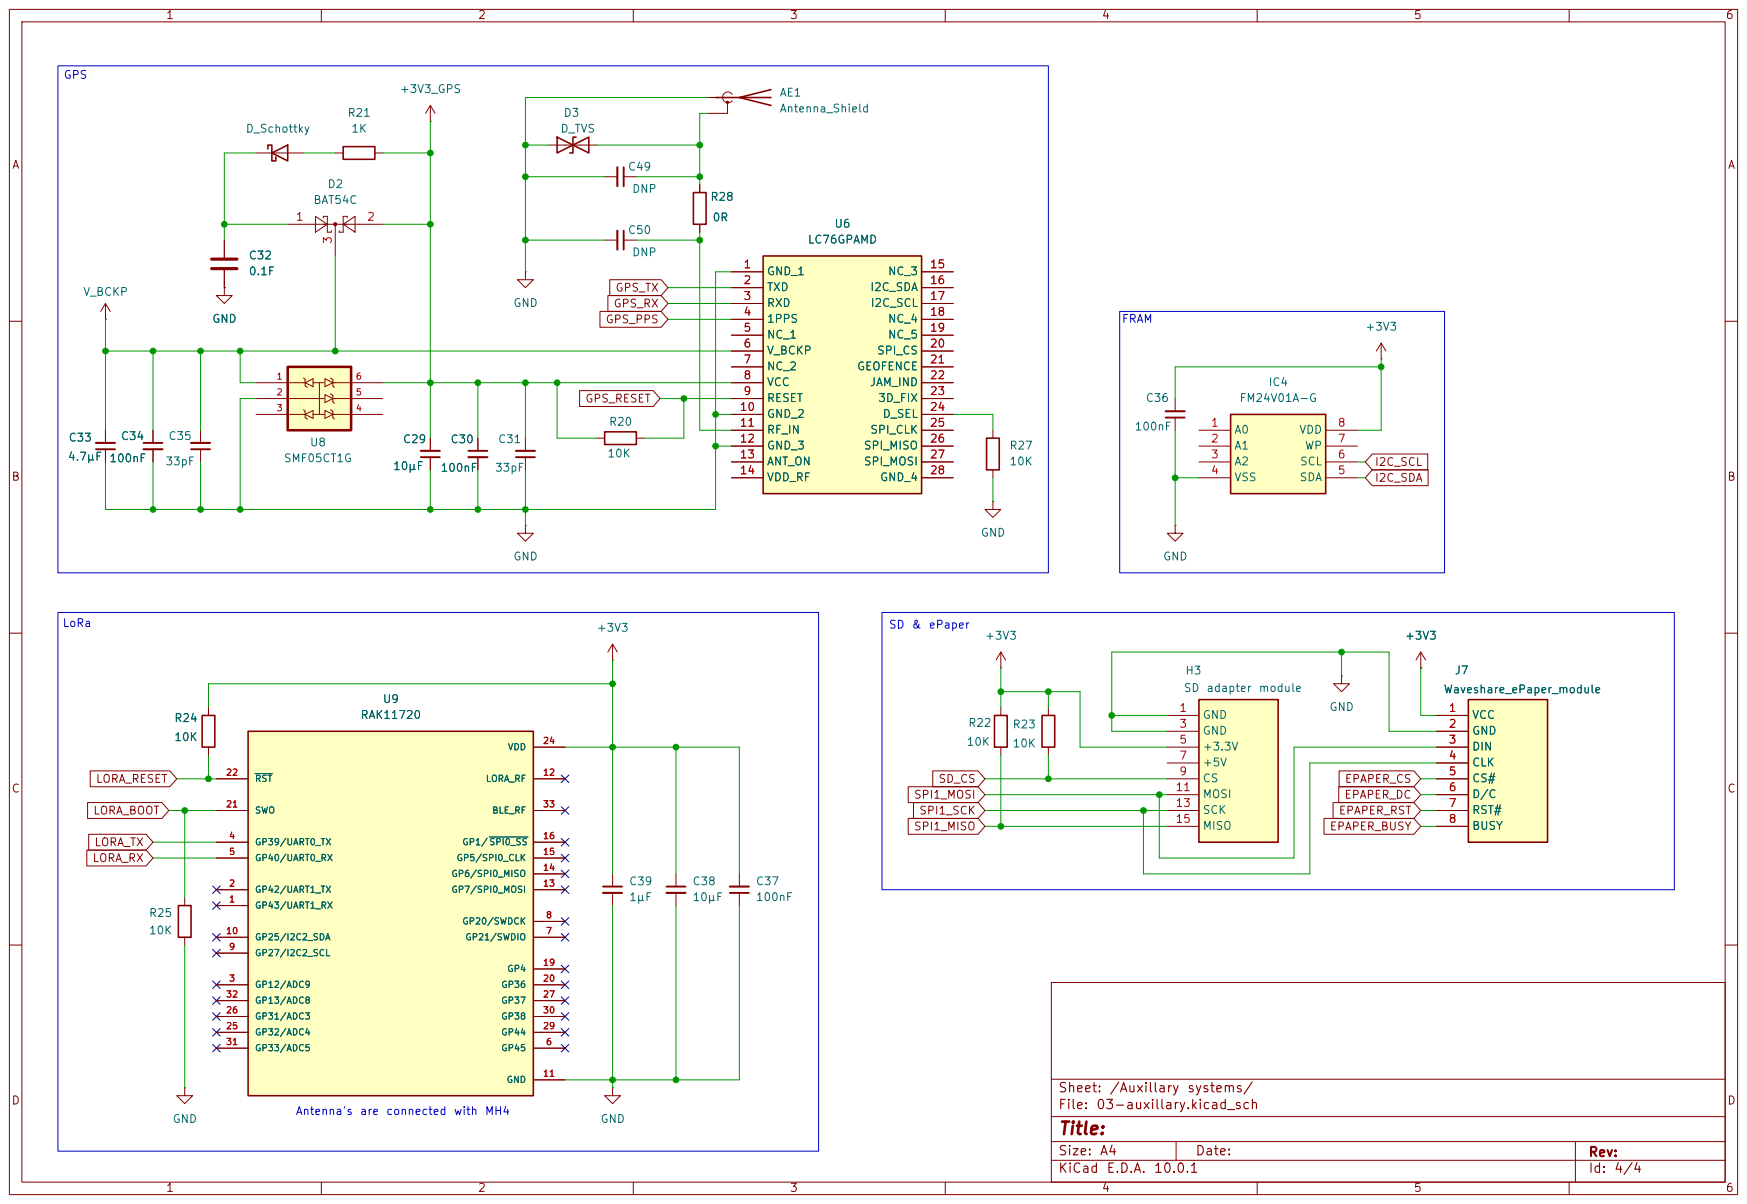
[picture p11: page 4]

SD & ePaper Antenna's are connected with MH4

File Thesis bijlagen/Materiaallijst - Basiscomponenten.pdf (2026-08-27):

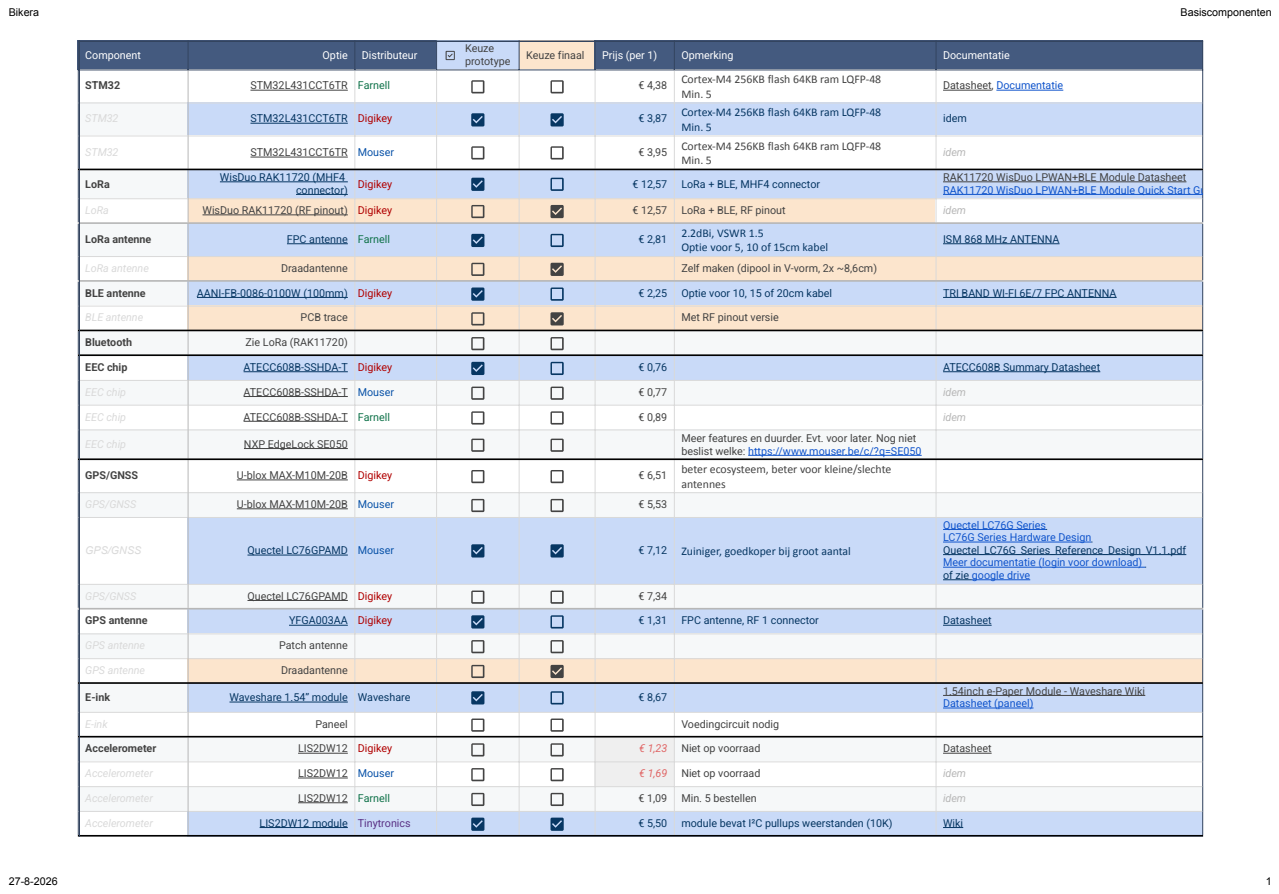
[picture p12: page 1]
Bikera; Basiscomponenten

Component | Optie | Distributeur | Keuze prototype | Keuze finaal | Prijs (per 1) | Opmerking | Documentatie

STM32 | STM32L431CCT6TR (https://be.farnell.com/stmicroelectronics/stm32l431cct6tr/mcu-32bit-80mhz-lqfp-48/dp/3365485RL) | Farnell | | | € 4,38 | Cortex-M4 256KB flash 64KB ram LQFP-48 Min. 5 | Datasheet, Documentatie

STM32 | STM32L431CCT6TR (https://www.digikey.be/nl/products/detail/stmicroelectronics/STM32L431CCT6TR/8257907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) | Digikey | | | € 3,87 | Cortex-M4 256KB flash 64KB ram LQFP-48 Min. 5 | idem

STM32 | STM32L431CCT6TR (https://www.mouser.be/ProductDetail/STMicroelectronics/STM32L431CCT6TR?qs=1mbolxNpo8fHpxV3RKOU3w%3D%3D) | Mouser | | | € 3,95 | Cortex-M4 256KB flash 64KB ram LQFP-48 Min. 5 | idem

LoRa | WisDuo RAK11720 (MHF4 connector) (https://www.digikey.be/nl/products/detail/rakwireless-technology-limited/RAK11720-8-SM-I/26861631) | Digikey | | | € 12,57 | LoRa + BLE, MHF4 connector | RAK11720 WisDuo LPWAN+BLE Module Datasheet

RAK11720 WisDuo LPWAN+BLE Module Quick Start Guide

LoRa | WisDuo RAK11720 (RF pinout) (https://www.digikey.be/nl/products/detail/rakwireless-technology-limited/RAK11720-8-SM-NI/26861635) | Digikey | | | € 12,57 | LoRa + BLE, RF pinout | idem

LoRa antenne | FPC antenne (https://be.farnell.com/te-connectivity/l000551-05/rf-antenna-863-to-870mhz-2-2dbi/dp/4457734) | Farnell | | | € 2,81 | 2.2dBi, VSWR 1.5 Optie voor 5, 10 of 15cm kabel | ISM 868 MHz ANTENNA (https://www.farnell.com/datasheets/4319155.pdf)

LoRa antenne | Draadantenne | | | | | Zelf maken (dipool in V-vorm, 2x ~8,6cm)

BLE antenne | AANI-FB-0086-0100W (100mm) (https://www.digikey.be/nl/products/detail/abracon-llc/AANI-FB-0086-0100W/25558929) | Digikey | | | € 2,25 | Optie voor 10, 15 of 20cm kabel | TRI BAND WI-FI 6E/7 FPC ANTENNA (https://abracon.com/datasheets/AANI-FB-0086.pdf)

BLE antenne | PCB trace | | | | | Met RF pinout versie

Bluetooth | Zie LoRa (RAK11720)

EEC chip | ATECC608B-SSHDA-T (https://www.digikey.be/nl/products/detail/microchip-technology/ATECC608B-SSHDA-T/13415162) | Digikey | | | € 0,76 | | ATECC608B Summary Datasheet (https://ww1.microchip.com/downloads/en/DeviceDoc/ATECC608B-CryptoAuthentication-Device-Summary-Data-Sheet-DS40002239A.pdf)

EEC chip | ATECC608B-SSHDA-T (https://www.mouser.be/ProductDetail/Microchip-Technology/ATECC608B-SSHDA-T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) | Mouser | | | € 0,77 | | idem

EEC chip | ATECC608B-SSHDA-T (https://be.farnell.com/microchip/atecc608a-sshda-t/cryptoauthentication-40-to-85deg/dp/2920872) | Farnell | | | € 0,89 | | idem

EEC chip | NXP EdgeLock SE050 (https://www.mouser.be/new/nxp-semiconductors/nxp-edgelock-se050/) | | | | | Meer features en duurder. Evt. voor later. Nog niet beslist welke: https://www.mouser.be/c/?q=SE050

GPS/GNSS | U-blox MAX-M10M-20B (https://www.digikey.be/nl/products/detail/u-blox/MAX-M10M-20B/28314774?s=N4IgTCBcDaILIEEAaBaOBGADHFZMCEQBdAXyA) | Digikey | | | € 6,51 | beter ecosysteem, beter voor kleine/slechte antennes

GPS/GNSS | U-blox MAX-M10M-20B (https://www.mouser.be/ProductDetail/u-blox/MAX-M10M-20B?qs=bpu3f%2FCR1jxLHPI3qGoNEA%3D%3D) | Mouser | | | € 5,53
GPS/GNSS | Quectel LC76GPAMD (https://www.mouser.be/ProductDetail/Quectel/LC76GPAMD?qs=vvQtp7zwQdMfDuCTmjRUww%3D%3D) | Mouser | | | € 7,12 | Zuiniger, goedkoper bij groot aantal | Quectel LC76G Series LC76G Series Hardware Design Quectel_LC76G_Series_Reference_Design_V1.1.pdf Meer documentatie (login voor download) of zie google drive

GPS/GNSS | Quectel LC76GPAMD (https://www.digikey.be/nl/products/detail/quectel/LC76GPAMD/21272484) | Digikey | | | € 7,34

GPS antenne | YFGA003AA (https://www.digikey.be/nl/products/detail/quectel/YFGA003AA/21273116) | Digikey | | | € 1,31 | FPC antenne, RF 1 connector | Datasheet (https://www.quectel.com/content/uploads/2024/04/Quectel_Antenna_YFGA003AA_Datasheet_V3.0.pdf?wpId=118983)

GPS antenne | Patch antenne

GPS antenne | Draadantenne
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

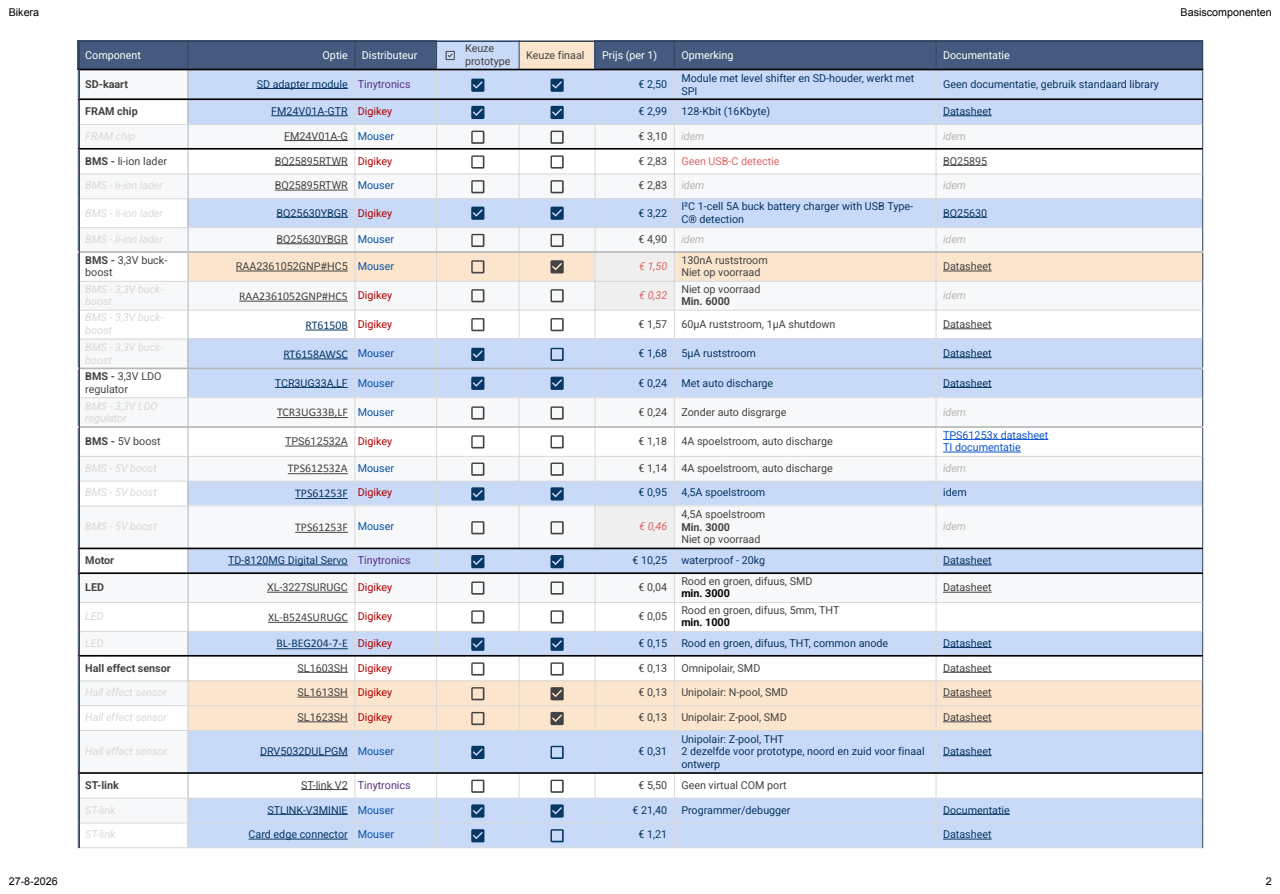
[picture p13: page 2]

prototype | Keuze finaal | Prijs (per 1) | Opmerking | Documentatie

SD-kaart | SD adapter module (https://www.tinytronics.nl/en/data-storage/modules/sd-card-adapter-module-3.3v-5v) | Tinytronics | | | € 2,50 | Module met level shifter en SD-houder, werkt met SPI | Geen documentatie, gebruik standaard library
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

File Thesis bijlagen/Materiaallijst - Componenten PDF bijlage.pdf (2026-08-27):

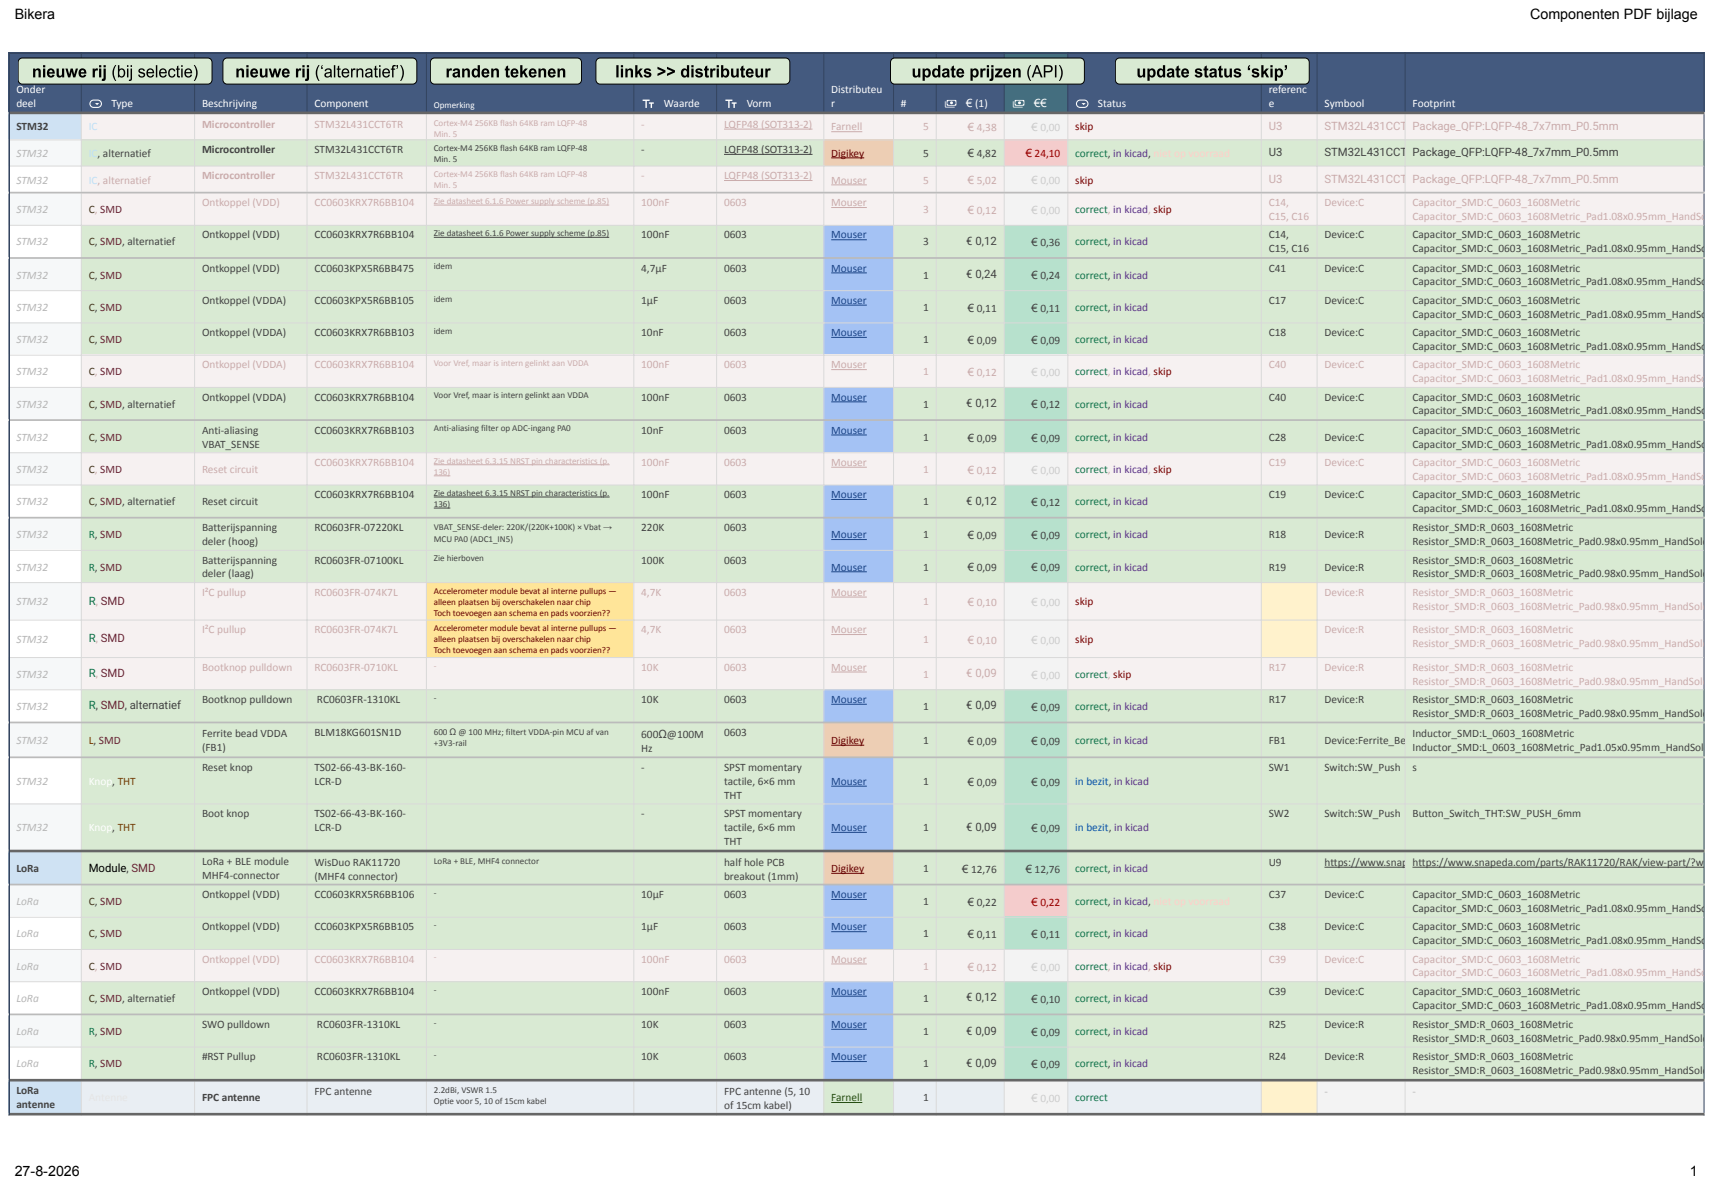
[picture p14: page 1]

Onder | | | | | | | Distributeu r | # | € (1) | €€ | Status | KiCad referenc e | Symbool | Footprint

STM32 | IC | Microcontroller | STM32L431CCT6TR | Cortex-M4 256KB flash 64KB ram LQFP-48 Min. 5 | - | LQFP48 (SOT313-2) (https://www.nxp.com/docs/en/package-information/SOT313-2.pdf) | Farnell (https://www.digikey.be/nl/products/detail/stmicroelectronics/STM32L431CCT6TR/8257907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) | 5 | € 4,38 | € 0,00 | skip | U3 | STM32L431CCTxPackage_QFP:LQFP-48_7x7mm_P0.5mm

STM32 | IC, alternatief | Microcontroller | STM32L431CCT6TR | Cortex-M4 256KB flash 64KB ram LQFP-48 Min. 5 | - | LQFP48 (SOT313-2) (https://www.nxp.com/docs/en/package-information/SOT313-2.pdf) | Digikey (https://www.digikey.be/nl/products/detail/stmicroelectronics/STM32L431CCT6TR/8257907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) | 5 | € 4,82 | € 24,10 | correct, in kicad, niet op voorraad | U3 | STM32L431CCTxPackage_QFP:LQFP-48_7x7mm_P0.5mm

STM32 | IC, alternatief | Microcontroller | STM32L431CCT6TR | Cortex-M4 256KB flash 64KB ram LQFP-48 Min. 5 | - | LQFP48 (SOT313-2) (https://www.nxp.com/docs/en/package-information/SOT313-2.pdf) | Mouser (https://www.mouser.be/ProductDetail/STMicroelectronics/STM32L431CCT6TR?qs=1mbolxNpo8fHpxV3RKOU3w%3D%3D) | 5 | € 5,02 | € 0,00 | skip | U3 | STM32L431CCTxPackage_QFP:LQFP-48_7x7mm_P0.5mm

STM32 | C, SMD | Ontkoppel (VDD) | CC0603KRX7R6BB104 | Zie datasheet 6.1.6 Power supply scheme (p.85) (https://www.st.com/content/ccc/resource/technical/document/datasheet/group3/83/b3/60/f6/b1/cc/47/7e/DM00257211/files/DM00257211.pdf/jcr:content/translations/e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) | 100nF | 0603 | Mouser (https://www.mouser.be/ProductDetail/YAGEO/CC0603KRX7R6BB104?qs=DzaeBbIlxds1tY2vaxRCyQ%3D%3D) | 3 | € 0,12 | € 0,00 | correct, in kicad, skip | C14, C15, C16 | Device:C | Capacitor_SMD:C_0603_1608Metric

STM32 | C, SMD, alternatief | Ontkoppel (VDD) | CC0603KRX7R6BB104 | Zie datasheet 6.1.6 Power supply scheme (p.85) (https://www.st.com/content/ccc/resource/technical/document/datasheet/group3/83/b3/60/f6/b1/cc/47/7e/DM00257211/files/DM00257211.pdf/jcr:content/translations/e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) | 100nF | 0603 | Mouser (https://www.mouser.be/ProductDetail/KEMET/C0603C104K8RACTU?qs=7q2aiX3GdlhV1RoC2Ruw8Q%3D%3D) | 3 | € 0,12 | € 0,36 | correct, in kicad | C14, C15, C16 | Device:C | Capacitor_SMD:C_0603_1608Metric

STM32 | C, SMD | Ontkoppel (VDD) | CC0603KPX5R6BB475 | idem | 4,7µF | 0603 | Mouser (https://www.mouser.be/ProductDetail/YAGEO/CC0603KPX5R6BB475?qs=mzRxyRlhVdtG7wG2BIZZbA%3D%3D) | 1 | € 0,24 | € 0,24 | correct, in kicad | C41 | Device:C | Capacitor_SMD:C_0603_1608Metric

STM32 | C, SMD | Ontkoppel (VDDA) | CC0603KPX5R6BB105 | idem | 1µF | 0603 | Mouser (https://www.mouser.be/ProductDetail/YAGEO/CC0603KPX5R6BB105?qs=57cj7OiSijl3rhe8DpTm1Q%3D%3D) | 1 | € 0,11 | € 0,11 | correct, in kicad | C17 | Device:C | Capacitor_SMD:C_0603_1608Metric

STM32 | C, SMD | Ontkoppel (VDDA) | CC0603KRX7R6BB103 | idem | 10nF | 0603 | Mouser (https://www.mouser.be/ProductDetail/YAGEO/CC0603KRX7R6BB103?qs=Jp%252B3Pqv7Js0lWCO1g7PSqg%3D%3D) | 1 | € 0,09 | € 0,09 | correct, in kicad | C18 | Device:C | Capacitor_SMD:C_0603_1608Metric

STM32 | C, SMD | Ontkoppel (VDDA) | CC0603KRX7R6BB104 | Voor Vref, maar is intern gelinkt aan VDDA | 100nF | 0603 | Mouser (https://www.mouser.be/ProductDetail/YAGEO/CC0603KRX7R6BB104?qs=DzaeBbIlxds1tY2vaxRCyQ%3D%3D) | 1 | € 0,12 | € 0,00 | correct, in kicad, skip | C40 | Device:C | Capacitor_SMD:C_0603_1608Metric

STM32 | C, SMD, alternatief | Ontkoppel (VDDA) | CC0603KRX7R6BB104 | Voor Vref, maar is intern gelinkt aan VDDA | 100nF | 0603 | Mouser (https://www.mouser.be/ProductDetail/KEMET/C0603C104K8RACTU?qs=7q2aiX3GdlhV1RoC2Ruw8Q%3D%3D) | 1 | € 0,12 | € 0,12 | correct, in kicad | C40 | Device:C | Capacitor_SMD:C_0603_1608Metric

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

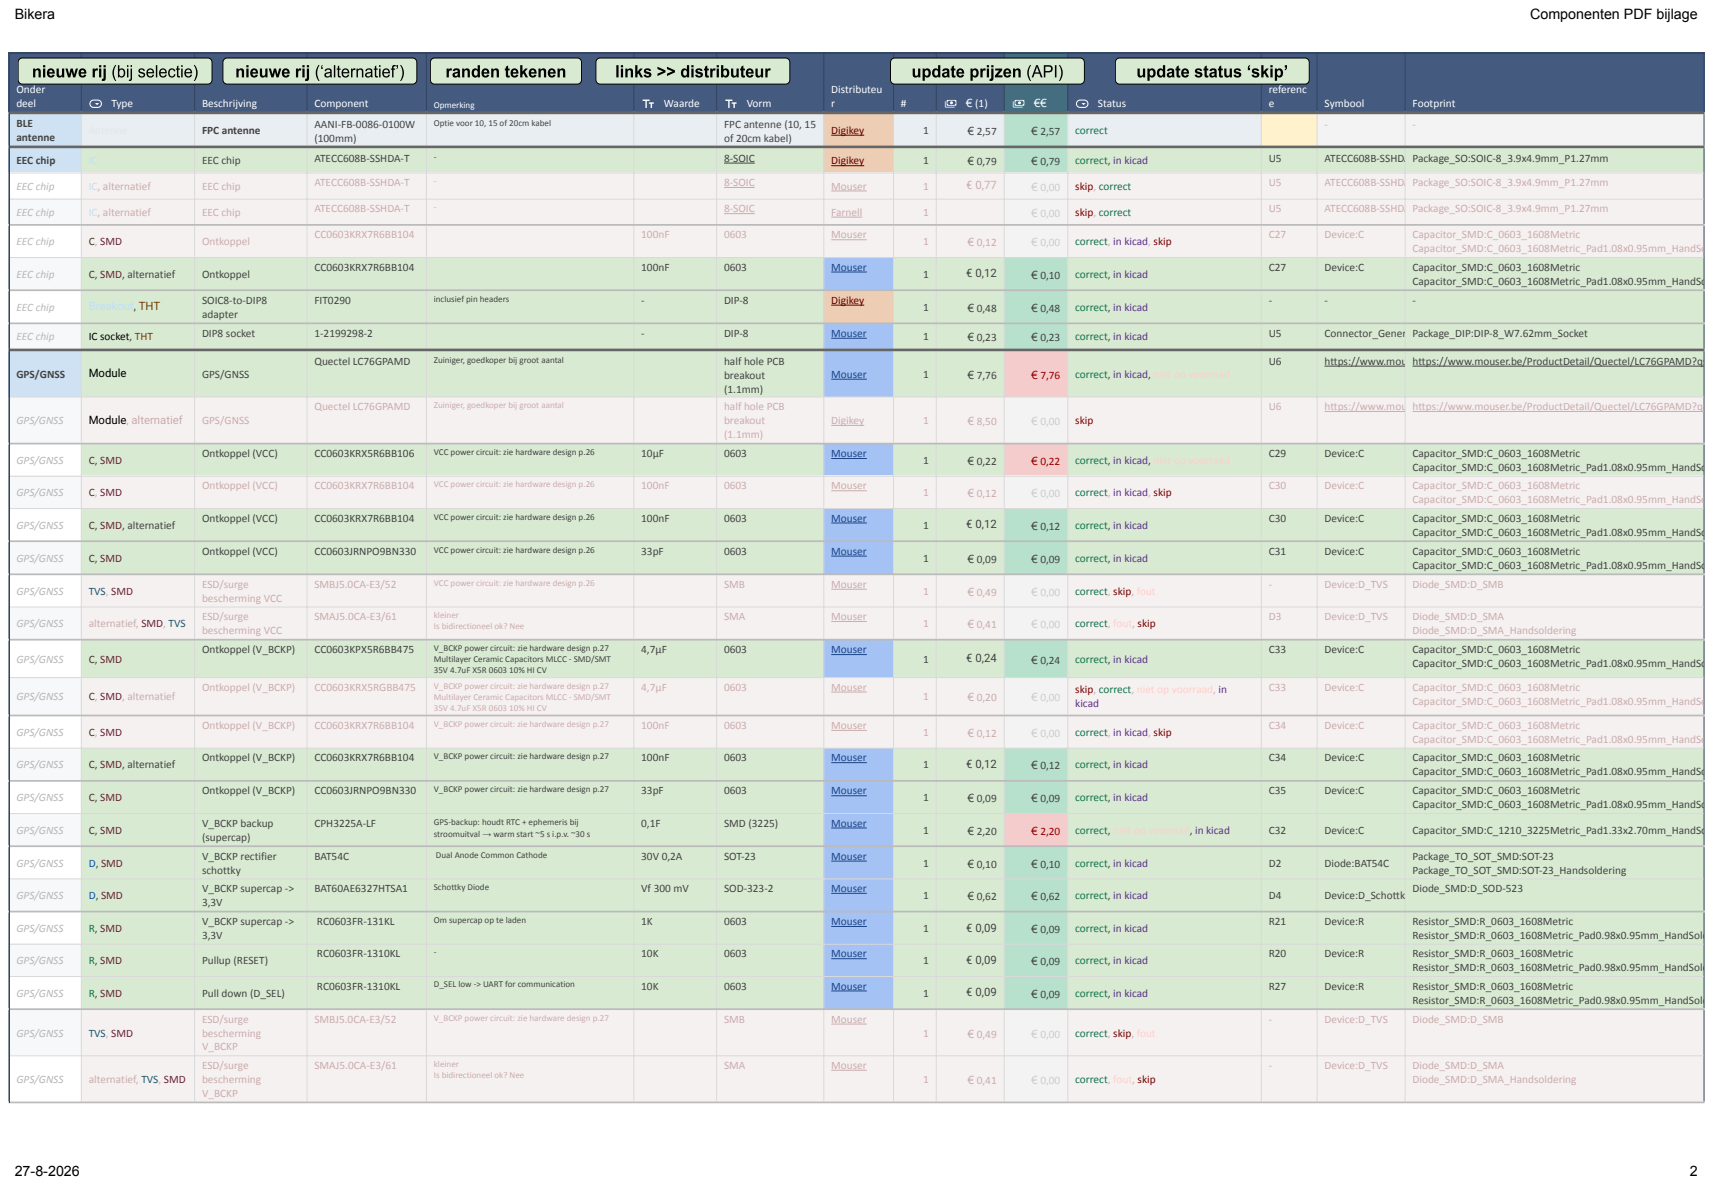
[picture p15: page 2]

Onder | | | | | | | Distributeu r | # | € (1) | €€ | Status | referenc e | Symbool | Footprint

BLE antenne | Antenne | FPC antenne | AANI-FB-0086-0100W (100mm) | Optie voor 10, 15 of 20cm kabel | | FPC antenne (10, 15 of 20cm kabel) | Digikey (https://www.digikey.be/nl/products/detail/abracon-llc/AANI-FB-0086-0100W/25558929) | 1 | € 2,57 | € 2,57 | correct | | - | -
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

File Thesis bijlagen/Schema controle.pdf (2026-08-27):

# Schema controle MCU page

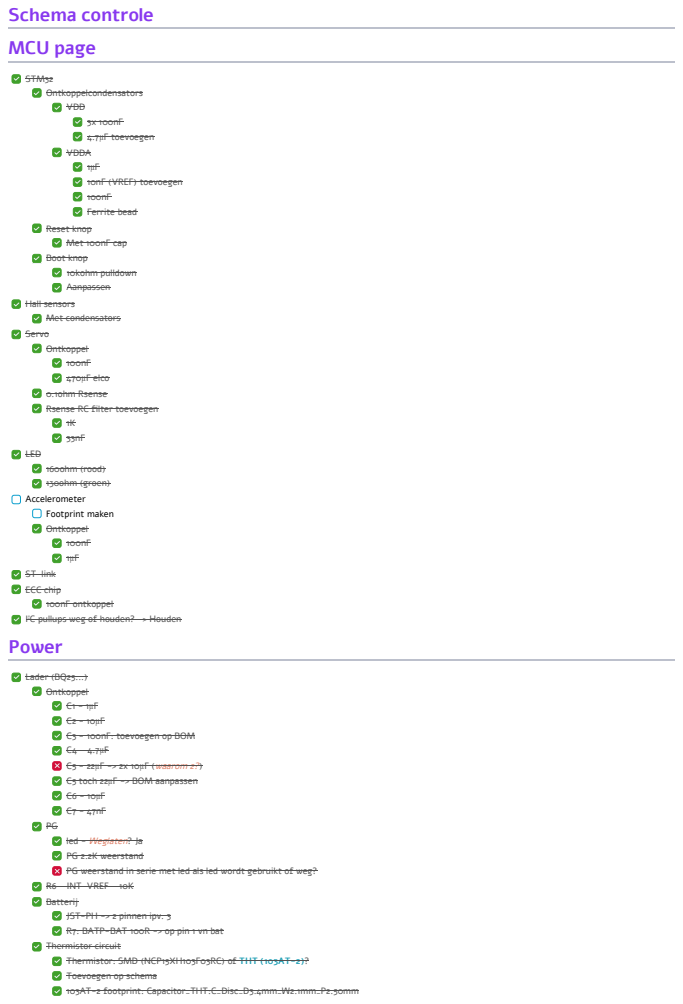
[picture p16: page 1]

ST-link
ECC chip
100nF ontkoppel
I²C pullups weg of houden? -> Houden
Power

Lader (BQ25...)
Ontkoppel
C3 - 100nF: toevoegen op BOM
C5 - 22µF -> 2x 10µF (waarom 2?)
C5 toch 22µF -> BOM aanpassen
led - Weglaten? Ja
PG 2.2K weerstand
PG weerstand in serie met led als led wordt gebruikt of weg?
R6 - INT-VREF - 10K
Batterij
JST-PH -> 2 pinnen ipv. 3
R7: BATP-BAT 100R -> op pin 1 vn bat
Thermistor circuit
Thermistor: SMD (NCP15XH103F03RC) of THT (103AT-2)?
Toevoegen op schema
103AT-2 footprint: Capacitor_THT:C_Disc_D3.4mm_W2.1mm_P2.50mm

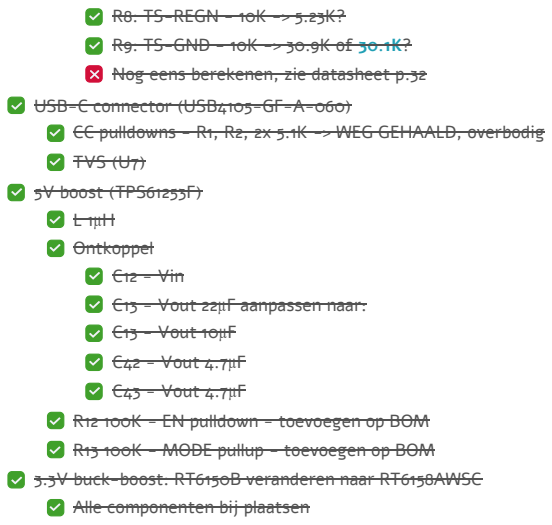
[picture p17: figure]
R8: TS-REGN - 10K -> 5.23K? R9: TS-GND - 10K -> 30.9K of 30.1K? Nog eens berekenen, zie datasheet p.32 USB-C connector (USB4105-GF-A-060); TVS (U7) 5V boost (TPS61253F) L 1µH Ontkoppel C12 - Vin C13 - Vout 22µF aanpassen naar: C13 - Vout 10µF C42 - Vout 4.7µF C43 - Vout 4.7µF; Alle componenten bij plaatsen

# Auxilery systems

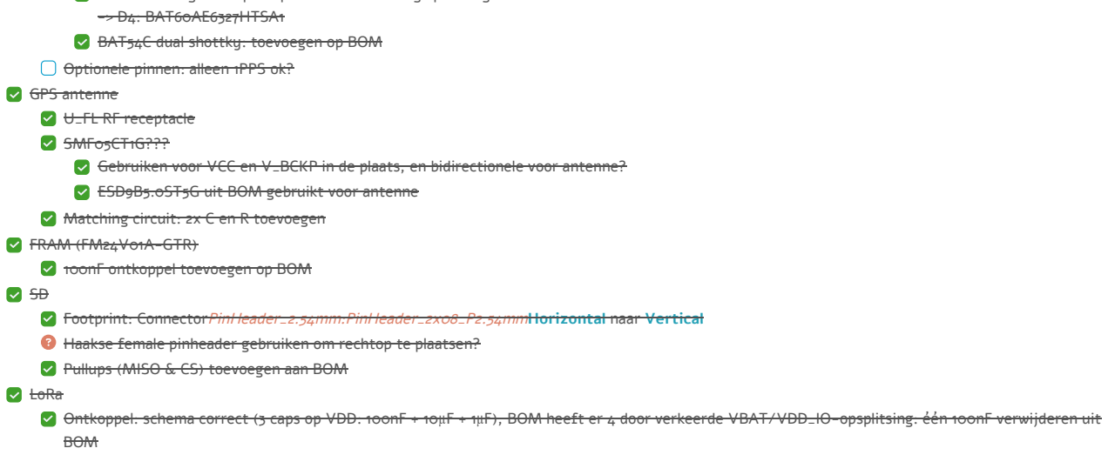
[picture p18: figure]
-> D4: BAT60AE6327HTSA1 BAT54C dual shottky: toevoegen op BOM Optionele pinnen: alleen 1PPS ok? GPS antenne U_FL RF receptacle SMF05CT1G???; Matching circuit: 2x C en R toevoegen FRAM (FM24V01A-GTR) 100nF ontkoppel toevoegen op BOM; Footprint: ConnectorPinHeader_2.54mm:PinHeader_2x08_P2.54mmHorizontal naar Vertical; Pullups (MISO & CS) toevoegen aan BOM; LoRa; BOM

# Laatste controle bij afwerken van thesis

CC pulldowns - R1, R2, 2x 5.1K -> WEG GEHAALD, overbodig

R12 100K - EN pulldown - toevoegen op BOM
R13 100K - MODE pullup - toevoegen op BOM 3.3V buck-boost: RT6150B veranderen naar RT6158AWSC

GPS
Symbool aanpassen:
Pin 5: AP_REQ -> reserved/NC
Pin 13: LNA_EN -> ANT_ON
Pin 14 VCC_RF -> VDD_RF
Pin 24: NC_5 -> D_SEL & pulldown weerstand toevoegen TVS (VCC & V_BCKP) toevoegen
Is bidirectioneel OK?
Ontkoppel
VCC: 10µF, 100nF, 33pF
V_BCKP: 4.7µF, 100nF, 33pF
0.1F Supercap
R - 1K - naar 3.3V
Diode toevoegen? Supercap zou misschien leeglopen langs R

Gebruiken voor VCC en V_BCKP in de plaats, en bidirectionele voor antenne? ESD9B5.0ST5G uit BOM gebruikt voor antenne

Haakse female pinheader gebruiken om rechtop te plaatsen?

Ontkoppel: schema correct (3 caps op VDD: 100nF + 10µF + 1µF), BOM heeft er 4 door verkeerde VBAT/VDD_IO-opsplitsing: één 100nF verwijderen uit

10kΩ pulldown pin 21 (LORA_BOOT) toevoegen aan BOM (zit al in schema)
10kΩ pullup pin 22 (NRESET) toevoegen aan BOM (zit al in schema)

USB-C 5.1K pulldowns zijn overbodig -> weg
USB-C D+ en D- waren niet verbonden met BQ25630 -> labels toegevoegd BQ25630 CE-pin 10K pull-down toegevoegd
GPS: I²C i.p.v. UART & D_SEL naar 3.3V met pullup

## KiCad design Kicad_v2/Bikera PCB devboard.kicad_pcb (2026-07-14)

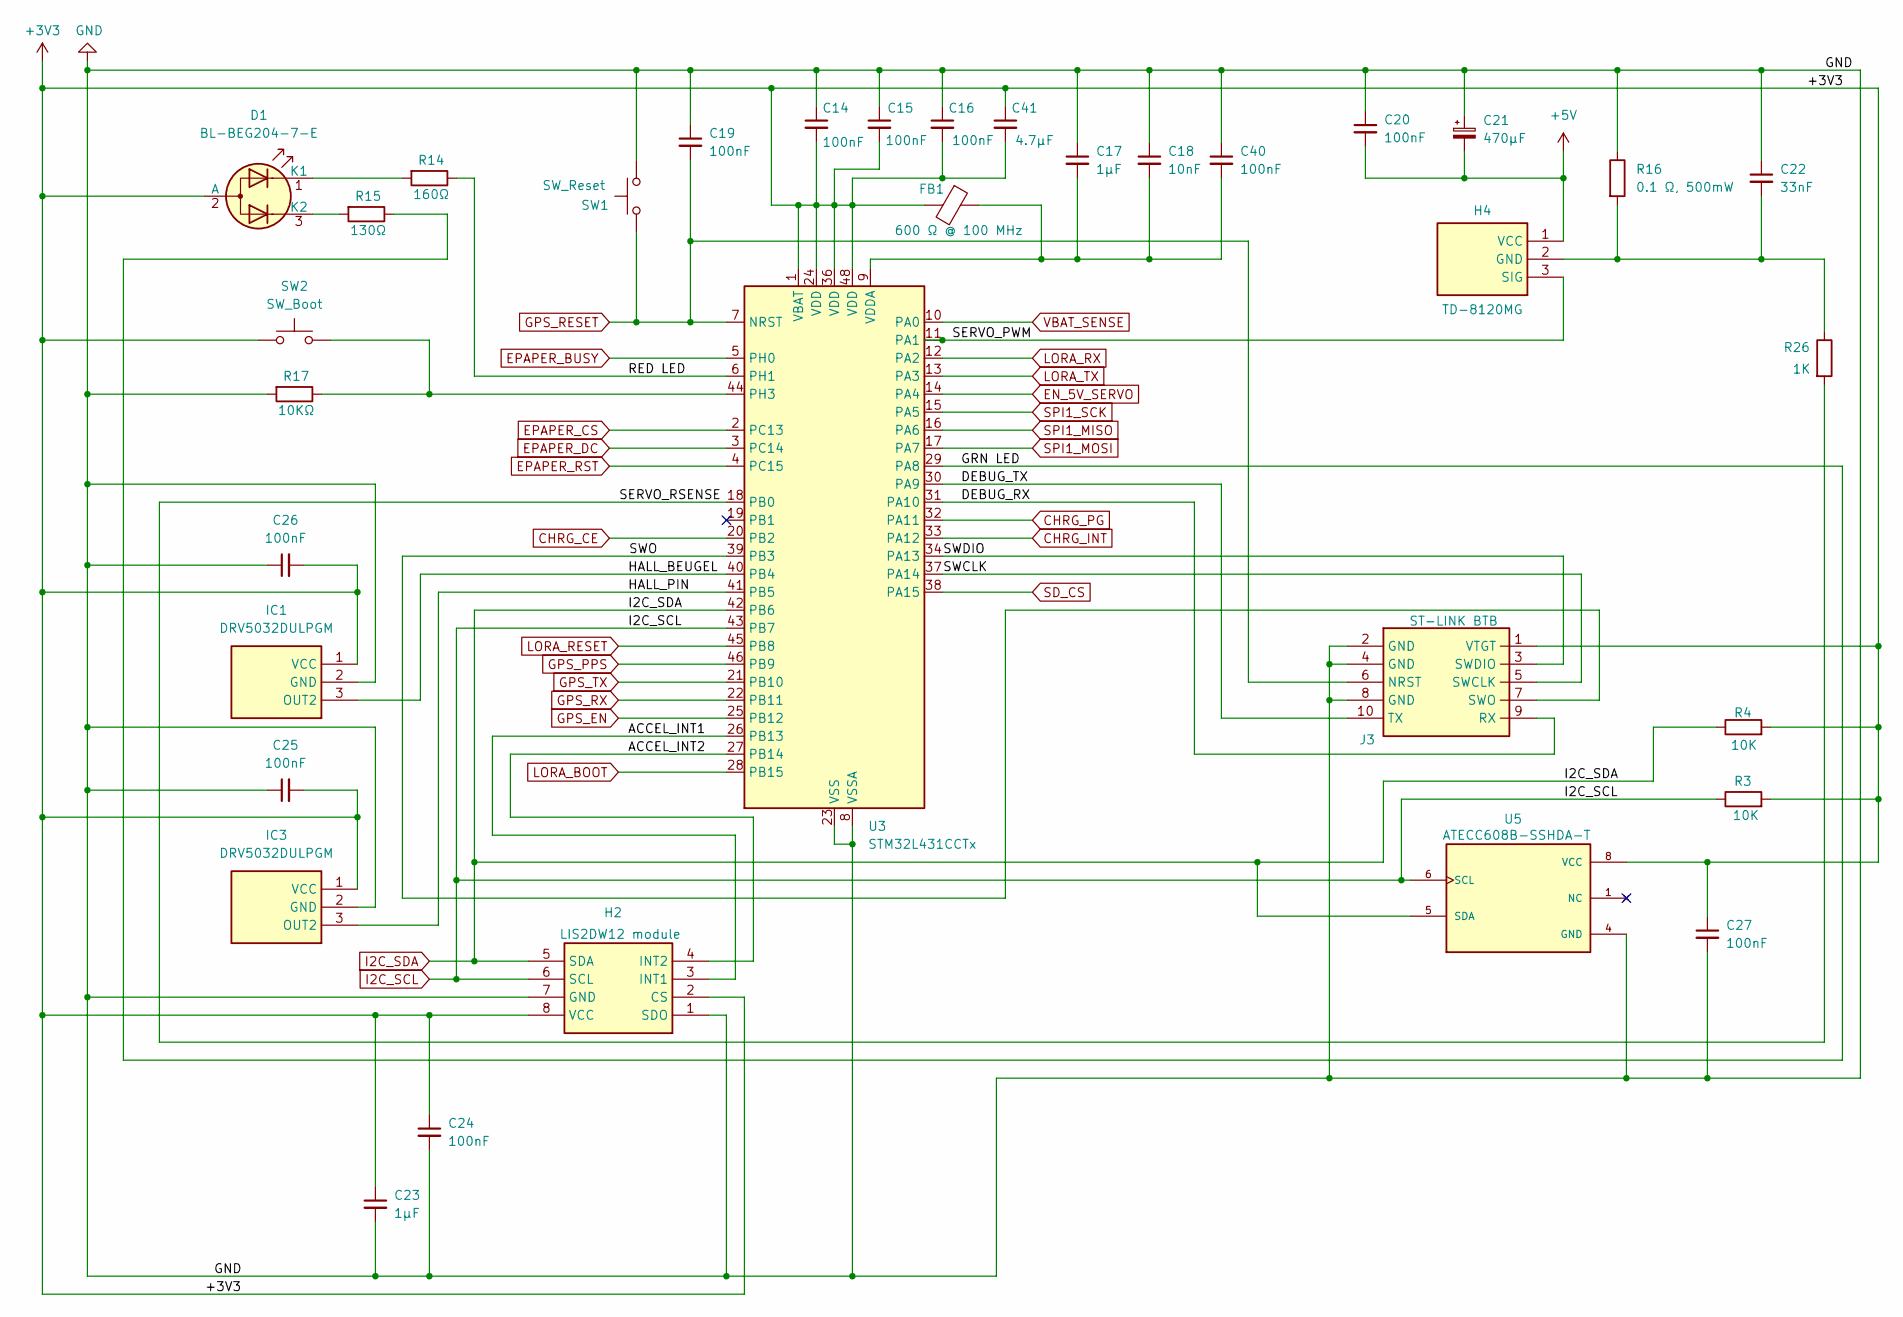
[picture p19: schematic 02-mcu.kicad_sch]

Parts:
C14, C15, C16, C19, C20, C24, C25, C26, C27, C40: 100nF; C_0603_1608Metric_Pad1.08x0.95mm_HandSolder
C17, C23: 1µF; C_0603_1608Metric_Pad1.08x0.95mm_HandSolder
C18: 10nF; C_0603_1608Metric_Pad1.08x0.95mm_HandSolder
C21: 470µF; CP_Radial_D8.0mm_P3.50mm
C22: 33nF; C_0603_1608Metric_Pad1.08x0.95mm_HandSolder
C41: 4.7µF; C_0603_1608Metric_Pad1.08x0.95mm_HandSolder
D1: BL-BEG204-7-E; LED_D5.0mm-3_Horizontal_O3.81mm_Z3.0mm
FB1: 600 Ω @ 100 MHz; L_0603_1608Metric_Pad1.05x0.95mm_HandSolder
H2: LIS2DW12 module; Mouser Part Number 727-FM24V01A-G
H4: TD-8120MG; JST_PH_B3B-PH-K_1x03_P2.00mm_Vertical; Mouser Part Number 595-DRV5032DULPGM
IC1, IC3: DRV5032DULPGM; Mouser Part Number 595-DRV5032DULPGM
J3: ST-LINK BTB; 009159010603906; Mouser Part Number 581-009159010603906
R3, R4: 10K; R_0603_1608Metric_Pad0.98x0.95mm_HandSolder
R14: 160Ω; R_0603_1608Metric_Pad0.98x0.95mm_HandSolder
R15: 130Ω; R_0603_1608Metric_Pad0.98x0.95mm_HandSolder
R16: 0.1 Ω, 500mW; R_1206_3216Metric_Pad1.30x1.75mm_HandSolder
R17: 10KΩ; R_0603_1608Metric_Pad0.98x0.95mm_HandSolder
R26: 1K; R_0603_1608Metric_Pad0.98x0.95mm_HandSolder
SW1: SW_Reset; SW_PUSH_6mm
SW2: SW_Boot; SW_PUSH_6mm
U3: STM32L431CCTx; LQFP-48_7x7mm_P0.5mm
U5: ATECC608B-SSHDA-T; DIP-8_W7.62mm_Socket; PARTREV B

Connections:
+3V3: C14.2, C15.2, C16.2, C23.1, C24.1, C25.2, C26.2, C27.1, C41.1, C41.2, D1.2 (A), FB1.2, H2.2 (CS), H2.8 (VCC), IC1.1 (VCC), IC3.1 (VCC), J3.1 (VTGT), R3.2, R4.2, SW2.1, U3.1 (VBAT), U3.24 (VDD), U3.36 (VDD), U3.48 (VDD), U5.8 (VCC); also elsewhere on the board
/MCU - Sensors - Actuators/ACCEL_INT1: H2.3 (INT1), U3.26 (PB13)
/MCU - Sensors - Actuators/ACCEL_INT2: H2.4 (INT2), U3.27 (PB14)
/MCU - Sensors - Actuators/DEBUG_RX: J3.9 (RX), U3.31 (PA10)
/MCU - Sensors - Actuators/DEBUG_TX: J3.10 (TX), U3.30 (PA9)
/MCU - Sensors - Actuators/GRN LED: R15.1, U3.29 (PA8)
/MCU - Sensors - Actuators/HALL_BEUGEL: IC1.3 (OUT2), U3.40 (PB4)
/MCU - Sensors - Actuators/HALL_PIN: IC3.3 (OUT2), U3.41 (PB5)
/MCU - Sensors - Actuators/RED LED: R14.1, U3.6 (PH1)
/MCU - Sensors - Actuators/SERVO_PWM: H4.3 (SIG), U3.11 (PA1)
/MCU - Sensors - Actuators/SERVO_RSENSE: R26.2, U3.18 (PB0)
/MCU - Sensors - Actuators/SWCLK: J3.5 (SWCLK), U3.37 (PA14)
/MCU - Sensors - Actuators/SWDIO: J3.3 (SWDIO), U3.34 (PA13)
/MCU - Sensors - Actuators/SWO: J3.7 (SWO), U3.39 (PB3)
CHRG_CE: U3.20 (PB2); also elsewhere on the board
CHRG_INT: U3.33 (PA12); also elsewhere on the board
CHRG_PG: U3.32 (PA11); also elsewhere on the board
EN_5V_SERVO: U3.14 (PA4); also elsewhere on the board
EPAPER_BUSY: U3.5 (PH0); also elsewhere on the board
EPAPER_CS: U3.2 (PC13); also elsewhere on the board
EPAPER_DC: U3.3 (PC14); also elsewhere on the board
EPAPER_RST: U3.4 (PC15); also elsewhere on the board
GND: C14.1, C15.1, C16.1, C17.1, C18.1, C19.1, C20.1, C21.1, C22.1, C23.2, C24.2, C25.1, C26.1, C27.2, C40.1, H2.1 (SDO), H2.7 (GND), IC1.2 (GND), IC3.2 (GND), J3.2 (GND), J3.4 (GND), J3.8 (GND), R16.1, R17.2, SW1.2, U3.8 (VSSA), U3.23 (VSS), U3.35 (VSS), U3.47 (VSS), U5.4 (GND); also elsewhere on the board
GPS_EN: U3.25 (PB12); also elsewhere on the board
GPS_PPS: U3.46 (PB9); also elsewhere on the board
GPS_RESET: C19.2, J3.6 (NRST), SW1.1, U3.7 (NRST); also elsewhere on the board
GPS_RX: U3.22 (PB11); also elsewhere on the board
GPS_TX: U3.21 (PB10); also elsewhere on the board
I2C_SCL: H2.6 (SCL), R3.1, U3.43 (PB7), U5.6 (SCL); also elsewhere on the board
I2C_SDA: H2.5 (SDA), R4.1, U3.42 (PB6), U5.5 (SDA); also elsewhere on the board
LORA_BOOT: U3.28 (PB15); also elsewhere on the board
LORA_RESET: U3.45 (PB8); also elsewhere on the board
LORA_RX: U3.12 (PA2); also elsewhere on the board
LORA_TX: U3.13 (PA3); also elsewhere on the board
unnamed: D1.1 (K1), R14.2
unnamed: D1.3 (K2), R15.2
unnamed: C22.2, H4.2 (GND), R16.2, R26.1
unnamed: R17.1, SW2.2, U3.44 (PH3)
unnamed: C17.2, C18.2, C40.2, FB1.1, U3.9 (VDDA)
SD_CS: U3.38 (PA15); also elsewhere on the board
SPI1_MISO: U3.16 (PA6); also elsewhere on the board
SPI1_MOSI: U3.17 (PA7); also elsewhere on the board
SPI1_SCK: U3.15 (PA5); also elsewhere on the board
VBAT_SENSE: U3.10 (PA0); also elsewhere on the board

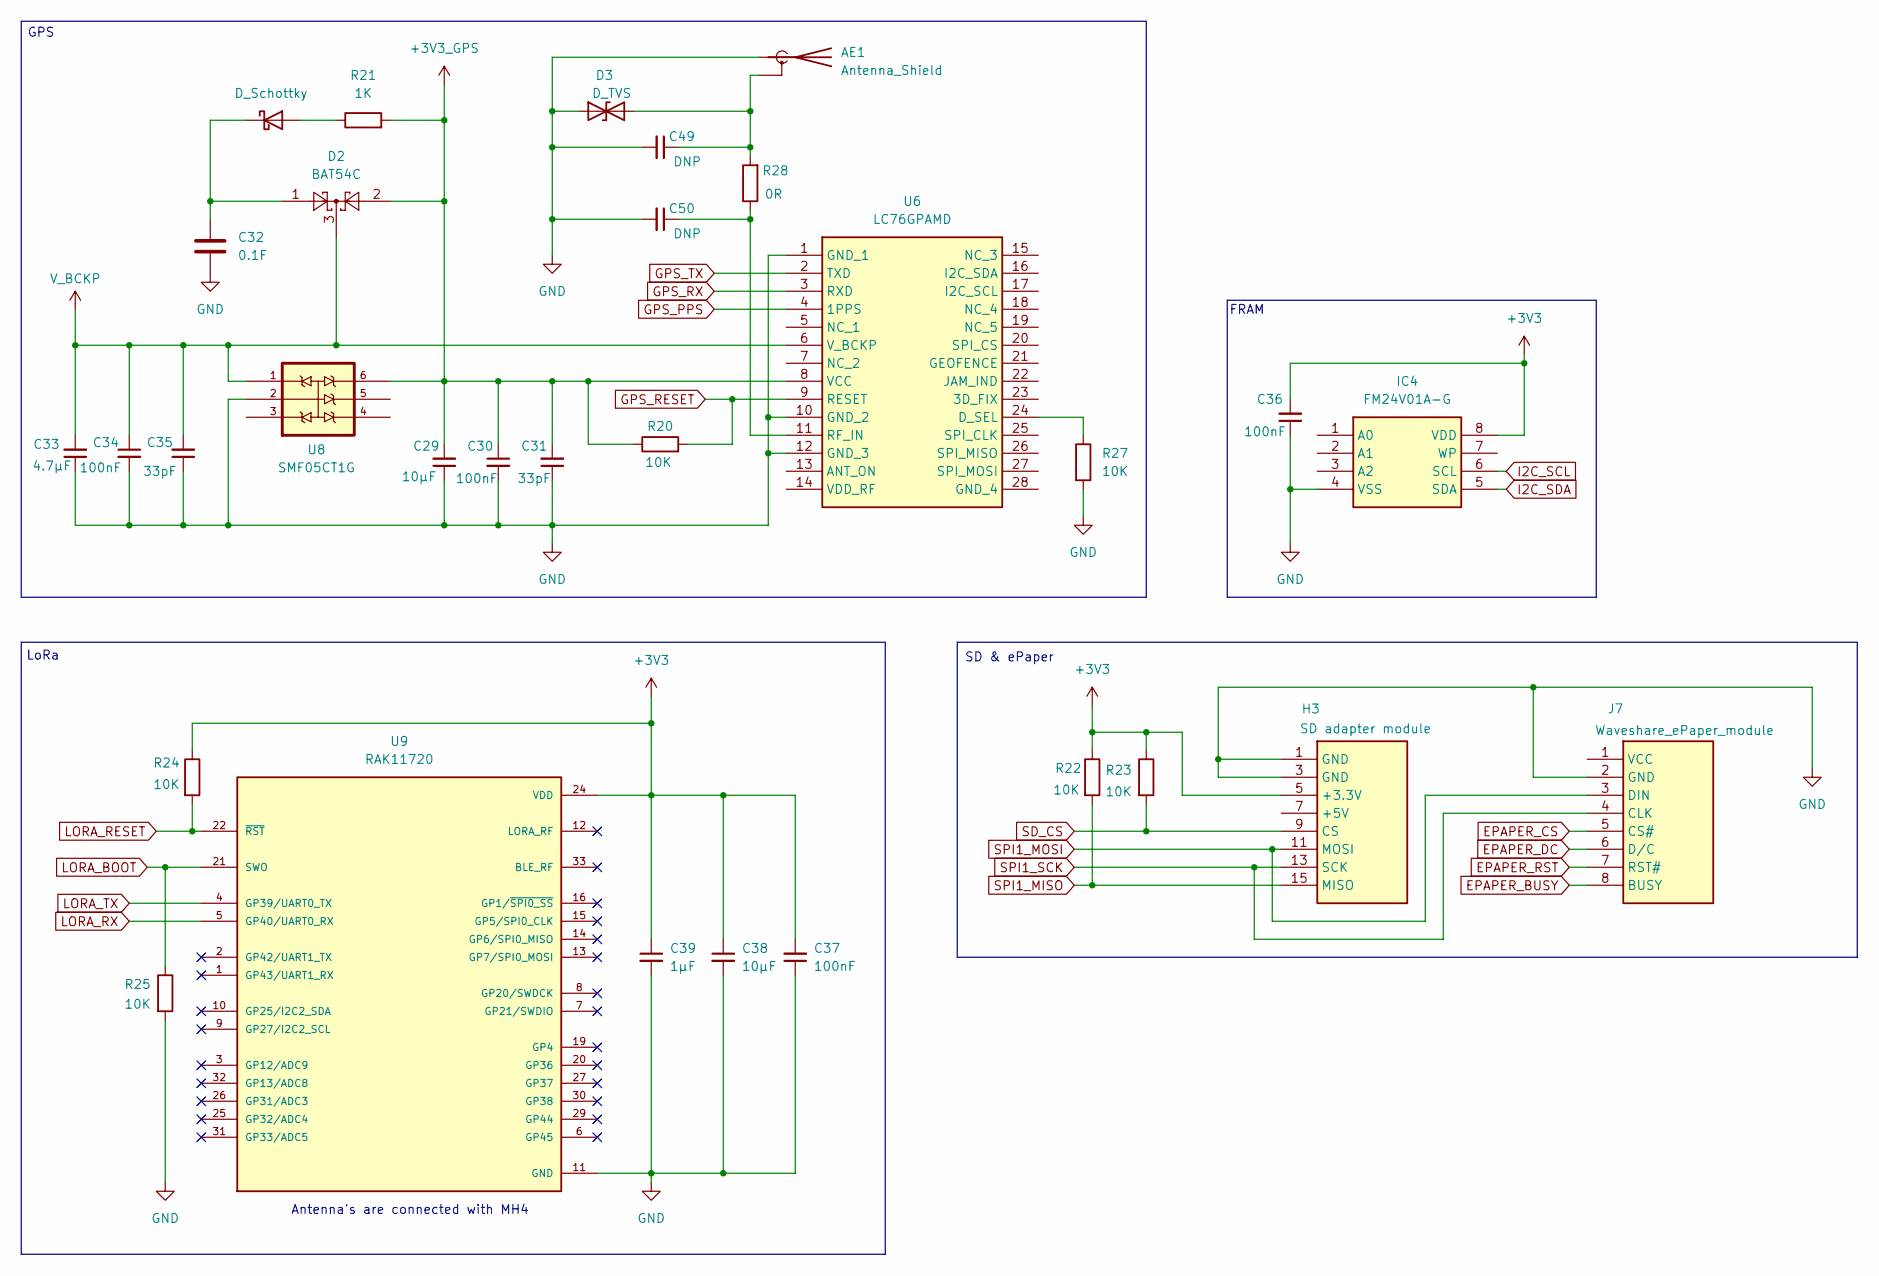
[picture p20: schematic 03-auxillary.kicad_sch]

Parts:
AE1: Antenna_Shield; U.FL_Hirose_U.FL-R-SMT-1_Vertical
C29, C38: 10µF; C_0603_1608Metric_Pad1.08x0.95mm_HandSolder
C30, C34, C36, C37: 100nF; C_0603_1608Metric_Pad1.08x0.95mm_HandSolder
C31, C35: 33pF; C_0603_1608Metric_Pad1.08x0.95mm_HandSolder
C32: 0.1F; C_1210_3225Metric_Pad1.33x2.70mm_HandSolder
C33: 4.7µF; C_0603_1608Metric_Pad1.08x0.95mm_HandSolder
C39: 1µF; C_0603_1608Metric_Pad1.08x0.95mm_HandSolder
C49, C50: DNP; C_0402_1005Metric_Pad0.74x0.62mm_HandSolder
D2: BAT54C; SOT-23_Handsoldering
D3: D_TVS; D_SOD-923
D4: D_Schottky; D_SOD-523
H3: SD adapter module; PinHeader_2x08_P2.54mm_Vertical
IC4: FM24V01A-G; SOIC127P602X173-8N; Mouser Part Number 727-FM24V01A-G
J7: Waveshare_ePaper_module; JST_PH_B8B-PH-K_1x08_P2.00mm_Vertical
R20, R22, R23, R24, R25, R27: 10K; R_0603_1608Metric_Pad0.98x0.95mm_HandSolder
R21: 1K; R_0603_1608Metric_Pad0.98x0.95mm_HandSolder
R28: 0R; R_0402_1005Metric_Pad0.72x0.64mm_HandSolder
U6: LC76GPAMD; Mouser Part Number 277-LC76GPAMD
U8: SMF05CT1G; SOT65P210X110-6N
U9: RAK11720; XCVR_RAK11720; PARTREV 6/2/2023

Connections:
+3V3: C36.2, C37.2, C38.1, C39.1, H3.5 (+3.3V), H3.6 (+3.3V), IC4.8 (VDD), R22.1, R23.1, R24.1, U9.24 (VDD); also elsewhere on the board
+3V3_GPS: C29.2, C30.1, C31.2, D2.2, R20.1, R21.2, U6.8 (VCC), U8.6; also elsewhere on the board
EPAPER_BUSY: J7.8 (BUSY); also elsewhere on the board
EPAPER_CS: J7.5 (CS#); also elsewhere on the board
EPAPER_DC: J7.6 (D/C); also elsewhere on the board
EPAPER_RST: J7.7 (RST#); also elsewhere on the board
GND: AE1.1 (A), C29.1, C30.2, C31.1, C32.2, C33.1, C34.2, C35.1, C36.1, C37.1, C38.2, C39.2, C49.2, C50.2, D3.1 (A1), H3.1 (GND), H3.2 (GND), H3.3 (GND), H3.4 (GND), IC4.4 (VSS), J7.2 (GND), R25.2, R27.2, U6.1 (GND_1), U6.10 (GND_2), U6.12 (GND_3), U8.2, U9.11 (GND), U9.17 (GND), U9.18 (GND), U9.23 (GND), U9.28 (GND), U9.34 (GND); also elsewhere on the board
GPS_PPS: U6.4 (1PPS); also elsewhere on the board
GPS_RESET: R20.2, U6.9 (RESET); also elsewhere on the board
GPS_RX: U6.3 (RXD); also elsewhere on the board
GPS_TX: U6.2 (TXD); also elsewhere on the board
I2C_SCL: IC4.6 (SCL); also elsewhere on the board
I2C_SDA: IC4.5 (SDA); also elsewhere on the board
LORA_BOOT: R25.1, U9.21 (SWO); also elsewhere on the board
LORA_RESET: R24.2, U9.22 (~RST); also elsewhere on the board
LORA_RX: U9.5 (GP40/UART0_RX); also elsewhere on the board
LORA_TX: U9.4 (GP39/UART0_TX); also elsewhere on the board
unnamed: AE1.2 (Shield), C49.1, D3.2 (A2), R28.2
unnamed: D4.2 (A), R21.1
unnamed: C32.1, D2.1, D4.1 (K)
unnamed: R27.1, U6.24 (D_SEL)
unnamed: C50.1, R28.1, U6.11 (RF_IN)
SD_CS: H3.9 (CS), H3.10 (CS), R23.2; also elsewhere on the board
SPI1_MISO: H3.15 (MISO), H3.16 (MISO), R22.2; also elsewhere on the board
SPI1_MOSI: H3.11 (MOSI), H3.12 (MOSI), J7.3 (DIN); also elsewhere on the board
SPI1_SCK: H3.13 (SCK), H3.14 (SCK), J7.4 (CLK); also elsewhere on the board
V_BCKP: C33.2, C34.1, C35.2, D2.3, U6.6 (V_BCKP), U8.1

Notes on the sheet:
Antenna's are connected with MH4
LoRa
SD & ePaper
GPS
FRAM

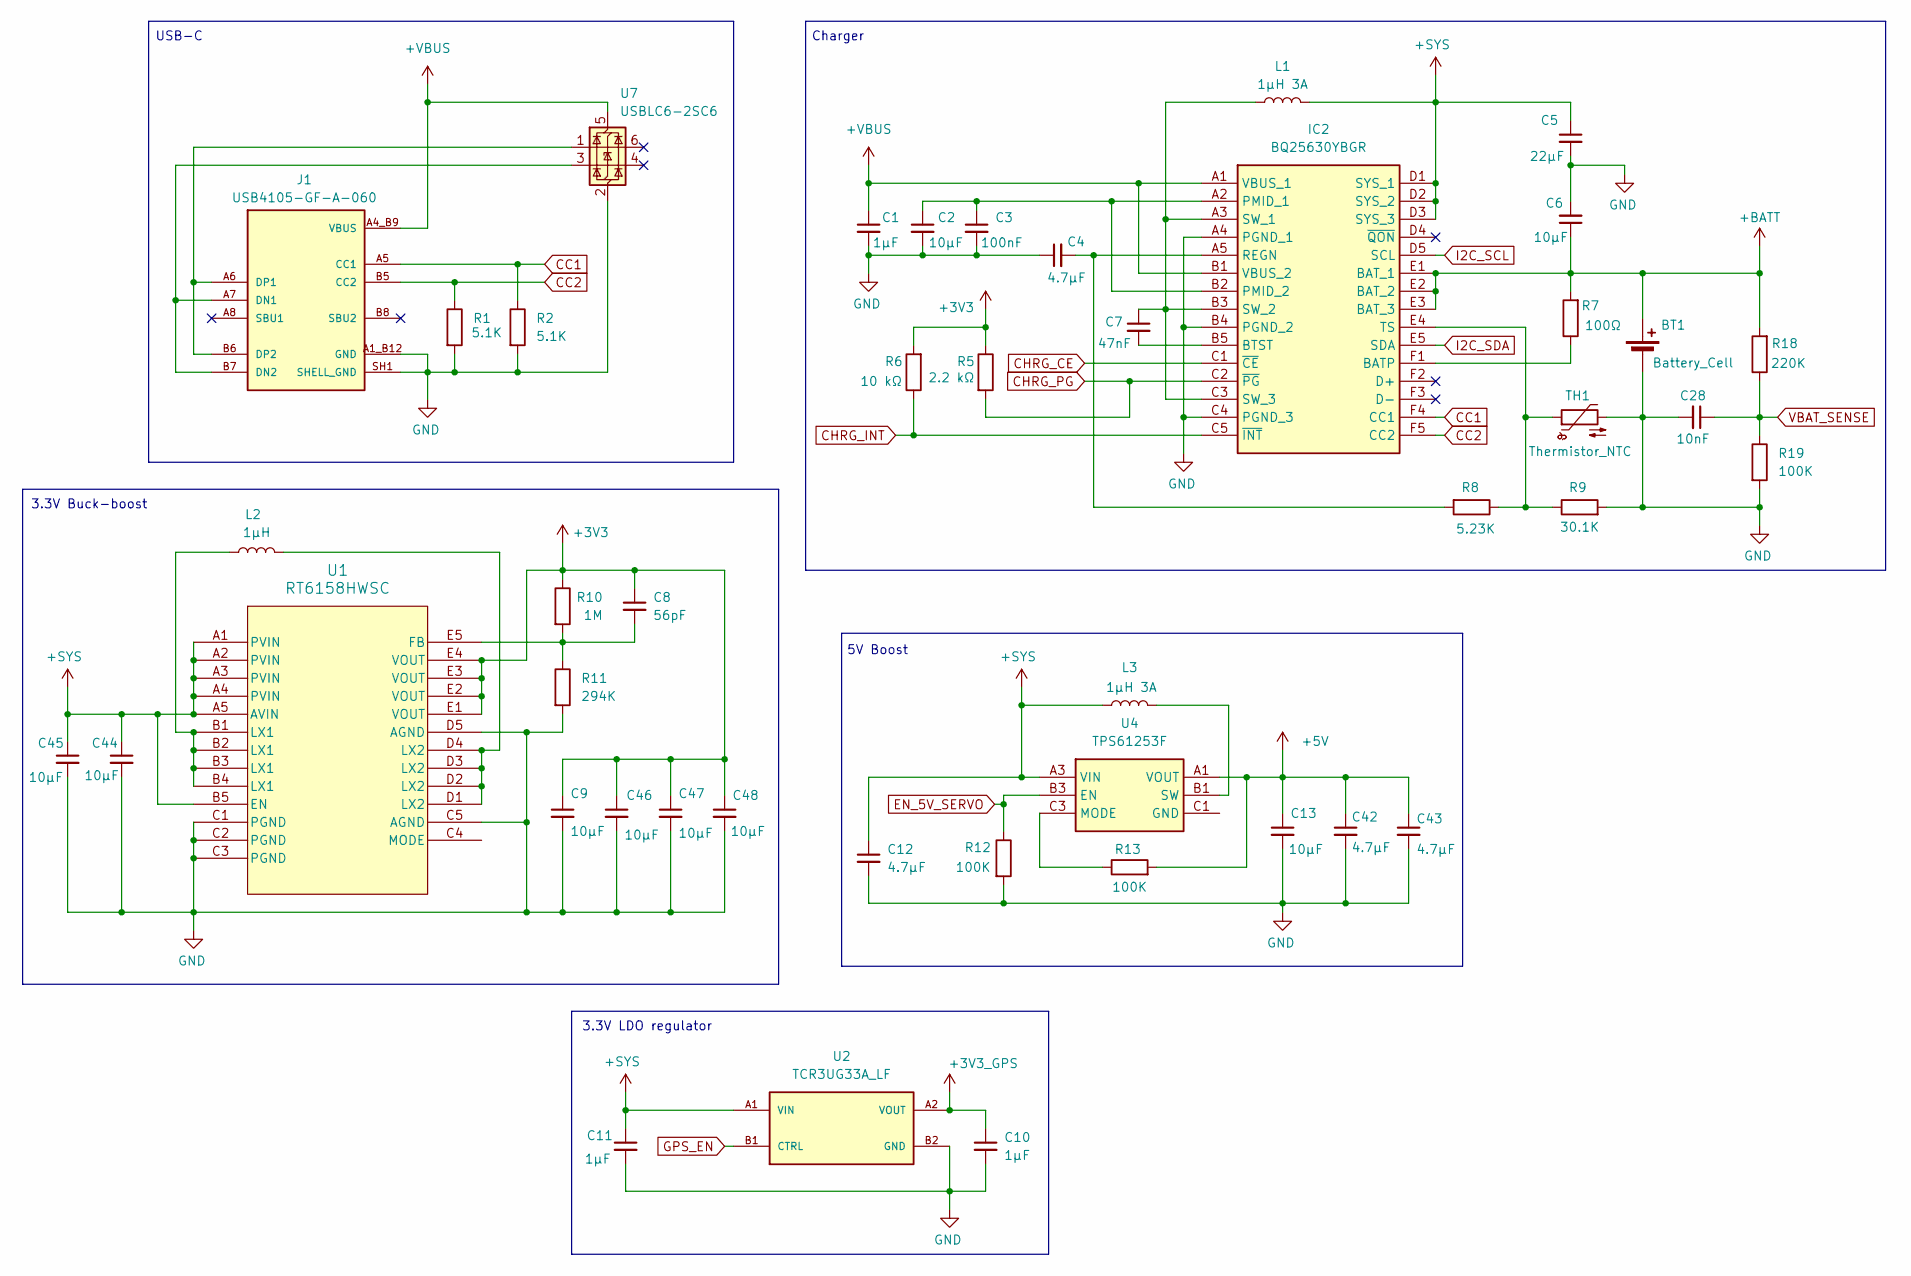
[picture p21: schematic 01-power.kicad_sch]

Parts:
BT1: Battery_Cell; JST_PH_S2B-PH-K_1x02_P2.00mm_Horizontal
C1, C10, C11: 1µF; C_0603_1608Metric_Pad1.08x0.95mm_HandSolder
C2, C6, C9, C13, C44, C45, C46, C47, C48: 10µF; C_0603_1608Metric_Pad1.08x0.95mm_HandSolder
C3: 100nF; C_0603_1608Metric_Pad1.08x0.95mm_HandSolder
C4, C12, C42, C43: 4.7µF; C_0603_1608Metric_Pad1.08x0.95mm_HandSolder
C5: 22µF; C_0805_2012Metric_Pad1.18x1.45mm_HandSolder
C7: 47nF; C_0603_1608Metric_Pad1.08x0.95mm_HandSolder
C8: 56pF; C_0603_1608Metric_Pad1.08x0.95mm_HandSolder
C28: 10nF; C_0603_1608Metric_Pad1.08x0.95mm_HandSolder
IC2: BQ25630YBGR; BGA30C40P5X6_221X271X50; Manufacturer_Part_Number BQ25630YBGR
J1: USB4105-GF-A-060; USB_C_Receptacle_GCT_USB4105-xx-A_16P_TopMnt_Horizontal
L1, L3: 1µH 3A; MAKK2520H1R0M
L2: 1µH; MAKK2520H1R0M
R1, R2: 5.1K; R_0603_1608Metric_Pad0.98x0.95mm_HandSolder
R5: 2.2 kΩ; R_0603_1608Metric_Pad0.98x0.95mm_HandSolder
R6: 10 kΩ; R_0603_1608Metric_Pad0.98x0.95mm_HandSolder
R7: 100Ω; R_0603_1608Metric_Pad0.98x0.95mm_HandSolder
R8: 5.23K; R_0603_1608Metric_Pad0.98x0.95mm_HandSolder
R9: 30.1K; R_0603_1608Metric_Pad0.98x0.95mm_HandSolder
R10: 1M; R_0402_1005Metric
R11: 294K; R_0402_1005Metric
R12, R13, R19: 100K; R_0603_1608Metric_Pad0.98x0.95mm_HandSolder
R18: 220K; R_0603_1608Metric_Pad0.98x0.95mm_HandSolder
TH1: Thermistor_NTC; C_Disc_D3.4mm_W2.1mm_P2.50mm
U1: RT6158HWSC; BGA25_RT6158H_RIT-M
U2: TCR3UG33A_LF; BGA4N35P2X2_64X64X33; PARTREV 2021-10-28
U4: TPS61253F; BGA9N40P3X3_119X128X62N; Mouser Part Number 727-FM24V01A-G
U7: USBLC6-2SC6; SOT-23-6_Handsoldering

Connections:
+3V3: C8.1, C9.1, C46.1, C47.1, C48.1, R5.1, R6.2, R10.1, U1.E1 (VOUT), U1.E2 (VOUT), U1.E3 (VOUT), U1.E4 (VOUT); also elsewhere on the board
+3V3_GPS: C10.1, U2.A2 (VOUT); also elsewhere on the board
+BATT: BT1.1 (+), C6.1, IC2.E1 (BAT_1), IC2.E2 (BAT_2), IC2.E3 (BAT_3), R7.2, R18.2
+SYS: C5.1, C11.1, C12.1, C44.1, C45.1, IC2.D1 (SYS_1), IC2.D2 (SYS_2), IC2.D3 (SYS_3), L1.2, L3.1, U1.A1 (PVIN), U1.A2 (PVIN), U1.A3 (PVIN), U1.A4 (PVIN), U1.A5 (AVIN), U1.B5 (EN), U2.A1 (VIN), U4.A3 (VIN)
+VBUS: C1.1, IC2.A1 (VBUS_1), IC2.B1 (VBUS_2), J1.A4_B9 (VBUS), J1.B4_A9 (VBUS), U7.5 (VBUS)
CC1: IC2.F4 (CC1), J1.A5 (CC1), R2.1
CC2: IC2.F5 (CC2), J1.B5 (CC2), R1.1
CHRG_CE: IC2.C1 (~CE); also elsewhere on the board
CHRG_INT: IC2.C5 (~INT), R6.1; also elsewhere on the board
CHRG_PG: IC2.C2 (~PG), R5.2; also elsewhere on the board
EN_5V_SERVO: R12.1, U4.B3 (EN); also elsewhere on the board
GND: BT1.2 (-), C1.2, C2.2, C3.2, C4.1, C5.2, C6.2, C9.2, C10.2, C11.2, C12.2, C13.2, C28.2, C42.2, C43.2, C44.2, C45.2, C46.2, C47.2, C48.2, IC2.A4 (PGND_1), IC2.B4 (PGND_2), IC2.C4 (PGND_3), J1.A1_B12 (GND), J1.B1_A12 (GND), J1.SH1 (SHELL_GND), J1.SH2 (SHELL_GND), J1.SH3 (SHELL_GND), J1.SH4 (SHELL_GND), R1.2, R2.2, R9.2, R11.2, R12.2, R19.2, TH1.2, U1.C1 (PGND), U1.C2 (PGND), U1.C3 (PGND), U1.C5 (AGND), U1.D5 (AGND), U2.B2 (GND), U7.2 (GND); also elsewhere on the board
GPS_EN: U2.B1 (CTRL); also elsewhere on the board
I2C_SCL: IC2.D5 (SCL); also elsewhere on the board
I2C_SDA: IC2.E5 (SDA); also elsewhere on the board
unnamed: IC2.F1 (BATP), R7.1
unnamed: C7.2, IC2.B5 (BTST)
unnamed: C2.1, C3.1, IC2.A2 (PMID_1), IC2.B2 (PMID_2)
unnamed: C4.2, IC2.A5 (REGN), R8.2
unnamed: C7.1, IC2.A3 (SW_1), IC2.B3 (SW_2), IC2.C3 (SW_3), L1.1
unnamed: IC2.E4 (TS), R8.1, R9.1, TH1.1
unnamed: J1.A7 (DN1), J1.B7 (DN2), U7.3 (I/O2)
unnamed: J1.A6 (DP1), J1.B6 (DP2), U7.1 (I/O1)
unnamed: L2.1, U1.B1 (LX1), U1.B2 (LX1), U1.B3 (LX1), U1.B4 (LX1)
unnamed: L2.2, U1.D1 (LX2), U1.D2 (LX2), U1.D3 (LX2), U1.D4 (LX2)
unnamed: L3.2, U4.B1 (SW), U4.B2 (SW)
unnamed: C8.2, R10.2, R11.1, U1.E5 (FB)
unnamed: U4.C1 (GND), U4.C2 (GND)
unnamed: R13.1, U4.C3 (MODE)
VBAT_SENSE: C28.1, R18.1, R19.1; also elsewhere on the board

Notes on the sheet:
3.3V Buck-boost
USB-C
3.3V LDO regulator
5V Boost
Charger

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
Board: 4 copper layers, 114 parts (48 on the bottom side), 71 nets, no tracks yet.

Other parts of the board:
H10, H11, H12, H13: MountingHole_3.2mm_M3_Pad

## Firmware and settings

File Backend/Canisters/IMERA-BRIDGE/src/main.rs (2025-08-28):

use basic_solana::{
    client, solana_wallet::SolanaWallet, spl, state::init_state, validate_caller_not_anonymous,
    InitArg,
};
use candid::{Nat, Principal};
use ic_cdk::{init, post_upgrade, update};
use num::ToPrimitive;
use sol_rpc_client::nonce::nonce_from_account;
use sol_rpc_types::{GetAccountInfoEncoding, GetAccountInfoParams, TokenAmount};
use solana_hash::Hash;
use solana_message::Message;
use solana_pubkey::Pubkey;
use solana_system_interface::instruction;
use solana_transaction::Transaction;
use std::str::FromStr;

#[init]
pub fn init(init_arg: InitArg) {
    init_state(init_arg)
}

#[post_upgrade]
fn post_upgrade(init_arg: Option<InitArg>) {
    if let Some(init_arg) = init_arg {
        init_state(init_arg)
    }
}

#[update]
pub async fn solana_account(owner: Option<Principal>) -> String {
    let owner = owner.unwrap_or_else(validate_caller_not_anonymous);
    let wallet = SolanaWallet::new(owner).await;
    wallet.solana_account().to_string()
}

#[update]
pub async fn nonce_account(owner: Option<Principal>) -> sol_rpc_types::Pubkey {
    let owner = owner.unwrap_or_else(validate_caller_not_anonymous);
    let wallet = SolanaWallet::new(owner).await;
    wallet.derived_nonce_account().as_ref().into()
}

#[update]
pub async fn associated_token_account(owner: Option<Principal>, mint_account: String) -> String {
    let owner = owner.unwrap_or_else(validate_caller_not_anonymous);
    let wallet = SolanaWallet::new(owner).await;
    let mint = Pubkey::from_str(&mint_account).unwrap();
    spl::get_associated_token_address(
        wallet.solana_account().as_ref(),
        &mint,
        &get_account_owner(&mint).await,
    )
    .to_string()
}

#[update]
pub async fn get_balance(account: Option<String>) -> Nat {
    let account = account.unwrap_or(solana_account(None).await);
    let public_key = Pubkey::from_str(&account).unwrap();
    let balance = client()
        .get_balance(public_key)
        .send()
        .await
        .expect_consistent()
        .expect("Call to `getBalance` failed");
    Nat::from(balance)
}

#[update]
pub async fn get_nonce(account: Option<sol_rpc_types::Pubkey>) -> sol_rpc_types::Hash {
    let account = account.unwrap_or(nonce_account(None).await);

    // Fetch the account info with the data encoded in base64 format
    let mut params = GetAccountInfoParams::from_pubkey(account);
    params.encoding = Some(GetAccountInfoEncoding::Base64);
    let account = client()
        .get_account_info(params)
        .send()
        .await
        .expect_consistent()
        .expect("Call to `getAccountInfo` failed")
        .expect("Account not found for given pubkey");

    // Extract the nonce from the account data
    nonce_from_account(&account)
        .expect("Failed to extract durable nonce from account data")
        .into()
}

#[update]
pub async fn get_spl_token_balance(account: Option<String>, mint_account: String) -> TokenAmount {
    let account = account.unwrap_or(associated_token_account(None, mint_account).await);
    let public_key = Pubkey::from_str(&account).unwrap();
    client()
        .get_token_account_balance(public_key)
        .send()
        .await
        .expect_consistent()
        .expect("Call to `getTokenAccountBalance` failed")
        .into()
}

#[update]
pub async fn create_nonce_account(owner: Option<Principal>) -> String {
    let client = client();

    let owner = owner.unwrap_or_else(validate_caller_not_anonymous);
    let wallet = SolanaWallet::new(owner).await;

    let payer = wallet.solana_account();
    let nonce_account = wallet.derived_nonce_account();

    if let Some(_account) = client
        .get_account_info(*nonce_account.as_ref())
        .send()
        .await
        .expect_consistent()
        .unwrap_or_else(|e| {
            panic!(
                "Call to `getAccountInfo` for {} failed: {e}",
                nonce_account.as_ref()
            )
        })
    {
        ic_cdk::println!(
            "[create_nonce_account]: Account {} already exists. Skipping creation of nonce account",
            nonce_account.as_ref()
        );
        return nonce_account.as_ref().to_string();
    }

    let instructions = instruction::create_nonce_account(
        payer.as_ref(),
        nonce_account.as_ref(),
        payer.as_ref(),
        1_500_000,
    );

    let message = Message::new_with_blockhash(
        instructions.as_slice(),
        Some(payer.as_ref()),
        &client.estimate_recent_blockhash().send().await.unwrap(),
    );

    let signatures = vec![
        payer.sign_message(&message).await,
        nonce_account.sign_message(&message).await,
    ];

    let transaction = Transaction {
        message,
        signatures,
    };

    client
        .send_transaction(transaction)
        .send()
        .await
        .expect_consistent()
        .expect("Call to `sendTransaction` failed");

    nonce_account.as_ref().to_string()
}

#[update]
pub async fn create_associated_token_account(
    owner: Option<Principal>,
    mint_account: String,
) -> String {
    let client = client();

    let owner = owner.unwrap_or_else(validate_caller_not_anonymous);
    let wallet = SolanaWallet::new(owner).await;

    let payer = wallet.solana_account();
    let mint = Pubkey::from_str(&mint_account).unwrap();

    let (associated_token_account, instruction) = spl::create_associated_token_account_instruction(
        payer.as_ref(),
        payer.as_ref(),
        &mint,
        &get_account_owner(&mint).await,
    );

    if let Some(_account) = client
        .get_account_info(associated_token_account)
        .with_encoding(GetAccountInfoEncoding::Base64)
        .send()
        .await
        .expect_consistent()
        .unwrap_or_else(|e| {
            panic!("Call to `getAccountInfo` for {associated_token_account} failed: {e}")
        })
    {
        ic_cdk::println!(
            "[create_associated_token_account]: Account {} already exists. Skipping creation of associated token account",
            associated_token_account
        );
        return associated_token_account.to_string();
    }

    let message = Message::new_with_blockhash(
        &[instruction],
        Some(payer.as_ref()),
        &client.estimate_recent_blockhash().send().await.unwrap(),
    );

    let signatures = vec![payer.sign_message(&message).await];
    let transaction = Transaction {
        message,
        signatures,
    };

    client
        .send_transaction(transaction)
        .send()
        .await
        .expect_consistent()
        .expect("Call to `sendTransaction` failed")
        .to_string();

    associated_token_account.to_string()
}

#[update]
pub async fn send_sol(owner: Option<Principal>, to: String, amount: Nat) -> String {
    let client = client();

    let owner = owner.unwrap_or_else(validate_caller_not_anonymous);
    let wallet = SolanaWallet::new(owner).await;

    let recipient = Pubkey::from_str(&to).unwrap();
    let payer = wallet.solana_account();
    let amount = amount.0.to_u64().unwrap();

    ic_cdk::println!(
        "Instruction to transfer {amount} lamports from {} to {recipient}",
        payer.as_ref()
    );
    let instruction = instruction::transfer(payer.as_ref(), &recipient, amount);

    let message = Message::new_with_blockhash(
        &[instruction],
        Some(payer.as_ref()),
        &client.estimate_recent_blockhash().send().await.unwrap(),
    );
    let signatures = vec![payer.sign_message(&message).await];
    let transaction = Transaction {
        message,
        signatures,
    };

    client
        .send_transaction(transaction)
        .send()
        .await
        .expect_consistent()
        .expect("Call to `sendTransaction` failed")
        .to_string()
}

#[update]
pub async fn send_sol_with_durable_nonce(
    owner: Option<Principal>,
    to: String,
    amount: Nat,
) -> String {
    let client = client();

    let owner = owner.unwrap_or_else(validate_caller_not_anonymous);
    let wallet = SolanaWallet::new(owner).await;

    let recipient = Pubkey::from_str(&to).unwrap();
    let payer = wallet.solana_account();
    let amount = amount.0.to_u64().unwrap();
    let nonce_account = wallet.derived_nonce_account();

    let instructions = &[
        instruction::advance_nonce_account(nonce_account.as_ref(), payer.as_ref()),
        instruction::transfer(payer.as_ref(), &recipient, amount),
    ];

    let blockhash = Hash::from(get_nonce(Some(nonce_account.as_ref().into())).await);

    let message = Message::new_with_blockhash(instructions, Some(payer.as_ref()), &blockhash);
    let signatures = vec![payer.sign_message(&message).await];
    let transaction = Transaction {
        message,
        signatures,
    };

    client
        .send_transaction(transaction)
        .send()
        .await
        .expect_consistent()
        .expect("Call to `sendTransaction` failed")
        .to_string()
}

#[update]
pub async fn send_spl_token(
    owner: Option<Principal>,
    mint_account: String,
    to: String,
    amount: Nat,
) -> String {
    let client = client();

    let owner = owner.unwrap_or_else(validate_caller_not_anonymous);
    let wallet = SolanaWallet::new(owner).await;

    let payer = wallet.solana_account();
    let recipient = Pubkey::from_str(&to).unwrap();
    let mint = Pubkey::from_str(&mint_account).unwrap();
    let amount = amount.0.to_u64().unwrap();

    let token_program = get_account_owner(&mint).await;

    let from = spl::get_associated_token_address(payer.as_ref(), &mint, &token_program);
    let to = spl::get_associated_token_address(&recipient, &mint, &token_program);

    let instruction = spl::transfer_instruction_with_program_id(
        &from,
        &to,
        payer.as_ref(),
        amount,
        &token_program,
    );

    let message = Message::new_with_blockhash(
        &[instruction],
        Some(payer.as_ref()),
        &client.estimate_recent_blockhash().send().await.unwrap(),
    );
    let signatures = vec![payer.sign_message(&message).await];
    let transaction = Transaction {
        message,
        signatures,
    };

    client
        .send_transaction(transaction)
        .send()
        .await
        .expect_consistent()
        .expect("Call to `sendTransaction` failed")
        .to_string()
}

async fn get_account_owner(account: &Pubkey) -> Pubkey {
    let owner = client()
        .get_account_info(*account)
        .with_encoding(GetAccountInfoEncoding::Base64)
        .send()
        .await
        .expect_consistent()
        .expect("Call to `getAccountInfo` failed")
        .unwrap_or_else(|| panic!("Account not found for pubkey `{account}`"))
        .owner;
    Pubkey::from_str(&owner).unwrap()
}

fn main() {}

#[test]
fn check_candid_interface_compatibility() {
    use candid_parser::utils::{service_equal, CandidSource};

    candid::export_service!();

    let new_interface = __export_service();

    // check the public interface against the actual one
    let old_interface = std::path::PathBuf::from(std::env::var("CARGO_MANIFEST_DIR").unwrap())
        .join("basic_solana.did");

    service_equal(
        CandidSource::Text(dbg!(&new_interface)),
        CandidSource::File(old_interface.as_path()),
    )
    .unwrap();
}

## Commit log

2024-10-15 Update MKRWAN_PAYLOAD_CUSTOM_BIKERA.ino
    workloads, private key generation or input added. And device check by calculating public key
2024-10-16 Update MKRWAN_PAYLOAD_CUSTOM_BIKERA.ino
    Crypto chip setup part, input private key (have a copy of the wallet address in case the chip dies or the lock gets destroyed the funds are still accessible by generating a mobile wallet with the keys, danger of having the key copied) or have it generated in the chip, if generated in chip ( when the chip is lost or tampered with the funds will be lost the funds will need to be send more often of the lock's wallet address; higher transactional costs and maybe lose of some funds if lock gets damaged)
2024-10-18 Update MKRWAN_PAYLOAD_CUSTOM_BIKERA.ino
    LFG for this iteration, now just make the arduino send random numbers that should be locked as coordinates with assigned Public key encryption.
2024-10-20 Update MKRWAN_PAYLOAD_CUSTOM_BIKERA.ino
    Setup, entering stuff, probably should write this to EEPROM; in case somebody just start cracking open the locks and replaces SD-cards with malicious ones, depends on if the price of an SD card is worth the effort..
2024-10-23 Update MKRWAN_PAYLOAD_CUSTOM_BIKERA.ino
    debugged and compiles.
    let's take this for a testdrive. Next is head-on with the configuration file. this is now set to TLS but it is not completely similar on which slots to lock and which to use for this application
2024-10-24 Update MKRWAN_PAYLOAD_CUSTOM_BIKERA.ino
    getting the setup to run, serial monitor conversion needs to be looked at. trying other desktop environment maybe this is due to Debian12 and the UART interface. let's see If this isn't a problem on windows...
2024-10-25 Rename MKRWAN_PAYLOAD_CUSTOM_BIKERA.ino to MKRWAN_PAYLOAD_CUSTOM_BIKERA_MKRWAN1310.ino
    this is the MKRWAN firmware prototype, later in development the Arduino NANO ble 33 IOT will also be used and after setting these two type boards up to run firmware for Bikera network ESP32 will be t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
2025-08-20 front end webpage online added correctly twice
    [Blocks.csv, mining_rewards.csv]
2025-08-20 front end webpage added services
    [Blocks.csv, mining_rewards.csv]
2025-08-24 Powerpoint presentation
2025-08-25 Powerpoint presentation v2
2026-02-04 Document voor componenten, STM32L0, L1 en L4 vergeleken
    [Blocks.csv, mining_rewards.csv]
2026-02-05 STM32 prijzen en voorstel
2026-03-24 BMS lader en USB stromen
2026-03-26 BMS converters
2026-03-27 BMS 5V boost
2026-03-31 5V boost
2026-04-01 5V boost en accelerometer
2026-04-19 Kleurled en hall effect sensor
2026-04-21 Architectuurschema FRAM en accelerometer
2026-04-22 Architectuurschema BMS
2026-04-28 LED, GPS antenne
2026-04-29 Architectuurschema LED en GPS antenne
2026-04-29 Componenten bijgewerkt en architectuurschema hall sensors
2026-05-06 KiCad project aangemaakt
    [Bikera PCB prototype.kicad_pcb, Bikera PCB prototype.kicad_sch]
2026-05-07 KiCad symbolen geïmporteerd
    [Bikera PCB prototype.kicad_sch]
2026-05-12 KiCad symbolen basiscomponenten
    [Bikera PCB prototype.kicad_sch]
2026-05-14 3.3V buck-boost: RT6150B
2026-05-16 schema design KiCAD layout guide
2026-05-16 KiCAD generated pages
    dit zijn autogenerated pages, dienen nog leesbaar gemaakt te worden
    [01_power.kicad_sch, 02_mcu.kicad_sch, 03_radio.kicad_sch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]
2026-05-16 schema uitwerkingsgids
    beschrijving van hoe de belegging is per pagina
2026-05-16 3.3V buck-boost veranderd: RT6158AWSC
2026-05-17 Architectuurschema BMS en SD bijgewerkt
2026-06-22 Schema van Eli
    [01-power.kicad_sch, 01_power.kicad_sch, 02-mcu.kicad_sch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]
2026-06-25 Add Kicad_v2 folder (devboard + prototype schematics, libraries)
    [01-power.kicad_sch, 02-mcu.kicad_sch, 03-radio.kicad_sch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]
2026-06-29 KiCad MCU schema gecontroleerd
    [01-power.kicad_sch, 02-mcu.kicad_sch]
2026-07-01 KiCad Power schema herschikt
    [01-power_bak.kicad_sch]
2026-07-03 KiCad GPS en LoRa herschikt en gecombineerd
    [01-power.kicad_sch, 02-mcu.kicad_sch, 03-auxillary.kicad_sch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]
2026-07-05 PCB layout claude
    [Bikera PCB devboard_GENERATED_BACKUP.kicad_pcb]
2026-07-06 PCB routing claude (deel 1)
    [01-power.kicad_sch, 02-mcu.kicad_sch, 03-auxillary.kicad_sch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]
2026-07-06 PCB routing claude (deel 2)
    [Bikera PCB devboard_ROUTED.kicad_pcb]
2026-07-14 KiCad PCB silkscreen aangepast
    [Bikera PCB devboard.kicad_pcb]
2026-08-27 Update laatste controle schema
    [01-power.kicad_sch, 03-auxillary.kicad_sch]
